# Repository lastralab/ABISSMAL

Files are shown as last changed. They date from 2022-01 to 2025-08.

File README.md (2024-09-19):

<h1>ABISSMAL: Automated Behavioral tracking by Integrating Sensors that Survey Movements Around a target Location
</h1>
<b>Developers:</b><br>
Tania Molina: <span style="pointer-events:none;">tanismo&#64;l<span style="display:none"></span>astralab.com</span><br>
Grace Smith-Vidaurre, PhD: <span style="pointer-events:none">gsvidaurre[at]<span style="display:none"></span>gmail.com</span>
<br>
<br>
<a href="https://lastralab.github.io/ABISSMAL/site/" target="_blank">Documentation</a><br />
<a href="https://github.com/lastralab/ABISSMAL/wiki" target="_blank">Project Wiki</a>
<br />

<h2>Tracking System Overview</h2>
ABISSMAL is a hardware and software platform for automated behavioral tracking with built-in system monitoring and error logging. ABISSMAL also provides the capacity to make behavioral inferences by integrating data across multiple types of movement sensors. We tested the tracking system by tracking parental care behaviors with captive zebra finches that raised young birds over 50 days. See the accompanying methods manuscript for more detailed information about ABISSMAL. Our Wiki page has detailed information about how to set up and build hardware, as well as software installation and troubleshooting.

<h2>Pre-requisites</h2>
Please refer to our Wiki page <a href="https://github.com/lastralab/Abissmal/wiki/2.-Set-up-Raspberry-Pi-and-tracking-system-software">Set up Raspberry Pi and tracking system</a> before proceeding. There are a few pre-requisites to consider before running the installation script.

<h2>Installing ABISSMAL</h2>
<br>

<pre>
           ____ _____  _____ _____ __  __          _      
     /\   |  _ \_   _|/ ____/ ____|  \/  |   /\   | |     
    /  \  | |_) || | | (___| (___ | \  / |  /  \  | |     
   / /\ \ |  _ < | |  \___ \\___ \| |\/| | / /\ \ | |     
  / ____ \| |_) || |_ ____) |___) | |  | |/ ____ \| |____ 
 /_/    \_\____/_____|_____/_____/|_|  |_/_/    \_\______|

</pre>

<ol>
<li>Clone this repository to the Pi by running <pre>git clone https://github.com/lastralab/Abissmal.git</pre></li>
<li>From the root directory `/path/to/Abissmal/` run the following commands to install and run the ABISSMAL tracking system:</li>

   <ol>

   <li>Initiate the installation script, which will prompt you to enter information <pre>sudo bash run_install.sh</pre></li>
   <li>Enter your Pi password (we strongly recommend setting a password for your Raspberry Pi)</li>
   <li>When prompted, insert the additional ABISSMAL setup information accordingly</li>
   <li>The Pi will restart automatically to apply changes</li>
   <li>If you are using an ssh connection to connect to the Pi, then you will need to <a href="https://github.com/lastralab/Abissmal/wiki/5.-Troubleshooting">mount the external hard drive</a></li>
   </ol>
<li>Run command to initiate ABISSMAL and start collecting data (wihout sudo) <pre>bash Main.sh</pre></li>
<ol>
              <li>Follow instructions to setup the system accordingly</li>
   </ol>
</ol>
<br>

<h2>File Structure Overview</h2>
This repository holds the following directories and files. See the README files in each directory below for more detailed information:

<h3>3D</h3> A directory that holds 3D-printing designs for customized hardware in .stl format. Some of these files were used in earlier versions of ABISSMAL (RFID antenna holder) and are not currently used.

<h3>Modules</h3> A directory that holds software modules in Python 3 and the bash shell for automated data collection and system monitoring, as well as software for error logging. 

<h3>R</h3> A directory that contains a series of computational analyses as R functions, as well as code for unit-testing these functions.

<h3>Video Concatenation</h3> A directory that holds scripts for video concatenation with ffmpeg. This code was originally written to merge pre- and post-motion detection videos but is currently not used in ABISSMAL.

<h3>Main.sh</h3> The main script that initiates the ABISSMAL tracking system. See the Wiki page for more information.

<h3>cron.sh</h3> A script for task scheduling through cron jobs. This script is automatically used by ABISSMAL for data collection, system monitoring, and error logging to run continuously over time.

<h3>run_install.sh</h3> A script for automated installation of software dependencies, setting up cron jobs, and setting up automated text alerts through Twilio (optional, and users will need to create their own Twilio account). See the Wiki page for more information. 

<h3>Issue templates and other files</h3> The directory .github/ISSUE_TEMPLATE contains templates for different types of issues. The file .gitignore contains information about which files should be ignored (not tracked) by Git. The LICENSE file holds information about the open-access license for this repository. The README.md file holds this documentation for the main repository.

<br>

<h2>Additional Documentation</h2> The Issues tab holds open issues (bugs, new features, documentation update requests) that are in progress. You can also check out issues that were closed over time. The Projects tab has a Kanban-board style timeline that we are using for project management. The Wiki tab has 5 major sections with detailed documentation: <br />
<ol>
<li>Project Management</li>
<li>Setting up Raspberry Pi computers and ABISSMAL software</li> 
<li>Building a custom nest container</li> 
<li>Setting up sensors and other hardware</li> 
<li>Troubleshooting software and hardware issues</li>
</ol>
<h2>Citing ABISSMAL</h2>
If you are using or modifying one or more components of the ABISSMAL tracking system, then please cite the associated methods paper.

<br>
Paper citation: <br>
   Smith-Vidaurre, G., Molina, T., Jarvis, E.D., and Hobson, E.A. (2023). Automated tracking of avian parental care behavior. Submitted. EcoEvoRxiv preprint: https://doi.org/10.32942/X2Z60C

<h2>Reporting issues while using ABISSMAL</h2>
Anyone using ABISSMAL is welcome to post issues about bugs. We will do our best to respond and help with bugs, but our top priority will be to fix bugs that hinder data collection, system monitoring, error logging, data cleaning, and processing for the current version of ABISSMAL. 

<br>
This tracking system can be modified for different questions that require behavioral tracking, as well as for different species and/or research settings. Those interested in modifying the system for other purposes are welcome to do so independently, as long as you cite both the associated methods paper (currently a preprint), and this GitHub repository. Unless we have come to an agreement with collaborators who are adapting ABISSMAL, we will not have time to help individuals or research teams modify the tracking system. 

<h2>Contributing to ABISSMAL as an open-access tool</h2>
We have laid out collaborative roles for contributing to ABISSMAL code development in our <a href="https://github.com/lastralab/Abissmal/wiki/1.-Project-Management">Wiki Project Management page</a>. Contributing to ABISSMAL code development requires a local version of all components of the tracking system, including sensors and other hardware. As such, we are limiting ABISSMAL code contributions to the current developers (Tania Molina, Grace Smith-Vidaurre) and future members of the Smith-Vidaurre lab who will have access to the full set of hardware needed to test code. The lab may add additional layers of data collection and processing in future releases of ABISSMAL. We recommend that others who interested in modifying ABISSMAL fork this repository as a foundation for independent customization.

<h2>Ethics Statement</h2>
We developed and tested this tracking system with an institutional animal care and use (IACUC) protocol that was approved for captive zebra finches by Rockefeller University. If you plan to use this tracking system for research with live animals (captive or wild), then you must have your own approved institutional protocols and permits for ethical and responsible use of animals in research.

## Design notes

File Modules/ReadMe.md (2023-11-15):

<h1>Software documentation</h1>

<h2>System monitoring, error loggin, helper functions</h2>

**Description**: The files monitor.py and Backups.py are used for system monitoring and transferring data from the Pi to an external hard drive. Data transfers are performed at night for files created the day before. The file log.py is used for error logging, while helper.py contains functions for writing .csv files, setting up directories and logging, and setting up Twilio text alerts.

<h2>Infrared beam breakers (IRBB.py)</h2>

**Description**: IRBB.py contains code to run and collect data from two pairs of infrared beam breakers. Each beam breaker is a receiver - emitter pair. The code contained in IRBB.py was modified from from https://simonprickett.dev/using-a-break-beam-sensor-with-python-and-raspberry-pi/. The outer beam breaker pair is the first that will be broken when a bird enters the nest container (this pair sits in front of the RFID antenna). The inner beam breaker pair should be the first beam that is broken when a bird leaves the nest chamber (this pair sits behind the RFID antenna, looking into the container).

**Data structure**: The function `detect_beam_breaks_callback(BEAM_PIN, sensor_id)` returns the date and timestamp (HH:MM:SS) when an infrared beam is broken. The IRBB.py script returns the nest container identifier, the beam breaker identifier (outer or inner), and the year, month, day, and timestamp (HH:MM:SS) of the movement event. Each of these fields will be written out as a new line of a .csv file generated per day. The beam breakers detect beam breaking events through edge detection. This code sets up a pull up resistor to detect a falling edge that represents a beam break. Edges are detected by adding events rather than constant polling (to avoid missing edges). The bouncetime parameter ensures that only a single edge will be detected even when multiple beam break events occur close together in time.

<h2>Radio frequency identification (RFID.py)</h2>

**Description**: RFID.py contains code to run and collect data from a 125kHz CognIot radio frequency identification (RFID) reader on a Raspberry Pi computer. The original code to control the RFID reader was obtained from https://github.com/CognIot/RFID_125kHz. The RFID reader is connected to an external circular antenna that sits at the entrance of the tunnel of the nest container (before both infrared beam breakers). The reader has been set to read EM4102 passive integrated transponder (PIT) tags held in a plastic leg bands made in sizes appropriate for different songbird species. This RFID system allows for identification of the individuals that enter and leave the nest container. We set up the RFID antenna in the center of the nest container entrance, between the two beam breaker pairs.

**Data structure**: The function in RFID.py `ReadTagPageZero(comms)` returns the nest container identifier, the PIT tag code (a unique 16-bit alphanumeric string), and the year, month, day, and timestamp (HH:MM:SS) of the movement event. Each of these fields will be written out as a new line of a .csv file generated per day.

<h2>Temperature sensor (Temp.py)</h2>

**Description**: Temp.py contains code to run and collect data from a waterproof 1-wire DS18B20 temperature sensor on a Raspberry Pi computer. The original code to control the temperature sensor was obtained from https://learn.adafruit.com/adafruits-raspberry-pi-lesson-11-ds18b20-temperature-sensing/software, a tutorial written by Simon Monk. The sensor will provide temperature data from inside the nest chamber, but will not provide incubation temperature unless strategically placed to do so (which may be complicated by the fact that some birds continue to add nesting material and can bury the sensor, and also by chicks leaning on the probe as they grow larger).

**Notes on usage**: The sensor must be connected to 3.3V for power and GPIO pin 4 for 1-wire data transfer. A single sub-folder per device should appear inside /sys/bus/w1/devices that starts with 28 after initial setup (see link above), ptherwise something is not connected correctly (e.g. when multiple folders appear that start with 00-). The script Temp.py must be executed with python3, otherwise some code will fail (e.g. the file = f statement in the print calls). May need to rerun setup of /w1 folder as in https://pimylifeup.com/raspberry-pi-temperature-sensor/ every time the Raspberry Pi computer restarts.

**Data structure**: The function in `read_temp()` returns the nest container identifier, the temperature value in degrees Celsius and degrees Farenheit, and the year, month, day, and timestamp (HH:MM:SS). Each of these fields will be written out as a new line of a .csv file generated per day.

<h2>Video (Video.py)</h2>

**Description**: Video.py contains code to record videos by motion detection from a Raspberry Pi (H) infrared fisheye lens camera with infrared LEDs. Other cameras compatible with Raspberry Pis may also be used (we initially developed this code with a non-infrared Waveshare (G) camera). The camera is continuously streaming and monitoring the number of pixels that change color in all 3 color channels from one frame to another. Videos will be recorded when the number of pixels that changed color passes beyond a given sensitivity threshold. We use a ring buffer to record a video a few seconds before movement occurred, and another video immediately after movement occurred. The videos are recorded in h264 format and converted to mp4 format.

**Notes on usage**: Since video data is computationally intensive to record, and expensive both to store and score, videos will be recorded using a high sensitivity threshold for motion detection. We ran some tests by placing the camera on a desk and walking and sitting nearby, and later with live birds. The sensitivity vs pixel difference is getting logged every time the pixel difference gets higher than the sensitivity threshold. Our test results provided an ideal sensitivity value of 9000 pixels (about 1% of all total pixels). You can trace pixel values that triggered video recordings in the daily log files and modify the sensitivity parameter according to your needs.

**Data structure**: Video.py returns a spreadsheet of metadata about the videos recorded each day. The metadata includes the nest container identifier, as well as the year, month, day, and timestamp (HH_MM_SS) of the moment that motion was detected, whether the video was recorded pre or post-motion detection, the video file names, the pixel sensitivity threshold, and the number of pixels that changed during motion detection. This script will also return videos in .mp4 format as described above.

<h2>Validation videos (alt_video.py)</h2> 
**Description**: The file alt_video.py was written to provide video recording for validating ABISSMAL. This script provides the capacity to record videos continuously throughout a given time period without motion detection. This code was written for use on a Raspberry Pi computer that is connected to a camera only. Currently alt_video.py cannot be run on a Raspberry Pi computer that is also collecting beam breaker, RFID, and/or motion-detection video recordings. To configure validation videos you can skip steps 1.7 and 1.9 from the Wiki page "Set up Raspberry Pi and tracking system software", since alt_video.py will not use GPIO connections.

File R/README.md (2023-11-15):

# General documentation for data processing and integration functions

`ABISSMAL` includes a set of functions to process raw data and integrate pre-processed data across movement sensors in order to make behavioral inferences about movement events. 

**Hardware requirements**: These functions were written for a specific hardware setup in which 3 types of movement sensors are mounted around the entrance of a nest container in the following order:

- Outer pair of beam breakers (just outside of the nest container entrance and in front of the RFID antenna)
- Radio frequency identification (RFID) antenna (in the middle of the nest container entrance, between the two pairs of beam breakers)
- Inner pair of beam breakers (just inside of the nest container entrance and behind the RFID antenna)
- Infrared camera (mounted on top of the nest container for a bird's-eye view of the nest inside)

**Descriptions of each function**:

See more detailed information about how these functions work in the accompanying methods paper as well as in the `.R` scripts for each function.

1. `combine_raw_data.R`: Combine raw data collected over time into a single spreadsheet per sensor type (RFID, beam breakers, video recording events, as well as temperature) and experimental setup.

2. `detect_perching_events.R`: Detect bouts of perching events in the raw RFID or infrared beam breaker data.

3. `preprocess_detections.R`: Pre-process the raw RFID or beam breaker data using two possible filtering modes based on temporal rules, or pre-process video data by using the magnitude of movement (e.g. the number of pixels that triggered video recording) to filter detections.

4. `find_clusters.R`: Identify clusters of detections across one or more sensors that occurred close together in time.

5. `score_clusters.R`: Generate behavioral inferences about each clusters of detection, and integrate perching events from RFID and/or beam breaker data as needed.

The 5 functions above are numbered by the order in which they should be used for data processing and analysis. All of these functions must be implemented across experimental setups if `ABISSMAL` was used to collect data across serial or parallel experimental replicates. The majority of these functions were written to process data collected across movement sensors. The function `combine_raw_data_per_sensor` concatenates raw temperature data over time, but this temperature data should not be used as input for subsequent functions. Finally, the file `utilities.R` contains utility functions that are used to check formal arguments and data in each of the functions above. 

**Usage** See code provided in the GitHub repository `gsvidaurre/ABISSMAL-methods-paper` (https://github.com/gsvidaurre/ABISSMAL-methods-paper) for examples about how these functions can be used to process and integrate data to make behavioral inferences.

**Automated unit testing**: The directory `~/tests/testthat` holds automated tests of function behavior and error handling for each of the functions above. These automated tests should be run across functions using the script `run_all_testthat_tests.Rmd` whenever one or more functions are updated. This unit testing relies on simulated datasets in order to ensure that the functions are performing as expected.

**Assumptions about sensor triggering events and behavioral inferences**: In the hardware setup above, the outer pair of beam breakers and the camera should be the first and last sensors to trigger when an animal enters the nest container, respectively. When an animal leaves the nest container, this order should be reversed. However, these assumptions are complicated by the fact that individuals can sit inside the circular entrance for longer periods of time (triggering not only the RFID antenna but also the beam breakers and camera with fine-scale movements). In addition, individuals can also enter and exit the nest container with individual variation in the speed and angle at which they enter, which can lead to failure to detect movement by one or more sensors. Finally, since multiple individuals can be inside the container at any point in time, video recording events may be triggered by movements from more than one individual.

**Using sensor triggering events to score direction**: The `score_detectionClusters` function scores the direction of movement by detecting edges or transitions in sequences of sensor labels in each cluster. For the first edge in each detection cluster, the function uses rules about which sensor triggered first in order to label direction. For instance, if a detection cluster contains the sequence of events "RFID", "RFID", "RFID", "Outer Beam Breaker", then the edge "RFID-Outer Beam Breaker" would be scored as an exit, since the RFID antenna triggered first. This directional scoring by edge detection imposes minimal assumptions about how sensor triggering events map onto the direction of movements, but still requires validation with datasets of known movement direction.

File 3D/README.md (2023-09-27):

# 3D Designs

### .stl Models ready for 3D printing

1. Nest entrance model (bobbin)
   * Used to make the antennas for RFID
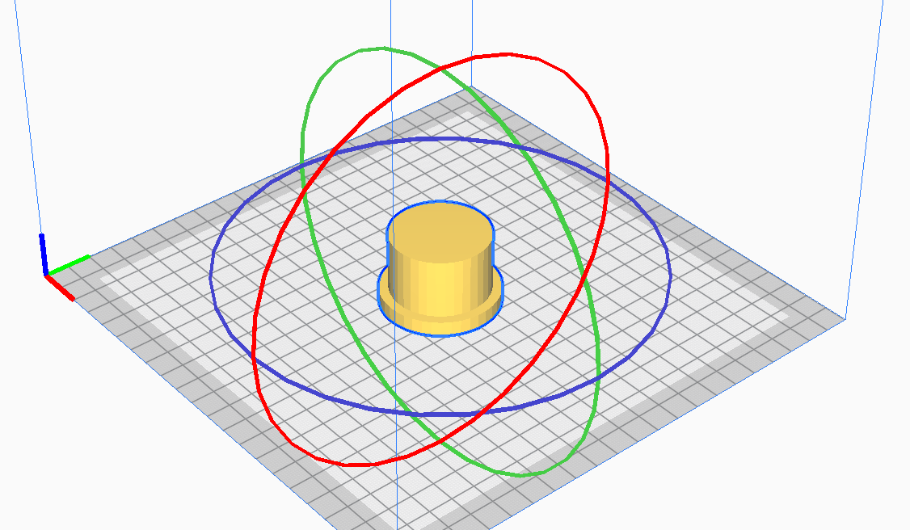
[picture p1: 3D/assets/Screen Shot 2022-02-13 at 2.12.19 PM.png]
   * 
2. Antenna Cover
   * To protect the antenna from dust and other elements
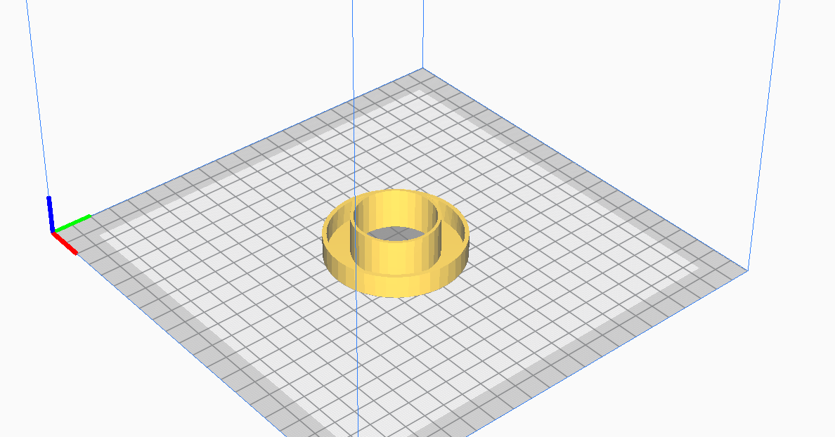
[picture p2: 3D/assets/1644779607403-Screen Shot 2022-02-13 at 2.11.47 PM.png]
   * 
3. Camera Holder
   * Also serves as the nest container cap
   * Holds the camera and provides light and ventilation
   * Compatible with Arducam Lens Board and RPi NoIR Camera V2.
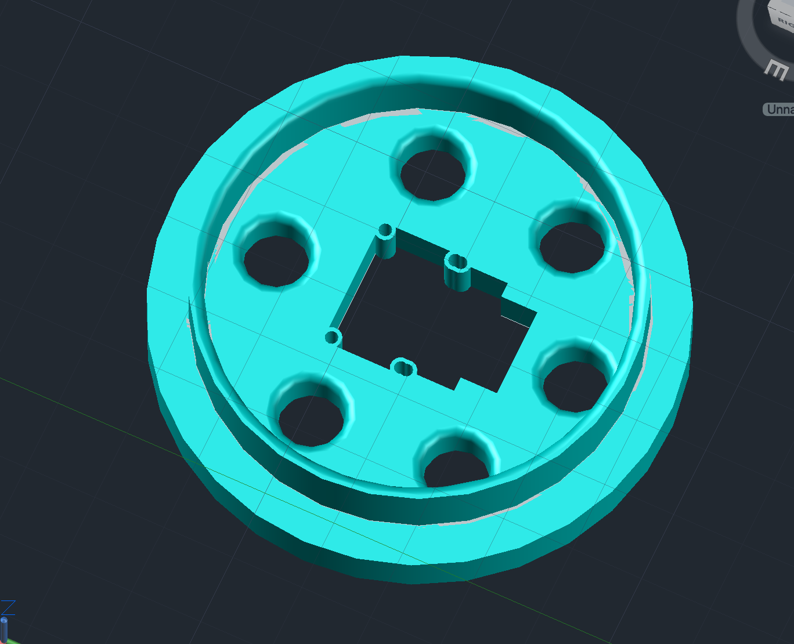
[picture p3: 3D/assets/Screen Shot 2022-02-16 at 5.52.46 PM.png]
   * 

4. IR Camera Holder
   * 
   
5. IR Camera holder for validation videos
   * Camera can be zip-tied to the cage
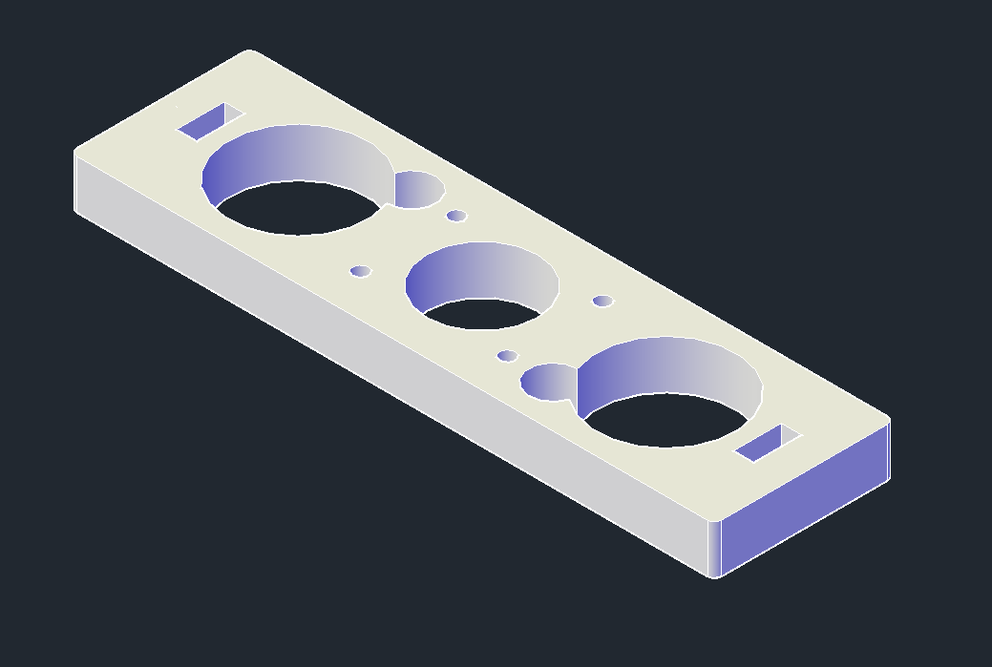
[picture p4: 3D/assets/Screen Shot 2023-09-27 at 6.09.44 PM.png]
Screen Shot 2023-09-27 at 6.09.44 PM.png
   * 
   
6. IR Camera holder template
   * Location: 3D/assets/camera_template.dwg
   * AutoCAD format .dwg ready to be manipulated according to your needs
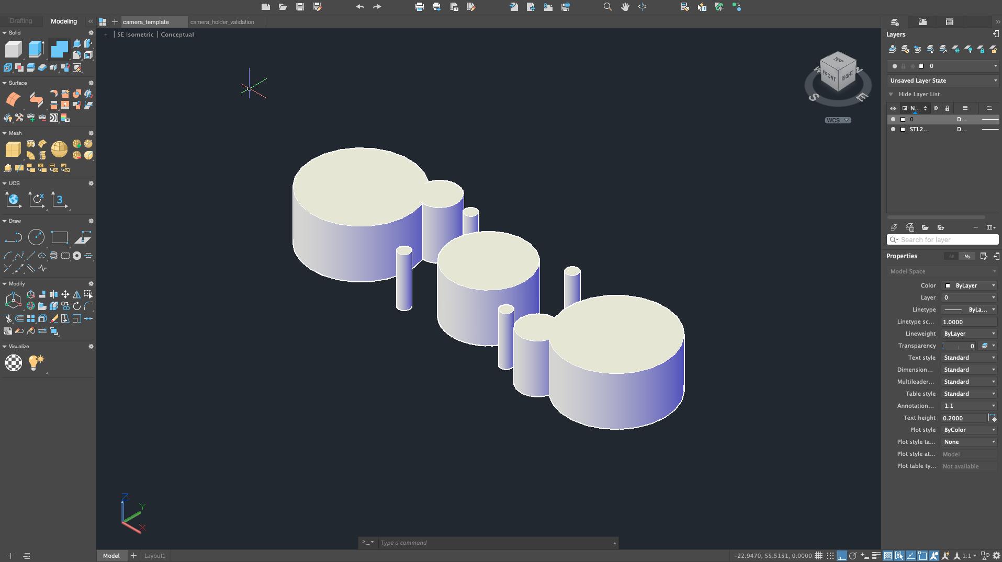
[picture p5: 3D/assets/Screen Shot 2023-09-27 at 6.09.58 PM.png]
Screen Shot 2023-09-27 at 6.09.58 PM.png
   *

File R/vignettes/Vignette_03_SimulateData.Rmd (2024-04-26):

---
title: "Vignette 03: Simulate Data"
author: "Grace Smith-Vidaurre"
date: "2023-12-27"
output: 
  html_document:
    css: "styles.css"
    toc: true
    toc_float: true
    toc_depth: 4
---

```{r setup, include = FALSE}

knitr::opts_chunk$set(echo = TRUE, eval = TRUE)

```

<h2>Vignette overview and learning objectives</h2>

In this third vignette, we will create simulated datasets of animal movements detected by different sensors. Simulating these datasets replaces the data collection process pipeline used by ABISSMAL to collect data from live animals. Generating simulated datasets will provide you more opportunities to practice basic coding skills, and will also allow you to have more control over the process of data collection in order to understand the subsequent data analysis steps. If you want to see movement detection datasets collected from live birds with ABISSMAL, and the code used to analyze those datasets, then check out the [methods manuscript preprint](https://ecoevorxiv.org/repository/view/6268/) that has links to publicly available data and code.

Throughout the process of creating simulated datasets in this vignette, you will continue to use coding skills that you learned in vignette 02, and you will learn additional skills that include:

1. Creating objects like vectors and data frames
2. Data types in R
3. Indexing and manipulating objects
4. Using conditional statements
5. Piping expressions through the tidyverse

<h2>Load packages</h2>

In the previous vignette, you installed a set of data science packages called the `tidyverse`. You also learned about working directories and created a directory on your computer to save the data or image files that you generate across vignettes.

Whenever you start a new RMarkdown file or R script, it's important to set up your virtual workspace before starting data analysis. In the chunk below, you will clean your global environment and load the tidyverse. This is code that you already saw in vignette 02, but now these lines of code are together in one chunk.
```{r message = FALSE, warning = FALSE}

rm(list = ls()) # Clean global environment

library(tidyverse) # Load the set of tidyverse packages

```

<h2>Create a path object</h2>

The next step is to specify your working directory. In vignette 02, you used a string (text contained in double quotes to indicate a character string used inside of R code) to specify your working directory while using different functions. Using the same long character string over and over is a lot of copy-pasting. Instead, you can save the character string for your working directory as a new object in R.

You can create a `path` object by writing out the name of the object on the left (without quotes), then the object creation symbols `<-`, and then the information that you want to store in this object (your working directory as a character string in quotes).
```{r eval = TRUE}

path <- "/home/gsvidaurre/Desktop/ABISSMAL_vignettes"

```

In the code above, you created an object called `path`. You can see contents of the object `path` by writing out the object name and running that code in the console:
```{r eval = TRUE}

path

```

You can also see the contents of `path` by clicking on the "Environment" tab and checking out the column to the right of the object name. `path` is a new object that holds information about your working directory, and it's available in your global environment for future operations.

You can practice removing the `path` object from your global environment by writing and running the code `rm(list = "path")`. After doing this, make sure to recreate `path` using the code above.

<h2>Create timestamps of simulated detections of animal movements</h2>

The primary data collected by the ABISSMAL tracking system are timestamps indicating the moment of time when a sensor activated and recorded movement. Many (but not all) of these detections can be attributed to one or more animals moving near a sensor, such as a bird moving through a radio frequency identification (RFID) antenna mounted in the entrance of a nest container. In the subsequent code chunks, we will generate simulated data that represent RFID and infrared beam breaker detection datasets. 

In this simulated example, let's assume that we're collecting data for 2 adult birds at a nest container. The RFID antenna is mounted in the entrance of nest container. One pair of infrared beam breakers, the "outer" pair, is mounted in front of the RFID antenna to catch movements just outside of the container entrance. A second pair of infrared beam breakers, the "inner" pair, is mounted behind the RFID antenna to catch movements just inside of the container entrance. In this simulated setup, the outer beam breakers will activate when a bird enters the nest container, followed by the RFID antenna and the inner beam breakers. When a bird leaves the nest container, the inner beam breakers should activate first, followed by the RFID antenna and then the outer beam breakers.

We will start by creating an object that holds simulated timestamps for the RFID antenna. This object will be called `rfid_ts`, and it will hold 4 timestamps in hours:minutes:seconds format. Each timestamp will be surrounded by double quotes to denote that we are using text or character string information here. 

These timestamps are combined inside of the same object by using the function `c()`. This function `c()` concatenates values separated by commas into a vector or list object. Above you created an object called `path` without using `c()`, but that object had a single value. Using `c()` allows you to combine multiple values into a vector that will have more than 1 element.
```{r}

# Create a vector of 4 RFID timestamps or 4 elements in HH:MM:SS format
rfid_ts <- c("10:00:00", "10:05:00", "11:00:00", "11:05:00")
  
```

You can check out the different properties of the `rfid_ts` object after it's made:
```{r}

rfid_ts # Run the object name to see its contents

is.vector(rfid_ts) # A binary value indicating that rfid_ts is a vector

class(rfid_ts) # A vector with data of type "character"

length(rfid_ts) # This vector has 4 elements

```

Let's continue by simulating 2 entrance and 2 exit movement events. We can choose timestamps for the outer pair of infrared beam breakers that precede the RFID timestamps and timestamps for the inner beam breaker pai that follow the RFID antenna to simulate an entrance event. We can simulate detections by these sensors in the opposite order (inner beam breakers, then RFID, followed by the outer beam breakers) to simulate an exit event. We will offset detections from each sensor within the entrance and exit movement events by 1 second.
```{r}

# Simulate outer and inner beam breaker timestamps for an entrance, an exit, and then another entrance and exit
o_irbb_ts <- c("09:59:59", "10:05:01", "10:59:59", "11:05:01")
i_irbb_ts <- c("10:00:01", "10:04:59", "11:00:01", "11:04:59")

```

Birds will sometimes perch in the nest container entrance, and the sensors should pick up this behavior. You can add some perching events to the simulated dataset. Here we will simulate perching events for the RFID data only.
```{r}

rfid_ts <- c(rfid_ts, "08:00:00", "08:00:01", "08:00:02", "08:00:03", "11:30:00", "11:30:01", "11:30:02", "11:30:03", "11:30:04", "11:30:05")

```

In the code above, we modified the object `rfid_ts` by using the function `c()` to add 10 more timestamps to this vector, for a total of 14 elements. Check out the structure of the modified `rfid_ts` object using the function `glimpse()`:
```{r}

# See the object structure in a format that includes the data type ("chr"), the number of elements ([1:14]), and a preview of the first few elements
glimpse(rfid_ts)

```

Another important type of information to simulate is noise in the sensor detections. For instance, the RFID antenna can fail to detect an individual's passive integrated transponder (PIT) tag, and the infrared beam breakers can activate when birds leave nesting material hanging in the entrance of the container. In both of these cases, the infrared beam breakers should activate when the RFID antenna does not.
```{r}

# Simulate some RFID detection failures across both beam breaker pairs
# These RFID detection failures occurred over 2 additional simulated entrances and 2 additional simulated exits
o_irbb_ts <- c(o_irbb_ts, "06:05:05", "06:35:08", "07:15:40", "11:10:25")
i_irbb_ts <- c(i_irbb_ts, "06:05:04", "06:35:09", "07:15:41", "11:10:24")

glimpse(o_irbb_ts)
glimpse(i_irbb_ts)

# Simulate some stray detections for the outer beam breaker
o_irbb_ts <- c(o_irbb_ts, "09:45:01", "09:45:02", "09:45:03", "09:45:04", "09:45:05", "09:45:06", "09:45:07", "09:45:08", "09:45:09", "09:45:10", "09:45:11")

glimpse(o_irbb_ts)

```

You've created simulated, noisy datasets of detections of animal movements, but currently, these datasets are encoded across separate vector objects and do not have important metadata. For instance, some useful metadata includes information about the experimental replicate, the date, and for the RFID data, the unique alphanumeric code of each PIT tag detected by the RFID antenna. Some of this metadata is critically important for downstream analyses (e.g. the date and PIT tag codes).

Vectors are useful data structures in R, but one limitation of vectors is that you cannot combine different data types into the same object. You can try this out with the code below:
```{r}

# Create a vector with character, numeric, and binary data types
# Since you're not saving the output into an object, the result will print directly to the console
# You should see that all elements are forced to be character strings in double quotes
c("1", 1, TRUE, FALSE)

# Create a vector with numeric and binary data types
# You should see that all elements have been forced to numeric. The TRUE and FALSE binary values are converted to the underlying numeric values used to store binary information (TRUE is stored as 1, and FALSE is stored as 0)
c(1, 1, TRUE, FALSE)

```

When you try to combine character, numeric, and binary data types in the same vector, all vector elements will be forced to the character data type. A similar thing happens when you try to combine numeric and binary data types, but the vector is forced to numeric. Note that the binary values TRUE and FALSE are equivalent to the numeric values 1 and 0, respectively.

<h2>Create metadata vectors</h2>

For downstream analyses, you need to be able to create metadata of different data types, and then combine the primary data for each sensor (timestamps) with this metadata. Start by creating vectors of metadata for the RFID timestamps, including information about the experimental replicate, the date, and the PIT tag identity for each detection.

Make a vector of metadata about the experimental replicate. Here, instead of writing out the same information many times, you'll use the function `rep()` to repeat the information about the experimental replicate several times. In order to set the number of times that the experimental replicate information is repeated, you'll also use the function `length()` to get the length of the `rfid_ts` vector, and then feed that result to `rep()`. Creating a metadata vector that is the same length as the `rfid_ts` vector will be useful for combining these vectors into a single object later. 
```{r}

# The documentation tells us that rep() expects two arguments, `x` and `times`
?rep

# Create a vector with information about the experimental replicate
# The argument `x` contains the metadata information that will be repeated
# The argument `times` specifies the number of times that the information will be repeated
exp_rep <- rep(x = "Pair_01", times = length(rfid_ts))

glimpse(exp_rep)

# You can also run code without writing out the argument names, as long as the arguments are written in the same order that the function expects:
exp_rep <- rep("Pair_01", length(rfid_ts))

glimpse(exp_rep)

```

Using `times = length(rfid_ts)` is better practice than manually entering the length of `rfid_ts` (e.g. `times = 14`). When you manually enter a value for `times`, you're assuming that the `rfid_ts` has not changed within and between coding sessions, which can be a dangerous assumption. By using `times = length(rfid_ts)`, you are ensuring that the code above will create a vector of metadata the same length as `rfid_ts` regardless of whether you made additional modifications to `rfid_ts` above.

You can use a conditional statement to confirm that the vector of metadata is the same length as the vector of RFID timestamps. Conditional statements can be useful ways to check assumptions in your code, or to efficiently build new datasets and functions.
```{r}

# If this condition is met, then the result in the console should be "[1] TRUE"
length(rfid_ts) == length(exp_rep)

```

In the conditional statement above, you're using the symbols `==` to ask if the two vectors `rfid_ts` and `exp_rep` are the same length.

You can also use the symbols `!=` to ask if the two vectors are *not* the same length:
```{r}

# This statement should yield FALSE, because these vectors are the same length
length(rfid_ts) != length(exp_rep)

```

As an example, you can modify `rfid_ts` so that it is a different length than `exp_rep`. Below you'll see some different ways that you can filter out 4 elements of the vector `rfid_ts` so that this vector is 10 elements long.
```{r}

## Create numeric indices for filtering an object

# You can use : to create a sequence of numbers from indices 5 to the length of rfid_ts
5:length(rfid_ts)

# You can also use the function `seq()` to create the same sequence of numeric indices
seq(from = 5, to = length(rfid_ts), by = 1)

# If you want to filter out non-consecutive elements, you can create a vector of indices with the function `c()`
c(1, 3, 5, 6, 8, 10, 11, 12, 13, 14)

## Filter an object using numeric indices

# When you put any of the expressions above inside of square brackets after the object name you will pull out elements 5 to the length of rfid_ts and drop the first 4 elements
rfid_ts[5:length(rfid_ts)]

rfid_ts[seq(from = 5, to = length(rfid_ts), by = 1)]

rfid_ts[c(1, 3, 5, 6, 8, 10, 11, 12, 13, 14)]

# Finally, you can use any of the methods above to create a sequence of indices that you want to drop, and then use the `-` symbol inside of the square brackets to remove those indices. For instance:
rfid_ts[-c(1:4)] # the numbers must be wrapped in `c()` in order for this inverted filtering to work 

```

Next, you can check whether the modified version of `rfid_ts` is the same length as `exp_rep`:
```{r}

# This statement should yield TRUE, because these vectors are not the same length
length(rfid_ts[-c(1:4)]) != length(exp_rep)

```

<h2>Create data frames with primary data and metadata</h2>

For later analyses, it is really important to have the metadata accompany your primary data in the very same object. To combine the primary data and metadata for these simulated datasets, you can rely on an object called a "data frame". Data frames are similar to spreadsheets. They have 2 dimensions (rows and columns), and you can store multiple different types of data in the same data frame. You can also write out data frames to spreadsheets that exist as physical files on your computer.

When you try making a data frame with vectors of different length, you should get an error message stating that the two arguments provided have different numbers of rows:
```{r eval = FALSE}

sim_dats <- data.frame(exp_rep, rfid_ts[-c(1:4)])

# "Error in data.frame(exp_rep, rfid_ts[-c(1:4)]) : 
  # arguments imply differing number of rows: 14, 10"

```

Now use the full `exp_rep` and `rfid_ts` vectors to create the data frame, in which these vectors become columns of the data frame:
```{r}

sim_dats <- data.frame(exp_rep, rfid_ts)

glimpse(sim_dats)

```

When you check out the structure of the new data frame `sim_dats`, you can see that it has 14 rows and 2 columns. For each column (after the "$" symbol), you can see the column name (here `exp_rep` and `rfid_ts`), the type of data in each column (both columns are type "character"), and then a preview of the first values in each column.

You can change the column names by adding a new name and `=` before each vector. Here the vector `exp_rep` becomes the column `replicate` and the vector `rfid_ts` becomes the column `timestamps``
```{r}

sim_dats <- data.frame(replicate = exp_rep, timestamps = rfid_ts)

glimpse(sim_dats)

```

We can add additional metadata to this data frame now that it's been created. For instance, it would be useful to have information about the date when these timestamps were collected. You can start by adding a column for the year, which will be data type "dbl" (which stands for "double" or "numeric"):
```{r}

sim_dats <- cbind(sim_dats, rep(2023, length(rfid_ts)))

glimpse(sim_dats)  

```

The year column has a strange name when we add the new column using `cbind()`. The column name is the expression that you wrote inside of `cbind()`. You can use the function `names()` and square bracket indexing to change the strange column name to "year":
```{r}

# This function returns a vector of the column names of the data frame 
names(sim_dats)

# Use square bracket indexing and the function `ncol()` to find the last column name
ncol(sim_dats) # There are 3 columns in this data frame

# This expression gets you the name of the last column
names(sim_dats)[ncol(sim_dats)]

# Then you can overwrite the last column name with a new name
names(sim_dats)[ncol(sim_dats)] <- "year"

# Confirm that the name was changed correctly
names(sim_dats)
glimpse(sim_dats)

```

<h2>Create data frames using the tidyverse</h2>

In the chunk above, you used base R code to add a new column and to update the column name. It took more than a few lines of code to carry out these operations. You could reduce the amount of code needed for these steps by removing the lines included to check your work. But another way that you can reduce the amount of code you're writing for these operations is to use tidyverse notation and functions:
```{r}

# Make the data frame again with only 2 columns
sim_dats <- data.frame(replicate = exp_rep, timestamps = rfid_ts)

# Use the tidyverse to add the year as the 3rd column
sim_dats <- sim_dats %>% 
  dplyr::mutate(
    year = rep(2023, length(rfid_ts))
  )

glimpse(sim_dats)

```

You added a column for the year with the correct column name in fewer lines of code. In this tidyverse syntax, the symbol `%>%` represents a piping operation, in which you're using one object as the input for a subsequent operation. Here, you're using the object `sim_dats` at the input for the function `mutate()`, which you used to create the column `year`. 

The notation `dplyr::` before `mutate()` indicates that the function `mutate()` should be sourced from the package called `dplyr`. Including the package name with 2 colons before a function name is important when there are multiple functions loaded in your global environment that have the same name. For instance, if you use other packages that also have functions called `mutate()`, and you don't specify which package you want to use, then you could end up with immediate errors (the code fails to run) or worse, you could run the wrong `mutate()` operation for a given analysis (which can lead to errors down the line that are harder to trace).

Piping operations can simplify the code that you write, so that you don't have to create as many intermediate objects. On the other hand, for the same reason it can take practice to troubleshoot piping operations, especially when they become very long. A useful way to check intermediate results within long piping operations is to include the function `glimpse()` between different piping steps:
```{r}

# Make the data frame again with only 2 columns
sim_dats <- data.frame(replicate = exp_rep, timestamps = rfid_ts)

# Use the tidyverse to add the year as the 3rd column
sim_dats %>%
  glimpse() %>% # See the structure of the first version sim_dats
  dplyr::mutate(
    # The nrow(.) expression means "get the number of rows for the current object", which in this case is sim_dats
    year = rep(2023, nrow(.))
  ) %>%
  glimpse() # See the structure of the latest sim_dats with the new column "year"

```

In the code above, you also learned a new way to repeat a value within a piping operation by using the notation '.' inside of a function, which means that you will perform the given operation (getting the number of rows) on the current object (`sim_dats`) piped into the expression (the `nrow()` function). 

You can use a similar rule of thumb to add two more columns for the month and day to the data frame:
```{r}
 
# Use the tidyverse to add the year as the 3rd column
sim_dats %>%
  glimpse() %>% # See the structure of the original sim_dats
  dplyr::mutate(
    year = 2023
  ) %>%
  glimpse() %>% # See the structure of the intermediate sim_dats with the new column year
  # Also add columns for the month and day
  dplyr::mutate(
    month = 08,
    day = 01
  ) %>% 
  glimpse() # See the structure of the final sim_dats with the additional new columns month and day

```

In the code above, you added 2 more numeric columns to the data frame and you did this without needing to use the `rep()` function. Since you piped an existing data frame into each `dplyr::mutate()` expression, the single value that you specified for each of the year, month, and day columns was automatically repeated to fill the total rows in the data frame. Specifying a single value for a new column can help reduce the amount of code that you write, but only when you truly want the same value repeated across all rows of a data frame.

You did not save these modifications that you made to `sim_dats` in an object, so the output was printed to the console only. In the next vignette, you will write out this data frame of simulated RFID and IRBB data to spreadsheets as physical files on your computer.

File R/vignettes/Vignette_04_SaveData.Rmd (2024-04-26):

---
title: "Vignette 04: Save Data"
author: "Grace Smith-Vidaurre"
date: "2023-12-27"
output: 
  html_document:
    css: "styles.css"
    toc: true
    toc_float: true
    toc_depth: 4
---

```{r setup, include = FALSE}

knitr::opts_chunk$set(echo = TRUE, eval = TRUE)

```

<h2>Vignette overview and learning objectives</h2>

In this fourth vignette, you will write out spreadsheets of simulated detections of animal movements to your computer. You will continue to use coding skills that you learned in the previous vignettes, and you'll learn additional skills that include:

1. Indexing and filtering data frames
2. Checking data frame structure with base R and the tidyverse
3. Saving objects from R as physical files on your computer 
4. Reading files from your computer into R
5. Writing and testing loops

<h2>Load packages and your working directory path</h2>

```{r message = FALSE, warning = FALSE}

rm(list = ls()) # Clean global environment

library(tidyverse) # Load the set of tidyverse packages

path <- "/home/gsvidaurre/Desktop/ABISSMAL_vignettes" # Initialize an object with the path that is your working directory

```

<h3>Create the simulated data</h3>

In the code below, you'll recreate the simulated RFID and beam breaker datasets that you learned to build in the previous vignette. Here, the code from vignette 03 has been condensed into fewer chunks:
```{r}

# Create a vector of 4 RFID timestamps in HH:MM:SS format
rfid_ts <- c("10:00:00", "10:05:00", "11:00:00", "11:05:00")

# Add perching events to the RFID data
rfid_ts <- c(rfid_ts, "08:00:00", "08:00:01", "08:00:02", "08:00:03", "11:30:00", "11:30:01", "11:30:02", "11:30:03", "11:30:04", "11:30:05")

glimpse(rfid_ts)

```

```{r}

# Simulate outer and inner beam breaker timestamps for an entrance, an exit, and then another entrance and exit
o_irbb_ts <- c("09:59:59", "10:05:01", "10:59:59", "11:05:01")
i_irbb_ts <- c("10:00:01", "10:04:59", "11:00:01", "11:04:59")

# Simulate some RFID detection failures across both beam breaker pairs
# These RFID detection failures occurred over 2 additional simulated entrances and 2 additional simulated exits 
o_irbb_ts <- c(o_irbb_ts, "06:05:05", "06:35:08", "07:15:40", "11:10:25")
i_irbb_ts <- c(i_irbb_ts, "06:05:04", "06:35:09", "07:15:41", "11:10:24")

# Simulate some stray detections for the outer beam breaker
o_irbb_ts <- c(o_irbb_ts, "09:45:01", "09:45:02", "09:45:03", "09:45:04", "09:45:05", "09:45:06", "09:45:07", "09:45:08", "09:45:09", "09:45:10", "09:45:11")

glimpse(o_irbb_ts)
glimpse(i_irbb_ts)

```

<h3>Simulate 3 days of RFID data collection</h3>

In the code below, you'll combine the vector of RFID timestamps that you made above with metadata in a data frame. This metadata will include the year, month, and day, as well as a column with 2 unique PIT tag identifiers (1 for each simulated individual), and a column with the sensor type. You should recognize some of this code from the previous vignette:
```{r}

# Make a vector for the experimental replicate
exp_rep <- rep(x = "Nest_01", times = length(rfid_ts))

# Make a vector of the PIT tag codes
# Allocate the first 4 RFID detections to the first individual, the first perching event (4 detections) to the first individual, and the second perching event (6 detections) to the second individual
# The 3 rep() expressions are combined into a single vector using the c() function
PIT_tag <- c(rep("1357aabbcc", 4), rep("1357aabbcc", 4), rep("2468zzyyxx", 6))

# Make the data frame with the experimental replicate metadata and the timestamps
sim_dats_rfid <- data.frame(chamber_id = exp_rep, timestamps = rfid_ts)

# Overwrite the data frame with the modified version that has columns for the year, month, and day
sim_dats_rfid <- sim_dats_rfid %>%
  dplyr::mutate(
    year = 2023
  ) %>%
  dplyr::mutate(
    month = 08,
    day = 01
  ) %>%
  # Add the PIT tag metadata as a new column
  dplyr::mutate(
    PIT_tag = PIT_tag
  ) %>% 
  dplyr::mutate(
    sensor_id = "RFID"
  )

glimpse(sim_dats_rfid)

```

Next, you can use this data frame to simulate data collection over more than one day. To create more observations (rows) for two additional days, you can append rows from a modified copy of `sim_dats_rfid` to itself. 

In the code below, you're piping `sim_dats_rfid` into `bind_rows()`, which indicates that this is the original object to which you want to append or add new rows. Then the code inside of `bind_rows()` indicates the data frame (the new rows) that will be appended to `sim_dats_rfid`. In this case, the code inside of `bind_rows()` pipes `sim_dats_rfid` into `dplyr::mutate()`, which is a function that you're using to modify the `day` column to reflect a subsequent day of data collection. Then you'll repeat this process to simulate a third day of data collection:
```{r}

sim_dats_rfid <- sim_dats_rfid %>% 
  bind_rows(
    sim_dats_rfid %>% 
      dplyr::mutate(
        day = 02
      )
  ) %>% 
  bind_rows(
    sim_dats_rfid %>% 
      dplyr::mutate(
        day = 03
      )
  )

glimpse(sim_dats_rfid) # Triple the number of rows, looks good

```

<h3>Check data frame columns with base R</h3>

You checked that simulated data frame has data collected over three days by looking at the structure of the new object. You can also check the unique values present in the column `day`. Below is a way of checking the unique values contained in a column of a data frame, using two different examples of base R notation for accessing columns:
```{r}

# The name of a data frame object, followed by a $ sign and then the name of a column allows you to pull out one column at a time from a data frame. A data frame column is a vector, so when you run this code you will see a vector of values print to the console
sim_dats_rfid$day

# You can also access a column in a data frame by using double square brackets after the name of the data frame, and placing the column name in quotes inside of the inner brackets
sim_dats_rfid[["day"]]

# You can use the function unique() to see the unique values of any vector, including a column of a data frame
unique(sim_dats_rfid$day) # Three days, looks good

unique(sim_dats_rfid[["day"]]) # Three days, looks good

```

<h3>Check data frame columns with the tidyverse</h3>

You can also check the unique values in a column using functions from the tidyverse. In the expression below, you're piping `sim_dats_rfid` into the function `pull()`, which lets you pull the column `day` out of the data frame as a vector. Then that vector is piped into the function `unique()` to check the unique values contained within it. The function `unique()` does not need an argument inside of the parentheses here because you're already piping the output that it needs directly into the function.
```{r}

# Three days, looks good
sim_dats_rfid %>% 
  pull(day) %>% 
  unique()

```

<h3>Simulate 3 days of beam breaker data collection</h3>

Next, repeat this process of creating a data frame with metadata for the infrared beam breaker datasets. Since the beam breakers do not collect unique individual identity information, you will add columns for the year, month, day, and sensor type. You will also simulate data collection for the beam breakers over the same three days as the RFID system.
```{r}

# Overwrite the vector exp_rep with a new vector the same length as o_irbb_ts and i_irbb_ts together
exp_rep <- rep(x = "Nest_01", times = length(o_irbb_ts) + length(i_irbb_ts))

# Here the timestamps of both beam breaker pairs have been added to the same column using c()
sim_dats_irbb <- data.frame(chamber_id = exp_rep, timestamps = c(o_irbb_ts, i_irbb_ts))

sim_dats_irbb <- sim_dats_irbb %>%
  dplyr::mutate(
    year = 2023,
    month = 08,
    day = 01,
    # Add a unique sensor identifier by beam breaker pair
    # Each unique label is repeated for the length of the vector of timestamps of each beam breaker pair
    sensor_id = c(rep("Outer Beam Breakers", length(o_irbb_ts)), rep("Inner Beam Breakers", length(i_irbb_ts)))
  )

glimpse(sim_dats_irbb)

sim_dats_irbb <- sim_dats_irbb %>% 
  bind_rows(
    sim_dats_irbb %>% 
      dplyr::mutate(
        day = 02
      )
  ) %>% 
  bind_rows(
    sim_dats_irbb %>% 
      dplyr::mutate(
        day = 03
      )
  )

glimpse(sim_dats_irbb) # Triple the number of rows, looks good

# Three days, looks good
sim_dats_irbb %>% 
  pull(day) %>% 
  unique()

```

<h2>Save a data frame as a physical file</h2>

The data frames that you create and manipulate in R can be saved as physical files in your working directory. You have many different file type options for saving data frames, but I recommend using .csv format since this file type is compatible with R, Microsoft Word, and other software. You can use the function `write.csv()` to save data frames to .csv spreadsheets on your computer:
```{r eval = FALSE}

?write.csv

```

In order to write a physical file to your working directory, you need to tell R 1) where to save the file and 2) the name of the file that you want to create. You can pass both of these pieces of information to `write.csv()` by combining your working directory path and the file name through the function `file.path()`. For this example, you'll create a test file as you practice using `write.csv()`:
```{r}

# Create a custom file name by combining the path for your working directory with the file name that you want to write out
# The function file.path() will combine both pieces of information into a single file path
rfid_file <- file.path(path, "test_file.csv")

# This object contains the location where the file will be saved, followed by the file name
rfid_file

```

Next, you can pipe the data frame to `write.csv()` and specify additional information for creating the .csv file, such as whether you want to add a column of numeric row identifiers: 
```{r eval = FALSE}

sim_dats_rfid %>% 
  # Write out the data frame as a .csv spreadsheet. Do not include row names
  #The "." below means that the function write.csv() will operate on the object that is piped in, which here is the data frame sim_dats_rfid
  write.csv(x = ., file = rfid_file, row.names = FALSE)

```

As specified in the function documentation for `write.csv()`, the function will include column names in the resulting spreadsheet by default. The function will also not append new information to the .csv if it already exists, so if you already created this file then it will be overwritten when you run the function again.

Next, you can check that `write.csv()` worked as expected by using `list.files()` to check the files in your working directory.
```{r eval = FALSE}

# List all files in the given path
list.files(path)

```

You can also use `list.files()` to customize a search with the argument called `pattern`. Using the argument `pattern` here is similar to searching for a specific word inside of a text document. The dollar sign placed after ".csv" means that you're telling the function to search specifically for all files that *end* in the pattern ".csv":
```{r eval = FALSE}

# List only files that end in the pattern ".csv" in the given path
list.files(path, pattern = ".csv$")

```

<h3>Read in a spreadsheet</h3>

You can read one these files back into R with the function `read.csv()`. In the code below, you're piping the output of `read.csv()` directly into `glimpse()` to check out the structure of the resulting data frame. The output of the code is printed to the console, but is not saved inside of an object.
```{r eval = FALSE}

read.csv(file.path(path, "test_file.csv")) %>% 
  glimpse()

```

Now that you've practiced using `write.csv()` and `read.csv()`, you can delete the temporary file that you created by feeding the `rfid_file` object to the function `file.remove()`.
```{r eval = FALSE}

rfid_file <- file.path(path, "test_file.csv")
rfid_file

file.remove(rfid_file)

```

<h2>Save simulated data for the ABISSMAL workflow</h2>

In the code below, you'll work through a pipeline to save the simulated data in the format and locations expected by the custom ABISSMAL functions. In order to use the ABISSMAL pipeline, the simulated raw data needs to be saved in a separate spreadsheet per sensor and day of data collection. These spreadsheets need to be saved inside of a folder per sensor as well. ABISSMAL will automatically save data in these ways when the tracking system is used to collect data from live animals.

<h3>Filter a data frame</h3>

In the code below, you'll practice how to use the function `dplyr::filter()` to filter rows of a data frame by day and then save a filtered data frame with `write.csv()`. To filter a data frame, you can use a conditional statement inside of the function `dplyr::filter()`:
```{r}

# Pipe the data frame into the filter() function
sim_dats_rfid %>% 
  # Filter the data frame by pulling out all rows in which the day column was equal to 1
  dplyr::filter(day == 1) %>%
  glimpse()

# Check that the filtering was done correctly by getting the unique values in the day column. Looks good
sim_dats_rfid %>% 
  dplyr::filter(day == 1) %>%
  pull(day) %>% 
  unique()

```

You can obtain similar results by inverting the conditional statement inside of `dplyr::filter()` to remove days that are **not** the second or third days of data collection. Below you added two conditional statements together using the symbol "&".
```{r}

sim_dats_rfid %>% 
  # Filter the data frame by pulling out all rows in which the day column was not equal to 2
  dplyr::filter(day != 2 & day != 3) %>%
  glimpse()

# Check that the filtering was done correctly by getting the unique values in the day column. Looks good
sim_dats_rfid %>% 
  dplyr::filter(day != 2 & day != 3) %>%
  pull(day) %>% 
  unique()

```

Now that you've practiced filtering a data frame, you can combine this filtering step with writing out a .csv file that contains the filtered data frame with data collected on a single day:
```{r eval = FALSE}

# Make a new directory inside of your working directory for saving data
file.path(path, "Data") # Check the new path
dir.create(file.path(path, "Data")) # Create the new path

# Then make a new directory inside of the Data folder for the raw RFID data
file.path(path, "RFID") # Check the new path
dir.create(file.path(path, "Data", "RFID")) # Create the new path

# Make the new file name with your working directory path
# Make sure to specify that the spreadsheet will be saved inside of the new folder "RFID"
rfid_file <- file.path(path, "Data/RFID", "test.csv")
rfid_file

# Filter the simulated RFID data to pull out the first day of data collection
sim_dats_rfid %>% 
  dplyr::filter(day == 1) %>% 
  # Write out the filtered data frame as a .csv spreadsheet. Do not include row names
  # Remember that the "." means the function will use the object that is piped in, which here is the data frame filtered to retain day 1 of data collection only
  write.csv(x = ., file = rfid_file, row.names = FALSE)

```

Check that the test file was created inside of the new RFID folder, and then delete it.
```{r eval = FALSE}

list.files(file.path(path, "Data/RFID"), pattern = ".csv$")

rfid_file <- file.path(path, "Data/RFID", "test.csv")
rfid_file

file.remove(rfid_file)

```

<h3>Practicing writing a loop</h3>

In order to write out a data frame for each day of data collection per sensor, you could repeat the code above 6 times (three times per sensor). But it's good to avoid repeating the same code over and over, since this can lead to messy scripts as well as a greater risk for errors in data processing and analysis. Whenever you need to run the same code many times, you can write a loop. Loops are an important coding skill and we'll work through building a loop step by step.

To start, you can practice building a loop with the function `lapply()`.
```{r}

?lapply

# Make a vector of the files to write out
files <- c(file.path(path, "Data/RFID", "test1.csv"), file.path(path, "Data/RFID", "test2.csv"))

files
length(files)

```

Next, you can start writing out a looping structure. In the code below, the argument `X` specifies the number of times that the loop will run. In this case, `X` is a numeric vector from 1 to the length of the `files` vector and contains the numbers 1 and 2. Therefore the loop will run twice, and each value in `X` will be used in each loop iteration to write out one file at a time

The argument `FUN` is a custom function, written using the `function(x){}` notation. All of the code inside of the curly brackets `{}` will be run for each iteration of the loop. The argument `x` inside `function()` is the iterating variable, or the variable that will take on a different value of the vector supplied to `X` in each iteration of the loop.
```{r}

# In this loop, the iterating variable x will take on each value in the vector supplied to the X argument. This means that in the first loop iteration, x will take on the numeric value of 1. In the second loop iteration, x will hold the numeric value 2. To test that this is true, you can run the loop below, which will print the value of x per iteration to the console
lapply(X = 1:length(files), FUN = function(x){
  
  x
  
})

```

As you can see, the output of this loop is a list with 2 elements. Each list element is shown in double square brackets ([[1]] and [[2]]), and each list element contains a vector of length 1 that holds the value of the iterating variable in each iteration (1 and 2, respectively). 

The iterating variable of the loop, or `x`, does not exist as an object outside of the function. So if you print `x` outside of the loop, no object will be found. If you created a object called `x` outside of the loop above, then you will see the contents of that object instead. This means that writing a loop that uses `x` as an iterating variable will not affect other lines of code that use an object called `x` outside of the loop, and vice versa.

The iterating variable of a function does not always need to be `x`, but can be another letter (`i`, `j`, `y`, `z`) or any combination of multiple letters and numbers, underscores, and periods (as long as the variable name starts with a letter).

A useful property of the iterating variable is that you can use it to index vectors, data frames, or other objects that you created outside of the loop. For instance, you can use `x` and square bracket indexing to print the name of each file that you want to save:
```{r}

lapply(X = 1:length(files), FUN = function(x){
  
  files[x]
  
})

```

You can also modify the code inside of the custom function to save each of these files, by placing the expression `files[x]` inside of the `write.csv()` function and piping a data frame to `write.csv()`.
```{r eval = FALSE}

lapply(X = 1:length(files), FUN = function(x){
  
  # In each iteration of the loop, you will save the data frame `sim_dats_rfid` as a separate spreadsheet with the file name specified in the given iteration
  sim_dats_rfid %>%
    write.csv(file = files[x], row.names = FALSE)
  
})

```

You should see 2 "NULL" outputs printed to the console if the loop runs correctly. When you check the contents of the nested RFID folder, you should see that both of the testing .csv files were written out:
```{r}

list.files(file.path(path, "Data/RFID"))

```

You just wrote out 2 spreadsheets using 1 loop, but you wrote out the same data frame to each spreadsheet. In order to write out a different data frame to each spreadsheet, you can add the data frame filtering that you learned above to the loop. In the code below, you'll also create another vector object called `days`, and then use the iterating variable to filter `sim_dats_rfid` and write out a spreadsheet by each day in `days`.
```{r eval = FALSE}

days <- c(1, 2, 3)

lapply(X = 1:length(files), FUN = function(x){
  
  sim_dats_rfid %>%
    # Filter the data frame by one day at a time
    dplyr::filter(day == days[x]) %>%
    # Write out data frame filtered by the given day to a separate spreadsheet 
    write.csv(file = files[x], row.names = FALSE)
  
})

```

You can delete these files that you created for testing. In the code below, you're seeing another pattern searching example while checking whether the function ran correctly. The string that you pass to the argument `pattern` starts with the symbol `^`, which is a symbol that indicates you're searching for all files that *start* with the pattern "test". You're also telling the function to return the full location of each file along with the file name, so that `file.remove()` knows exactly where to look for each file.
```{r eval = FALSE}

rem_files <- list.files(file.path(path, "Data/RFID"), pattern = "^test", full.names = TRUE)
rem_files

file.remove(rem_files)

```

<h3>Use a loop to save RFID spreadsheets</h3>

Now you can put all of these pieces together and use the loop to write out a spreadsheet per day for the RFID sensor.
```{r eval = FALSE}

# Make a vector of the custom file names to write out
files <- c(
  "RFID_simulated_Pair-01_2023_08_01.csv", 
  "RFID_simulated_Pair-01_2023_08_02.csv", 
  "RFID_simulated_Pair-01_2023_08_03.csv"
)

# Add the file path for the correct directory
files <- file.path(path, "Data/RFID", files) 
files

# Make a vector of the days to write out (1 day per iteration of the loop)
days <- c(1, 2, 3)
days

# You can drop the lapply() argument names, since you're supplying the arguments in the order that the function expects
invisible(lapply(1:length(files), function(x){
  
  sim_dats_rfid %>%
    # Filter the data frame by one day at a time
    dplyr::filter(day == days[x]) %>%
    # Write out the filtered data frame to the correct spreadsheet for the given day
    write.csv(file = files[x], row.names = FALSE)
  
}))

```

In the code above, you'll see one additional change that we made to the loop by wrapping it in the function `invisible()`. This function silences the output printed to the console that you saw several times above, in which the output of each `lapply()` iteration is enclosed in double square brackets, and then a single pair of square brackets. `lapply()` is a function that returns a list, and when the function is carried out correctly but there is not output to print, the function will return `NULL` values (indicating empty output). This is the expected behavior of `lapply()` for our purposes, because we used `lapply()` to write out physical files rather than to return output to the R console. Since you can check that the function worked by running `list.files()`, using `invisible()` helps clean up the amount of text that you need to check in your console.

```{r eval = FALSE}

# The new .csv files for each day of RFID data are present, looks good
list.files(file.path(path, "Data/RFID"))

```

You can remove these files for now, since you will work on writing a nested loop structure that automatically writes out the data for each sensor type per day.
```{r eval = FALSE}

files <- c("RFID_simulated_Pair-01_2023_08_01.csv", "RFID_simulated_Pair-01_2023_08_02.csv", "RFID_simulated_Pair-01_2023_08_03.csv")

# Add the file path for the correct directory
files <- file.path(path, "Data/RFID", files) 
files

file.remove(files)

```

If you want more practice writing loops, you can write out a loop structure to save a spreadsheet for each day of data collection for the infrared beam breaker dataset.

<h3>Write a nested loop to save spreadsheets</h3>

If you want to cut down on the amount of code that you're writing to save the raw data per sensor and day of data collection, you could write out both the RFID and beam breaker data in the same looping structure. To continue, you'll need to create another directory for the beam breaker data:
```{r eval = FALSE}

dir.create(file.path(path, "Data", "IRBB"))

```

To carry out the file filtering and writing for both sensor types across days, you'll use a type of object called a `list`. You will then use these lists inside of a nested loop structure:
```{r}

# Make a list of the custom file names to write out for each sensor type and day
files <- list(
  c("RFID_simulated_Pair-01_2023_08_01.csv", "RFID_simulated_Pair-01_2023_08_02.csv", "RFID_simulated_Pair-01_2023_08_03.csv"),
  c("IRBB_simulated_Pair-01_2023_08_01.csv", "IRBB_simulated_Pair-01_2023_08_02.csv", "IRBB_simulated_Pair-01_2023_08_03.csv")
)

glimpse(files)

```

Lists are useful objects because they're very flexible. Unlike vectors, a single list can hold many different types of data. And then unlike a data frame, the elements of a list do not need to have the same dimensions. The elements of a list can also be different data structures or object types themselves. For instance, lists can contain vectors, data frames, and other lists all inside of the same larger list object. The list that you created above has 2 elements, and each element is a vector of 3 character strings containing the file names that you supplied using the function `c()`.

You can index lists in a manner that is similar to indexing vectors and data frames, but indexing lists can be done with single or double square brackets for different outcomes:
```{r}

# Using a single square bracket to filter a list returns the first list element in list format
files[1]
glimpse(files[1])

# Using double square brackets returns the first list element only, so it removes the list structure and shows the original data structure of that element (here a vector)
files[[1]]
glimpse(files[[1]])

```

Lists can also have named elements, which makes it possible to access elements by name.
```{r}

# Make a named list of the custom file names to write out
files <- list(
  `RFID` = c("RFID_simulated_Pair-01_2023_08_01.csv", "RFID_simulated_Pair-01_2023_08_02.csv", "RFID_simulated_Pair-01_2023_08_03.csv"),
  `IRBB` = c("IRBB_simulated_Pair-01_2023_08_01.csv", "IRBB_simulated_Pair-01_2023_08_02.csv", "IRBB_simulated_Pair-01_2023_08_03.csv")
)

glimpse(files)

```

Access the list elements by name:
```{r}

# Using a single bracket returns the first element as a list, called "RFID"
files["RFID"]

# Using the dollar sign or double square brackets returns the first list element in its original format
files$RFID

files[["RFID"]]

```

Lists are very useful data structures for setting up nested loop operations. For instance, if you want to write out a spreadsheet per day per sensor type, you need 1) a loop to iterate over sensor types, and then 2) a loop to iterate over days per sensor. You can use lists to create nested data structures to supply to a nested loop, which will help you make sure that each layer of the loop runs in the way that you expect. For instance, the list called `files` reflects the nested loop that you need because files are listed first by sensor type (each element of the list) and then by date (each element of the vector inside of each list element):
```{r}

# Make a vector of sensor labels
sensors <- c("RFID", "IRBB")

sensors

# Make a named list of the custom file names to write out
files <- list(
  `RFID` = c("RFID_simulated_Pair-01_2023_08_01.csv", "RFID_simulated_Pair-01_2023_08_02.csv", "RFID_simulated_Pair-01_2023_08_03.csv"),
  `IRBB` = c("IRBB_simulated_Pair-01_2023_08_01.csv", "IRBB_simulated_Pair-01_2023_08_02.csv", "IRBB_simulated_Pair-01_2023_08_03.csv")
)

files

# Make a list of file paths per sensor that will be used inside of the loop
file_dirs <- list(
  `RFID` = file.path(path, "Data/RFID"),
  `IRBB` = file.path(path, "Data/IRBB") 
)

file_dirs

# Make a list of the days to write out for each sensor
# This could be a single vector rather than a list since you want to write out the same days per sensor, but a list is useful in case you wanted to change the days (and number of days) to write out per sensor
days <- list(
  `RFID` = c(1, 2, 3),
  `IRBB` = c(1, 2, 3)
)

days

# Finally, you need to make a list of the data frames that you want to write out. Since you already know how to filter data frames by day, that code can go inside of the loop. Here you can specify the data frame to use in the filtering operation per sensor type
dats <- list(
  `RFID` = sim_dats_rfid,
  `IRBB` = sim_dats_irbb
)

glimpse(dats)

```

Once you've set up the data structures that you want to loop over, you can write out the nested loop itself. Since this is a complex loop structure, it can be helpful to test the loop with set values of each iterating variable (below these will be `x` and `y`). 

After writing out this loop but before running the full loop structure, you should test the code inside of each loop layer. To do this, you can set the values of each iterating variable outside of the loop and then run the code inside of each loop. This form of testing is equivalent to freezing the loop in time, so that you're seeing the output of the code for a single loop iteration (below, the first iteration for each loop layer when `x` and `y` are both set to 1).

To carry out this type of testing, you should run the code to freeze the iterating variables on the first iteration of each loop. Then, you should run the code inside of each loop, starting with the creation of `days_tmp`, then the indexing and filtering the data frame, and then the filtering of the file names. You should not run either of the lines with `lapply()` in them, since you don't want either loop to fully execute before you're sure that the inner code is working as expected.

*Important note*: Above you learned that the iterating variables in a loop do not exist outside of the loop. In this testing that you will cary out, you're not fully running either loop, and so the code that you're testing inside of each loop will "see" the values of iterating variables that you initialized outside of the loops.

As you test the code inside of each loop, you should see that between the outer and inner loops, you're using the name of the sensor for the given outer loop iteration ("RFID" for the first iteration) to set up the days over which the inner loop will iterate (in `days_tmp`). Inside of the inner loop, you're filtering the list of data frames by sensor, and then by the days that you want per sensor. Finally, you're indexing the file name for the right sensor type and day with a combination of double and single bracket filtering on the list of file names. Below, the lines of code that open and close each loop are commented out in order to guide you through which lines of code you should run in this testing step:
```{r eval = FALSE}

# Freezer the iterating variables for testing
x <- 1
y <- 1

# The outer loop: start by iterating over sensors
# invisible(lapply(1:length(sensors), function(x){
  
  # Index the named list of days to get the right days per sensor
  # This indexing is important to set up the next loop correctly
  sensors[x] # This is a string with the sensor name
  
  # Place the string with the sensor name inside of double square brackets to extract the vector of days for that sensor 
  days_tmp <- days[[sensors[x]]]
  
  days_tmp
  
  # The inner loop: for each sensor, iterate over days
  # lapply(1:length(days_tmp), function(y){
    
    # Get the data frame per sensor type using x inside of double square brackets to extract the given data frame from the list
    dats[[x]] %>%
      # Filter the data frame by one day at a time by using y to index the temporary vector of days (e.g. to extract a single element from that vector)
      dplyr::filter(day == days_tmp[y]) %>% 
      glimpse()
    
    # Use double bracket filtering to pull out the vector of file names for the given sensor from the overall list, then use y with single bracket filtering to pull a single file name from the resulting vector of names
    files[[x]]
    
    files[[x]][y]
    
    # You'll also combine the file name with the right path:
    file.path(file_dirs[[x]], files[[x]][y])
    
  # })
  
# }))

```

You should have a better sense now of how each loop operates over different data structures to carry out the operation that you want (writing out a single spreadsheet per sensor type and day). Next, you can modify the full loop to replace the lines written for testing with the final operations that you want to carry out: 
```{r eval = FALSE}

# Start by iterating over sensors
invisible(lapply(1:length(sensors), function(x){
  
  # Index the list of days to get the right days per sensor
  # This indexing is important to set up the next loop correctly
  days_tmp <- days[[sensors[x]]]
  
  # For the given sensor, iterate over days of data collection to write out a spreadsheet per sensor and day
  lapply(1:length(days_tmp), function(y){
    
    # Get the data frame per sensor type using x and then filter by day using y
    dats[[x]] %>%
      # Filter the data frame by one day at a time
      dplyr::filter(day == days_tmp[y]) %>%
      # Use double-bracket filtering to pull out the right file path per sensor
      # Then use double and single bracket filtering to pull out the right file name per sensor and day
      write.csv(file = file.path(file_dirs[[x]], files[[x]][y]), row.names = FALSE)
    
  })
  
}))

```

This loop should have created 1 file per sensor and day in the correct directory per sensor. Check that these 6 files now exist inside each directory per sensor within your working directory.
```{r eval = FALSE}

list.files(file.path(path, "Data/RFID"))

list.files(file.path(path, "Data/IRBB"))

```

You learned more about filtering data frames, writing them out to spreadsheets, and writing single-layer and nested loops in this vignette. In the next vignette, you'll use the spreadsheets of simulated RFID and IRBB data to start the ABISSMAL data processing and analysis workflow.

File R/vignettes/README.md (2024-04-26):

<h1>ABISSMAL R vignettes</h1>
<b>Developer:</b><br>
Grace Smith-Vidaurre, PhD: <span style="pointer-events:none">gsvidaurre[at]<span style="display:none"></span>gmail.com</span>
<br>

<h2>Overview</h2>

The goal of these vignettes is to disseminate R coding skills in a biological context through the ABISSMAL behavioral tracking system. There are six vignettes that cover the following topics:

1. An introduction to RStudio that includes downloading the ABISSMAL GitHub repository, an introduction to the ABISSMAL data processing and analysis pipeline, and information about troubleshooting errors and reporting bugs

2. Learn how to set up a virtual workspace, including cleaning your global environment, running code inside RMarkdown files, package installation, keyboard shortcuts, creating and specifying a working directory

3. Create simulated datasets of animal movements while learning how to create objects in R, different data types in R, and how to manipulate objects with conditional statements and piping expressions

4. Save the simulated datasets and learn how to write data as files on your computer, how to manipulate data frames with base R and the tidyverse, and how to write simple and complex loops

5. Work through the ABISSMAL data processing pipeline while learning how to access and use custom functions, as well as how to plot timestamps in a barcode figure

6. Finish the ABISSMAL data analysis pipeline while using the R coding skills that you practiced in the earlier vignettes, and end by making a more complex and refined barcode figure

Each vignette is available as a RMarkdown (extension `.Rmd`) file that can be opened in RStudio. The knitted output per vignette is available in HTML format, and you can open these files in your default Internet browser. The HTML files contain text, code, and the output of code chunks.

After completing the vignettes, it would be very helpful if you could complete the brief [Google form](https://forms.gle/98G8aQV8dDMcZz3T7) for a post-vignette evaluation that will help us continue to improve these vignettes over time.

<h2>Resumen</h2>

Nuestro objetivo es diseminar habilidades de programación en R en un contexto biológico a través del sistema de ABISSMAL. Tenemos seis tutoriales que cubren los siguientes puntos:

1. Una introducción a RStudio que incluye cómo descargar el repositorio de GitHub de ABISSMAL, una introducción al `pipeline` para procesar y analizar datos de ABISSMAL, e información sobre cómo manejar y reportar errores 

2. Aprender cómo configurar un espacio virtual, incluyendo limpiar tu ambiente global, ejecutar código dentro de piezas de código de archivos de RMarkdown, instalar paquetes, atajos para escribir código, y crear y especificar un directorio de trabajo

3. Crear datos simulados de movimientos de animales mientras se aprende cómo crear objetos en R, qué son los diferentes tipos de datos en R, y cómo manipular objetos con frases condicionales y expresiones de `piping`

4. Guardar los datos simulados y aprender cómo escribir datos a archivos físicos en tu computadora, manipular `dataframes` con R base y el `tidyverse`, y escribir bucles (`loops`) sencillos y complejos

5. Trabajar en el `pipeline` de procesar datos con ABISSMAL mientras aprendes cómo acceder y usar funciones customizadas, y también cómo visualizar marcas de tiempo en una gráfica de barras

6. Terminar el `pipeline` de análisis de datos de ABISSMAL mientras se emplean las habilidades de programación que practicaste en los tutoriales anteriores, y al final vas a crear una figura de código de barras más compleja y refinada

Cada tutorial está disponible como un archivo de RMarkdown (extension `.Rmd`) que puedes abrir en RStudio. El reporte de cada tutorial está disponible como un archivo en formato HTML, estos archivos se pueden abrir en cualquier navegador de internet (Google Chrome, Firefox, Safari, etc). Los archivos de HTML contienen texto, código, y los resultados de las piezas de código.

Sería una gran ayuda si después de completar los tutoriales pudieras completar una encuesta a través de [Google Forms](https://forms.gle/CaQXVWDrY5oHg8mCA). La información que compartas nos ayudará mejorar los tutoriales en el futuro.

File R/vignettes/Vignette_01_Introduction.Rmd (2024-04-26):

---
title: "Vignette 01: Introduction"
author: "Grace Smith-Vidaurre"
date: "2023-12-27"
output: 
  html_document:
    css: "styles.css"
    toc: true
    toc_float: true
    toc_depth: 4
---

<h2>Vignette overview and learning objectives</h2>

This first vignette will take you through a brief introduction to RStudio, downloading a local version of the ABISSMAL GitHub repository, and an introduction to the data analysis workflow provided by ABISSMAL. Through this tutorial, you will learn:

1. How to configure your RStudio session
2. How to create a local version of a GitHub repository
3. The data processing and analysis steps provided by the ABISSMAL R functions
4. How to troubleshoot errors online
5. How to report bugs as GitHub issues

There are many different ways to carry out a single task or to solve a single problem in R. Keep this in mind throughout all of these tutorials. In each tutorial, you will learn examples of how to carry out specific tasks or solve specific problems with code, but these examples are not an exhaustive overview of how to address any one task or solve any one problem. Instead, use these tutorials as an opportunity to practice using your coding skills in a biological context.  

<h2>Configure your RStudio session</h2>

If you are new to using R (a programming language for statistical analysis) and RStudio (a graphical user interface for R), then I recommend checking out the introductory lesson [R for Reproducible Scientific Analysis](https://swcarpentry.github.io/r-novice-gapminder/) provided by the [Software Carpentry](https://software-carpentry.org/).

Once you have R and RStudio installed on your computer, you can open RStudio by clicking on the software icon. The default pane configuration for RStudio should look like this (the background color will probably be different):

<br>
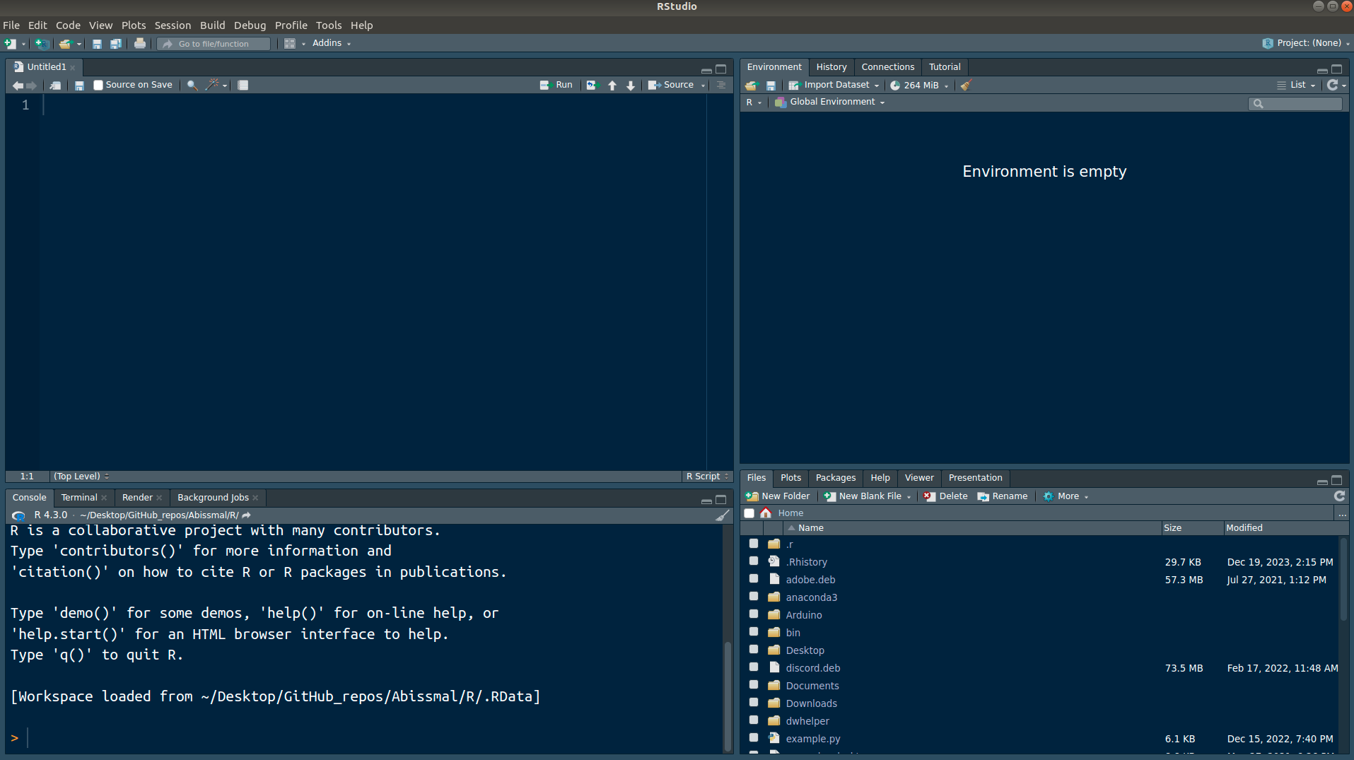
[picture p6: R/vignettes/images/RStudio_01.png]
A screenshot of the default RStudio pane configuration, with the console pane below the source pane


This pane layout makes it difficult to see the code that you're writing and saving in a physical file in the source pane, and the output of that code in the console pane. You can reconfigure the panes so that the source and console panes are horizontally adjacent to one another, which makes it easier to immediately check the output of any code that you run. To reconfigure the pane layout:

* Go to the menu along the top bar of the RStudio window and select the option "Tools"

* Select "Global Options" in the pop-up menu

* In the next pop-up menu, select the option "Pane Layout" along the lefthand side

* Use the dropdown menus to select "Source" as the top right pane and "Console" as the top left pane

* You can select "Apply" to apply those changes, then "Ok" to exit this window 

The RStudio pane layout should now look like this:

<br>
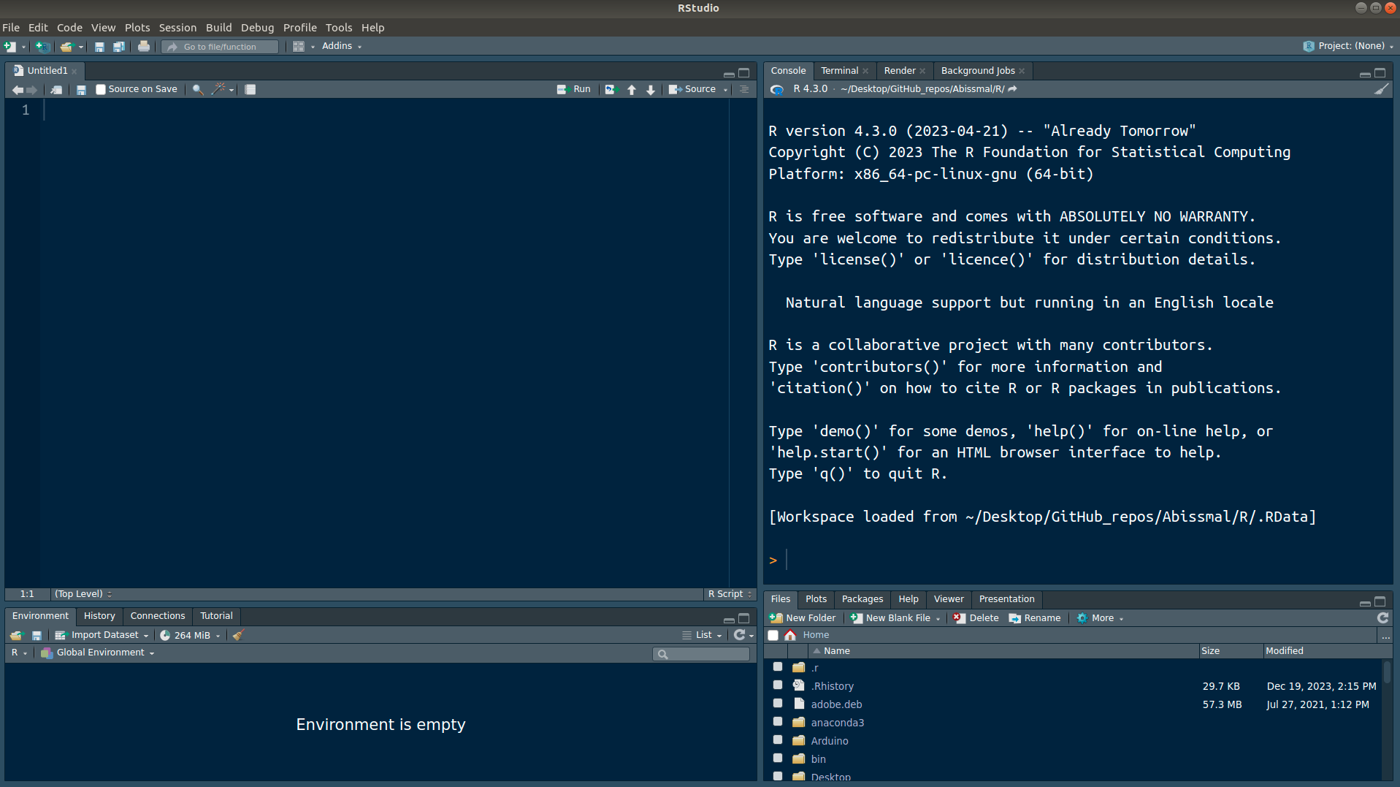
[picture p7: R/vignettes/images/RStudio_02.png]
A screenshot of the updated RStudio pane configuration, with the console pane to the right of the source pane


Another useful change to the RStudio configuration is soft-wrapping lines of text and code so that you don't have to scroll horizontally to see long lines of text in your Source pane. To do this, go to "Tools", then "Global Options", then "Code", and check the box next to the option "Soft-wrap R source files", then select "Apply" and "Ok".

You can also change the font size, font color, and background color of your RStudio workspace. After selecting "Tools" and "Global Options", go to "Appearance" to see some different options.

<h2>Create a local version of an existing GitHub repository</h2>

If you are new to using GitHub, then I recommend downloading [GitHub Desktop](https://desktop.github.com/). This software is a graphical user interface for the GitHub version control platform. We will work through how to download the GitHub repository for ABISSMAL so that you can access the ABISSMAL R functions on your local computer. If you are already familiar with GitHub and using Git through the command line, then check out the installation instructions on the [ABISSMAL README](https://github.com/lastralab/ABISSMAL).

Once you have installed GitHub Desktop:

* Open GitHub Desktop by clicking on the icon

* Open your default Internet browser and navigate to the ABISSMAL GitHub repository: https://github.com/lastralab/ABISSMAL

* Click on the green "Code" button and copy the web URL under the HTTPS option in the dropdown menu

* In the GitHub Desktop window, go to the top menu and select "File"

* Select "Clone repository", 

* Select the tab "URL"

* Paste the web URL for ABISSMAL into the text box under "Repository URL or GitHub username and repository"

* Check that the directory in the text box under "Local path" is the correct place to install the ABISSMAL GitHub repository on your computer. For instance, if "Local path" is "/home/User/Desktop/ABISSMAL", then the ABISSMAL repository will be installed directly to your Desktop

* Select "Clone" once you're ready to create a local version of the remote ABISSMAL repository on your computer

Once the repository has been installed on your computer, you should see the following directory and file structure inside the folder labeled "ABISSMAL" that looks similar to this:

<br>
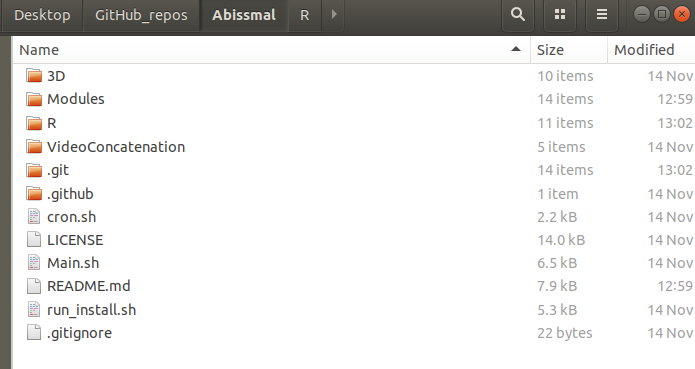
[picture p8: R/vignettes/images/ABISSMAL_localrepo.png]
A screenshot of the directory that is the local ABISSMAL repository


The files that we'll be working with throughout the following vignettes are inside of the "R" folder. This folder contains 6 R files (extension ".R"), a README file that contains more information about each R file, and folders with the vignettes in RMarkdown format (extension ".Rmd") as well as automated unit testing scripts.

<h2>ABISSMAL data processing and analysis</h2>

ABISSMAL provides 5 different R functions for data processing and analysis. These functions are briefly described below in the order in which they should generally be used. The functions are also described in more detail in the R folder README as well as the accompanying methods manuscript:

1. `combine_raw_data` will automatically concatenate spreadsheets of raw data collected each day into a single spreadsheet across days. This data concatenation is performed for a given sensor type (e.g. infrared beam breakers or an infrared video camera) and does not change or overwrite the original raw data. This function can use data from any sensor type (RFID, infrared beam breakers, video camera, or temperature probe) as input, but the following functions do not accept data from the temperature probe

2. `detect_perching_events` uses the output of `combine_raw_data` as input, and will detect stretches of detections that occurred close together in time as perching events. These events represent periods of time when an individual was perched in the RFID antenna in the nest container entrance. This function returns a spreadsheet of the timing of inferred perching events detected using data from sensors placed around the nest container entrance (RFID or infrared beam breakers)

3. `preprocess_detections` uses the output of `combine_raw_data` as input, and removes detections that occurred very close together in time. This function returns a spreadsheet of pre-processed data per sensor type, in which consecutive detections are all separated by no less than a given temporal threshold (e.g. when using a threshold of 1 second, only a single detection can occur per second)

4. `detect_clusters` uses the output of `preprocess_detections` from any 2 or more movement sensor types as input. This function identifies detections across 2+ sensor types that occurred close together in time, and returns temporal information and metadata about each detection cluster. Detection clusters represent discrete movement events by one or more individuals

5. `score_clusters` uses the output of `detect_clusters` as the main input. This function can also use the output of `detect_perching_events` to integrate perching events detected in the raw RFID or infrared beam breaker datasets. It can also use the output of `preprocess_detections` to integrate video recording events that were not detected by `detect_clusters`. This function serves to make behavioral inferences about each movement event, including the direction of movement, the magnitude of movement, individual identity when RFID data was present in a cluster, and where the beginning of the movement event likely occurred (at the container entrance or inside of the container). This function returns a spreadsheet of behavioral inferences and other metadata about each movement event that can be used for subsequent analyses and visualization

<br>
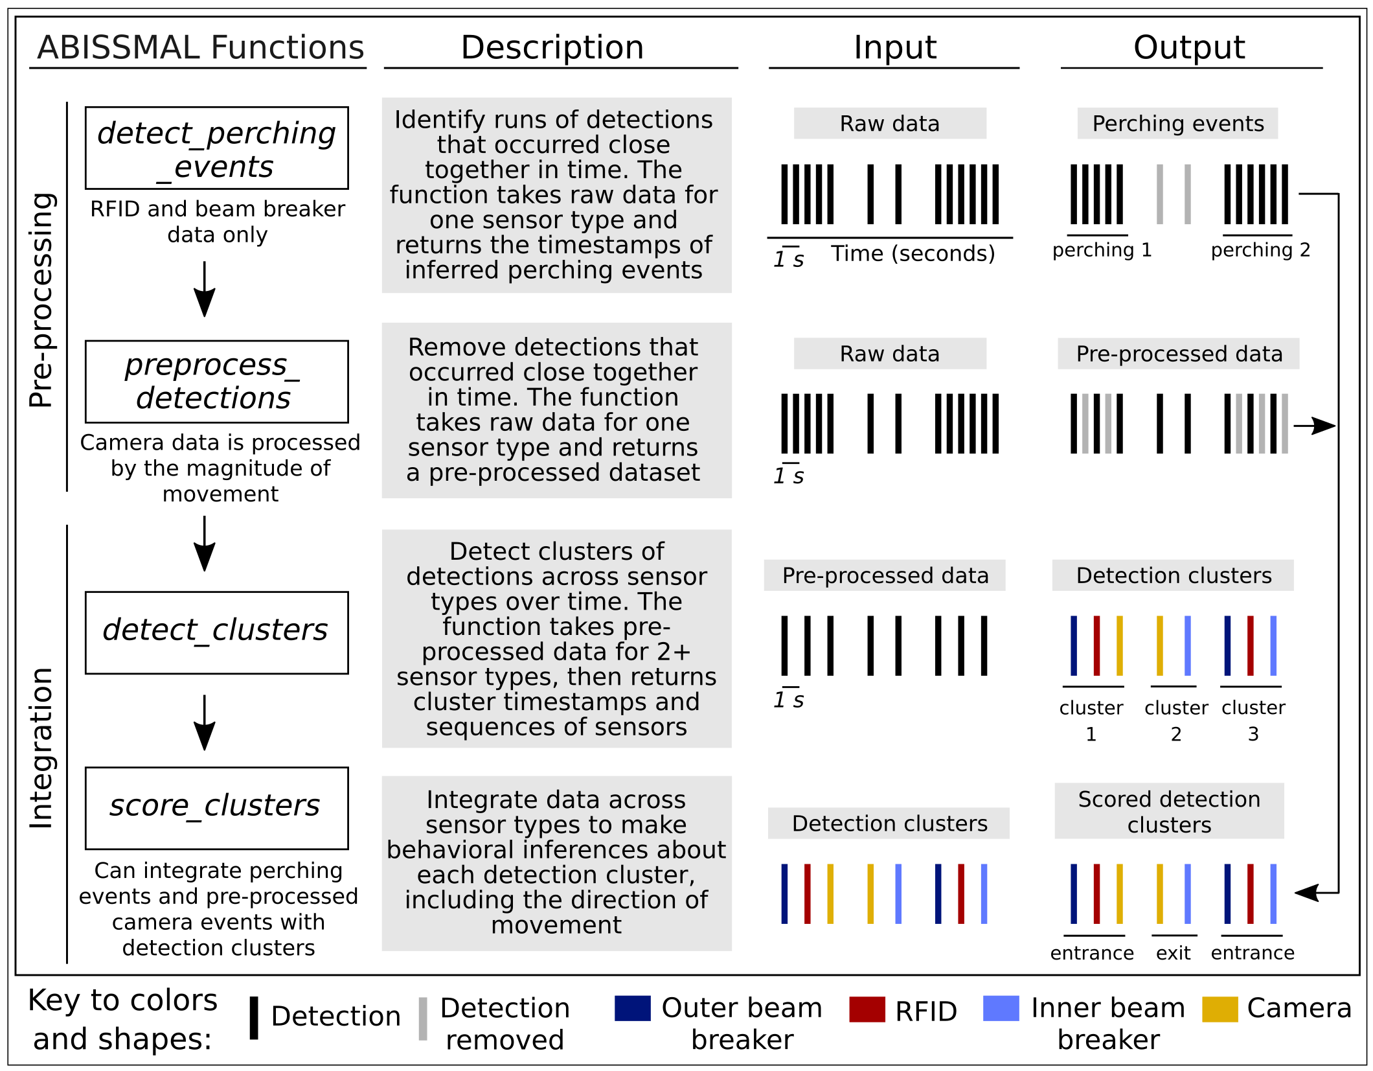
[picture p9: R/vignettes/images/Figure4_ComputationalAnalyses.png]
Figure 4 from the ABISSMAL methods manuscript under review, that shows a general workflow across these 5 functions

* Figure from Smith-Vidaurre, G., Molina, T., Jarvis, E.D., and E.A. Hobson. 2023. Automated tracking of avian parental care. [EcoEvoRxiv preprint]((https://ecoevorxiv.org/repository/view/6268/)).

<h2>Troubleshoot errors online</h2>

You will run into errors while writing and running code, and while this can be frustrating, errors are an important part of the overall learning experience. Errors can arise for many different reasons, including typos that you introduced while writing code, issues with package versions that you installed, or perhaps missing packages. Sometimes, errors may be due to issues with the custom ABISSMAL functions that you will use in the subsequent vignettes, or issues with the code in the vignettes themselves. 

Whenever you run into an error with your code, it's important to troubleshoot the error and figure out out how to solve it before assuming that the error is due to the custom ABISSMAL functions or issues with the ABISSMAL vignettes. There are many different resources online that you can use to troubleshoot common errors in R. One way to start troubleshooting errors online is to copy and paste the error message printed to your console into a search engine, which should point you to public forums online in which people have asked about and solved similar errors. You may also be able to use generative AI tools like ChatGPT to search for potential typos or issues with your code. You can also read R documentation to figure out if the error is associated with a specific package or function upon which ABISSMAL depends.

Once you have thoroughly researched a given error, and you're sure that the error you're getting isn't due to a typo or issues with data structure on your end, then it's time to consider whether the error is due to a bug in a custom ABISSMAL function or the code provided in a vignette. These are bugs that you can report to the ABISSMAL developers on GitHub (see below).

<h2>Report bugs on GitHub</h2>

As you work through each vignette, you may encounter "bugs" or errors with the code, including code that does not work or that yields incorrect outcomes. These bugs can occur with the ABISSMAL functions themselves, or with the code in a given vignette. When you encounter a bug with an ABISSMAL function, you can create an Issue through the GitHub repository. To create a new Issue, you can select "New Issue" on the [Issues page](https://github.com/lastralab/ABISSMAL/issues) of the main ABISSMAL repository, then follow the instructions in the Issue template to add the information needed for the code developers to address the bug effectively. You can also add the tag "bug" to your issue. If you encounter an issue with the ABISSMAL vignettes, then you can submit an issue through the main ABISSMAL GitHub repository as well, as long as you clarify that the bug is related to code in a given vignette.

In the next vignette, we will create simulated datasets of raw movement data to learn how to use the different ABISSMAL functions described above.

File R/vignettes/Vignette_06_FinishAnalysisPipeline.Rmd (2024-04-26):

---
title: "Vignette 06: Finish Analysis Pipeline"
author: "Grace Smith-Vidaurre"
date: "2023-12-27"
output: 
  html_document:
    css: "styles.css"
    toc: true
    toc_float: true
    toc_depth: 4
---

```{r setup, include = FALSE}

knitr::opts_chunk$set(echo = TRUE, eval = TRUE)

```

<h2>Vignette overview and learning objectives</h2>

In this sixth and last vignette, you will finish using the simulated detections of animal movements in the ABISSMAL data processing and analysis workflow. You will detect clusters of detections that represent distinct movement events, and then score behavioral inferences about the movement events. You will also make plots to visualize these behavioral inferences. You will continue to use coding skills that you learned in the previous vignettes, and you will additionally learn how to build more complex visualizations with ggplot.

<h2>Load packages and your working directory path</h2>

```{r message = FALSE, warning = FALSE}

rm(list = ls()) # Clean global environment

library(tidyverse) # Load the set of tidyverse packages
library(data.table) # Load other packages that the ABISSMAL functions require

# Initialize an object with the path that is your working directory
path <- "/home/gsvidaurre/Desktop/ABISSMAL_vignettes"

```

<h2>Load ABISSMAL functions</h2>

```{r}

# Load the function that detects clusters in the pre-processed data
source("/home/gsvidaurre/Desktop/GitHub_repos/ABISSMAL/R/detect_clusters.R")

# Load the function that scores behavioral inferences about clusters
source("/home/gsvidaurre/Desktop/GitHub_repos/ABISSMAL/R/score_clusters.R")

# Load a script with utility functions that each function above requires
source("/home/gsvidaurre/Desktop/GitHub_repos/ABISSMAL/R/utilities.R")

```

<h2>Finish the ABISSMAL pipeline</h2>

Here you'll use the ABISSMAL function `detect_clusters()` to identify clusters of detections across sensor types (e.g. detections from different sensors that were recorded close together in time). 
```{r}

# The run length needs to be set to 1 in order to correctly detect detection clusters of length 2
detect_clusters(file_nms = c("pre_processed_data_RFID.csv", "pre_processed_data_IRBB.csv"), threshold = 2, run_length = 1, sensor_id_col_nm = "sensor_id", timestamps_col_nm = "timestamp_ms", PIT_tag_col_nm = "PIT_tag", rfid_label = "RFID", preproc_metadata_col_nms = c("thin_threshold_s", "data_stage", "date_pre_processed"), general_metadata_col_nms = c("chamber_id", "year", "month", "day"), path = path, data_dir = "Data/processed", out_dir = "Data/processed", out_file_nm = "detection_clusters.csv", tz = "America/New York", POSIXct_format = "%Y-%m-%d %H:%M:%OS")

```

Next, you'll score behavioral inferences about these detection clusters with the function `score_clusters()`. 
```{r}

score_clusters(file_nm = "detection_clusters.csv", rfid_label = "RFID", camera_label = NULL, outer_irbb_label = "Outer Beam Breakers", inner_irbb_label = "Inner Beam Breakers", video_metadata_col_nms = NULL, integrate_perching = TRUE, perching_dataset = "RFID", perching_prefix = "perching_events_", sensor_id_col_nm = "sensor_id", PIT_tag_col_nm = "PIT_tag", pixel_col_nm = NULL, video_width = NULL, video_height = NULL, integrate_preproc_video = FALSE, video_file_nm = NULL, timestamps_col_nm = NULL, path = path, data_dir = "Data/processed", out_dir = "Data/processed", out_file_nm = "scored_detectionClusters.csv", tz = "America/New York", POSIXct_format = "%Y-%m-%d %H:%M:%OS")

```

<h2>Check final results</h2>

Now that you finished running the ABISSMAL pipeline to detect and make inferences about movement events, you can check the final results.
```{r}

scored_clusters <- read.csv(file.path(path, "Data/processed", "scored_detectionClusters.csv")) %>% 
  # The timestamps must be converted to POSIX format every time that the data is read back into R for plotting
  dplyr::mutate(
    start = as.POSIXct(format(as.POSIXct(start, tz = "America/New York"), "%Y-%m-%d %H:%M:%OS6")),
    end = as.POSIXct(format(as.POSIXct(end, tz = "America/New York"), "%Y-%m-%d %H:%M:%OS6"))
  ) %>%
  # Arrange the rows by increasing timestamps
  dplyr::arrange(-desc(start))

glimpse(scored_clusters)

```

How many entrances and exits were scored per day? 

<h2>Missing data in R</h2>

In order to count the number of each of these events scored per day, you need to know how to account for missing data in R. Missing data is often indicated using the value `NA` or "not available", which is a specific type of logical value in R. You can figure out whether a vector (or a column in a data frame) contains missing values by using the function `is.na()`, which will return TRUE when it finds an NA (missing) value in the given vector.
```{r}

?is.na()

x <- c(1, NA, 2, 3, NA)

is.na(x)

```

In the code above, you created a vector called `x` that has 2 NA values. The function `is.na()` checks whether each element of `x` is equivalent to `NA`, and returns `TRUE` when that condition is met (when it finds missing data).

Because `is.na()` is a conditional statement, you can also use other special symbols relevant to conditional statements, such as the `!` symbol, which will invert a conditional statement. For instance, in the code below, by adding `!` before `is.na()`, you're now asking whether each element of `x` is *not* equivalent to NA:
```{r}

!is.na(x)

```

As you can see, adding the `!` in front of `is.na()` results in an inverted output compared to `is.na()` alone, such that each value that was previously `TRUE` is now `FALSE`. Together, the ability to invert the `is.na()` conditional statement, plus the binary output that `is.na()` returns, is really useful for finding and filtering rows of a data frame. 

For instance, the function `dplyr::filter()` will drop a row whenever it encounters a value of `FALSE` in a given column, and will retain a row whenever it encounters a value of `TRUE`. If you want to drop rows that contain `NA` values for a given column, you would add `!is.na(name_of_column)` inside of `dplyr::filter()`, which should return `FALSE` every time it encounters a row with `NA`, and will remove that row during filtering. 

<h2>Count events per day</h2>

Now you can write code to count the number of entrance and exit events scored per day. You will need to 1) make a new column with information about the day per timestamp, 2) drop rows with missing data for the direction scored (because this information cannot be scored for some movements), 3) group the data frame by day and direction scored, and then 4) count the number of rows per group.
```{r}

scored_clusters %>%
  # Extract the day from each timestamp and make a new column with this information
  dplyr::mutate(
    day = lubridate::day(start)
  ) %>% 
  # Here you're using the function is.na(), which will return TRUE when it finds an NA (missing) value in the given column. By placing the ! before is.na(), you're inverting the output, so that all TRUE values are converted to FALSE. As a result, dplyr::filter will drop all rows that return the value FALSE (e.g. all rows with missing values in the column direction_scored)
  dplyr::filter(!is.na(direction_scored)) %>%
  # Group the data frame by both columns for which you want to count rows (events). Here you want to count the number of entrances and exits (categories in the column direction_scored) per day (categories in the column day)
  group_by(day, direction_scored) %>% 
  # Then summarize the data: the number of rows here is the number of exits or entrances scored per day
  dplyr::summarise(
    n = n()
  )

```

Four entrance and exit events were scored per day. Does this line up with the anticipated number of exits and entrances per day? If you go back to the code where you created the simulated raw datasets in vignettes 03 and 04, you should see that you started by simulating 2 entrances and exits per day across the RFID and beam breaker datasets. Then, you added 2 more entrance and 2 more exit events per day when you simulated RFID detection failures (e.g. movements captured by the beam breakers only). `score_clusters()` detected the correct number of entrances and exits per day.

Next, check out the perching events. Start by filtering out all rows that were not scored as perching events (rows that have NA values in the column "perching_PIT_tag"). Then, select only the columns that have information that is useful to check: the PIT tag codes, as well as the start and end of each perching event.
```{r}

scored_clusters %>% 
  # Use a conditional statement with is.na() to retain only rows that have PIT tag codes associated with perching events
  dplyr::filter(!is.na(perching_PIT_tag)) %>%
  # Then select only the columns that you want to check visually
  dplyr::select(start, end, perching_PIT_tag)

```

As specified in vignettes 03 and 04, the first perching event each day was performed by the first individual (PIT tag "1357aabbcc"), and the second was attributed to the second individual (PIT tag "2468zzyyxx").

How many movement events that were not perching events were attributed to each individual?
```{r}

scored_clusters %>%
  # Extract the day from each timestamp and make a new column with this information
  dplyr::mutate(
    day = lubridate::day(start)
  ) %>%
  # Use a conditional statement with is.na() to retain only rows that have PIT tag codes not associated with perching events
  # Here you're combining two conditional statements, which allows you to search for rows in the column individual_initiated that have PIT tag codes, but that also do not have a sensor label in the column perching_sensor (e.g. movement events that were not perching events)
  dplyr::filter(!is.na(individual_initiated) & is.na(perching_sensor)) %>%
  group_by(day, individual_initiated) %>% 
  dplyr::summarise(
    n = n()
  )

```

As you can see, 4 movement events that were not perching events were attributed to the first individual (PIT tag code 1357aabbcc) on each day. This is exactly what we expected when creating the simulated dataset (see vignettes 03 and 04). More non-perching movement events were detected across these days, but those events were not always captured by the RFID antenna (e.g. the simulated RFID detection failures that were captured by the beam breakers only). The beam breakers captured those movement events but cannot record individual identity.

<h2>Build complex barcode plot</h2>

Now that you checked out the final results, you can visualize them. In the code below, you'll learn how to build a barcode plot that is more complex but also easier to interpret than the plot that you made in vignette 05. For this plot, it would be helpful to visualize 3 types of behavioral inferences or types of information over time: the direction of movement (when available), the identity of the individual (when available), and perching events.

You can start building the plot by adding vertical line segments for non-perching movement events. The color of each line will indicate the individual identity, or whether individual identity could not be assigned. The line type of each line will indicate the direction of movement, or if direction could not be scored.

In order to encode colors and line types correctly in the plot, you need to modify the data frame of final results to convert NAs in the two associated columns to more meaningful information. For instance, when individual identity is missing, it would be useful to convert the associated NA value to "unassigned". In the code below, you will use the function `is.na()` inside of `ifelse()` conditional statements to change the NA values inside the columns "individual_initiated" and "direction_scored" to more useful information for plotting purposes.

First you can practice using `is.na()` inside of `ifelse()` to create a new vector. In the code below, you're providing the conditional statement that you want to test (here you're testing whether the column holding the PIT tag code of the individual that initiated a movement has NAs), the value you want to add to the vector if the condition is true ("unassigned" when no PIT tag code is present), and then the value that you want to add if the condition is false (return the PIT tag code in the individual_initiated column if the given value is not NA). 
```{r}

# is.na() returns TRUE when it encounters NAs inside of a vector (or column), and FALSE when a value inside of the vector is not NA
is.na(scored_clusters$individual_initiated)

# All NAs in this column are converted to "unassigned", but all other values were not changed
ifelse(test = is.na(scored_clusters$individual_initiated), yes = "unassigned", no = scored_clusters$individual_initiated)

```

Now you can use `is.na()` inside of `ifelse` statements to modify columns in the data frame.
```{r}

scored_clusters_gg <- scored_clusters %>% 
  dplyr::mutate(
    # If this column has an NA value, then convert it to "unassigned"
    # Else, do not change the given value
    individual_initiated = ifelse(is.na(individual_initiated), "unassigned", individual_initiated),
    # Repeat this process for the direction_scored column but with a different value
    # Also, in the conditional statement below, you added is.na(perching_sensor) (after the & symbol) to only convert NA values in direction_scored when they were also not labeled as perching events in the column perching_sensor
    direction_scored = ifelse(is.na(direction_scored) & is.na(perching_sensor), "not scored", direction_scored)
  ) %>% 
  # Next, you'll convert each of these columns to type factor and arrange the levels in order for plotting (for example, the valures "unassigned" and "not scored" should come last in the legend)
  dplyr::mutate(
    individual_initiated = factor(individual_initiated, levels = c("1357aabbcc", "2468zzyyxx", "unassigned")),
    direction_scored = factor(direction_scored, levels = c("entrance", "exit", "not scored"))
  )

# Check the resulting changes using the function distinct() to see all of the unique values for both columns that were modified
# The NA values in the direction_scored column are expected since these refer to perching events
scored_clusters_gg %>% 
  distinct(individual_initiated, direction_scored)

```

This output looks good. You should see `NA` values in this data frame, but they're in the column "direction_scored" and associated with the eprching events, which you'll be adding to the plot in a separate layer of code later on.

You can use this modified data frame to build the plot. In the code below, you'll add lines colored by individual identity and with line types encoding the direction of movement. First you'll specify the plot aesthetics:
```{r}

# Colors will be encoded in the same order as the levels of the column individual_initiated, so orange will encode "1357aabbcc"
levels(scored_clusters_gg$individual_initiated)
cols <- c("orange", "darkgreen", "black")
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

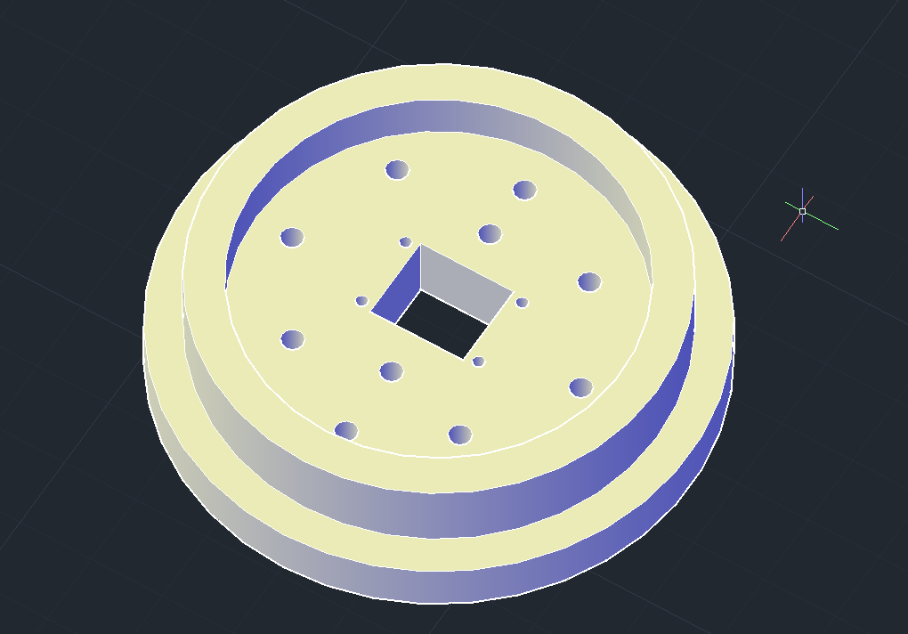
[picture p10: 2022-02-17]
3D/assets/Screen Shot 2022-02-13 at 1.46.09 PM.png

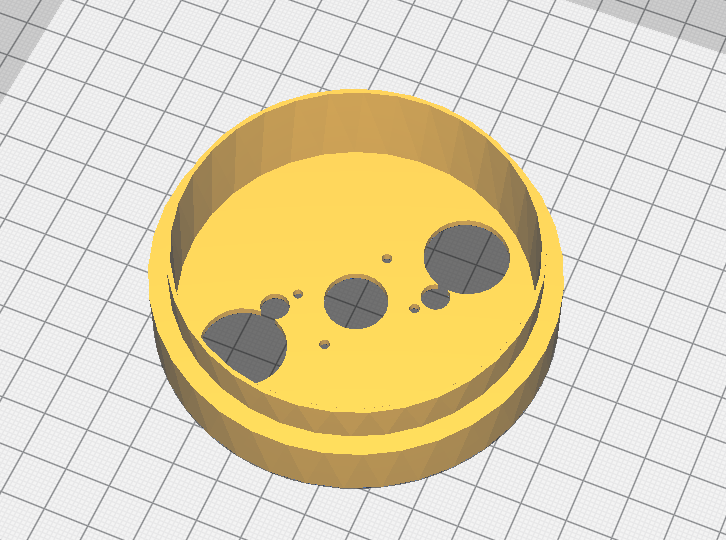
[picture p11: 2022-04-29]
3D/assets/Screen Shot 2022-04-29 at 3.28.15 PM.png

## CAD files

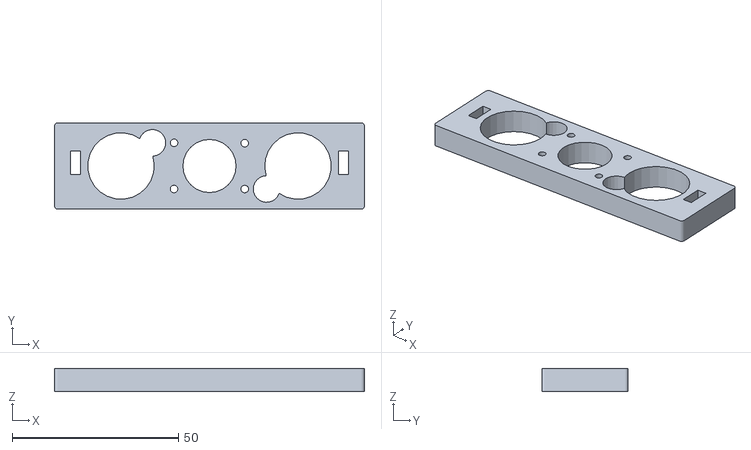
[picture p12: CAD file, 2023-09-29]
3D/camera_holder_validation.stl
93.2 x 26.0 x 7.00

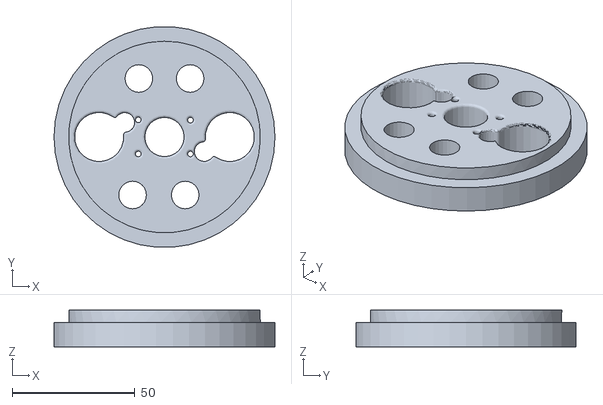
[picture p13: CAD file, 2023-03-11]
3D/ir_camera_holder_with_holes.stl
90.0 x 89.7 x 15.0

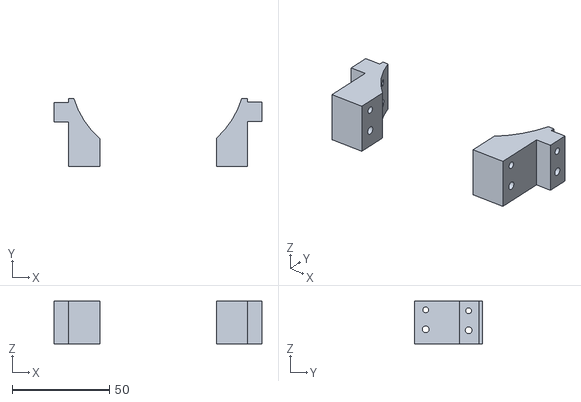
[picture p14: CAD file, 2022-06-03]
3D/IRBB.stl
106.7 x 35.0 x 22.0

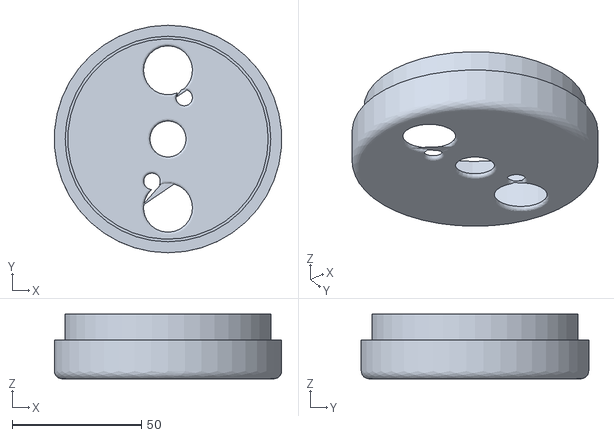
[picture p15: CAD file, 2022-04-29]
3D/ir_cam_holder.stl
87.8 x 88.0 x 25.0

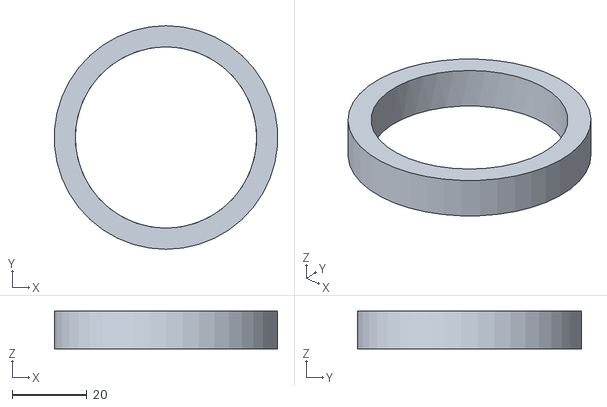
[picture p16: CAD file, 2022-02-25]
3D/antenna_cover_cap.stl
59.8 x 59.9 x 10.1

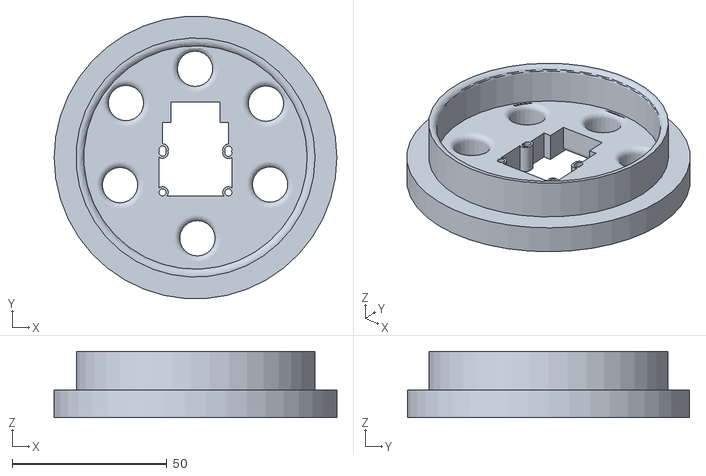
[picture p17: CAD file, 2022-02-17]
3D/cam_holder.stl
91.4 x 91.2 x 21.5

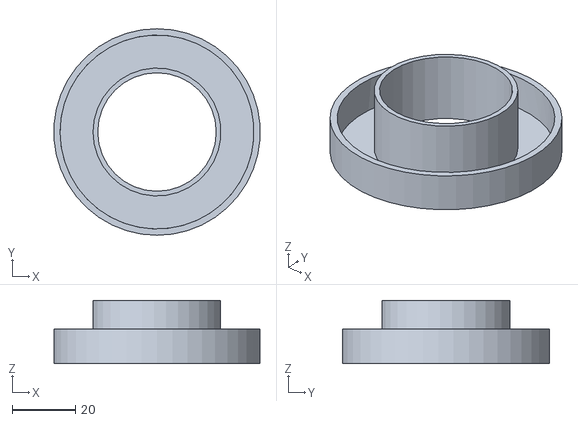
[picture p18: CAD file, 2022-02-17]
3D/antenna_cover.stl
65.2 x 65.3 x 20.0

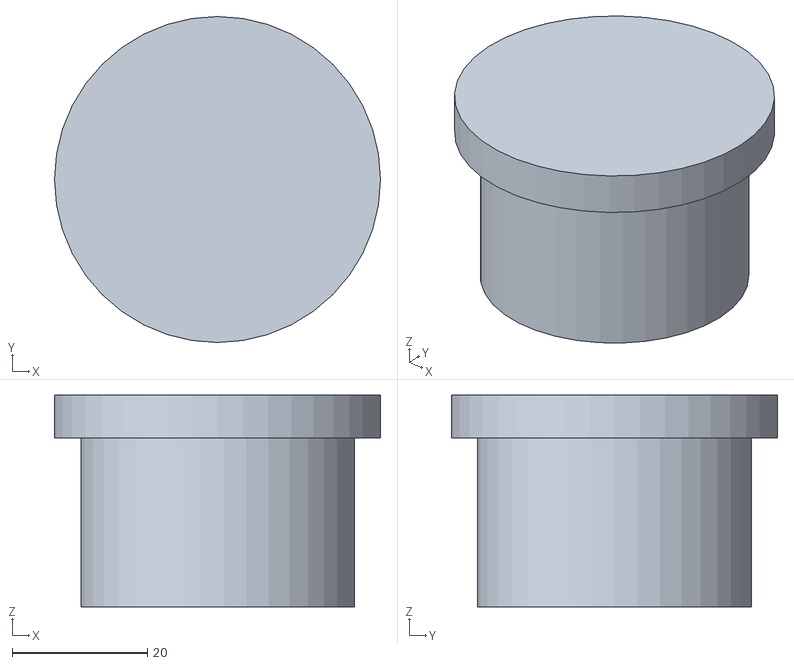
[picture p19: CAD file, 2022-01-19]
3D/nest_entrance_inverted.stl
48.2 x 48.2 x 31.3

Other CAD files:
3D/assets/camera_template.dwg

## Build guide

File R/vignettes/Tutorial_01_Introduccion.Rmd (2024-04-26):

---
title: "Tutorial 01: Introducción"
author: "Grace Smith-Vidaurre"
date: "2023-12-27"
output: 
  html_document:
    css: "styles.css"
    toc: true
    toc_float: true
    toc_depth: 4
---

<h2>Información sobre esta traducción</h2>

Este tutorial fue traducido al español por Grace Smith-Vidaurre y editado por Tania Molina, siguiendo las [convenciones de traducción de los Carpentries](https://github.com/Carpentries-ES/board/blob/master/Convenciones_Traduccion.md), incluyendo usar el género femenino por defecto. Si encuentras errores de ortografía que impiden tu habilidad de completar los tutoriales, por favor reporta los errores de ortografía a GitHub usando los pasos en este primer tutorial para reportar un "Issue".

<h2>Resumen del tutorial y objetivos de aprendizaje</h2>

En este primer tutorial aprenderás acerca del programa RStudio, cómo crear una versión local del repositorio de ABISSMAL en GitHub, y en qué consiste el `pipeline` de análisis de datos en ABISSMAL. En resumen:

1. Configurar tu sesión de RStudio
2. Crear una versión local de un repositorio de GitHub
3. Usar ABISSMAL para procesar y analizar datos
4. Solucionar problemas con tu código usando recursos en línea
5. Reportar problemas de código a GitHub

Hay muchas formas de completar una tarea o solucionar un problema en R, mantén esto en mente mientras completas estos tutoriales. En cada tutorial, vas a aprender diferentes ejemplos sobre cómo manejar ciertas asignaciones o solucionar problemas específicas con código, pero estos ejemplos no son un resumen exhaustivo de cómo manejar cada tarea ni cómo solucionar cada problema individualmente. La recomendación es que uses estos tutoriales como una oportunidad para practicar tus habilidades de escribir código en un contexto biológico.

<h2>Configurar tu sesión de RStudio</h2>

Si nunca has usado R, un lenguaje de programación para análisis estadísticos, ni RStudio, una interfaz gráfica de usuario, recomiendo revisar el tutorial [R for Reproducible Scientific Analysis](https://swcarpentry.github.io/r-novice-gapminder-es/) de [Software Carpentry](https://software-carpentry.org/).

Cuando hayas instalado R y RStudio en tu computadora, puedes hacer clic en el ícono de RStudio para abrir el programa. La configuración predeterminada de los paneles de RStudio se debería de ver algo así, aunque el color de fondo puede ser diferente:

<br>
Una imagen de la configuración predeterminada de los paneles de RStudio, con el panel de la consola debajo del panel de la fuente
Con esta configuración de paneles puede ser difícil ver el código escrito y guardado en archivos en el panel de la fuente, así como el resultado de ese código en el panel de la consola. Puedes reconfigurar los paneles para que el panel de la fuente esté al lado izquierdo del panel de la consola, y así facilitará ver los resultados de tu código inmediatamente. Puedes seguir los siguientes pasos para reconfigurar los paneles en RStudio:

* Selecciona la opción "Tools" en el menú 

* Selecciona la opción "Global Options" en el menú desplegable que sale en "Tools"

* Se va a abrir otra ventana con opciones. Selecciona la opción "Pane Layout" a la izquierda 

* Usa el menú desplegable para seleccionar "Source" como el panel en la primera fila y al lado izquierdo, y selecciona "Console" como el panel que ocupará la siguiente parte de la primera fila de paneles a tu mano derecha

* Puedes seleccionar "Apply" para aplicar estos cambios y luego "Ok" para salir de esta ventana

Tu configuración de paneles en RStudio ahora se debería de ver así:

<br>
Una imagen de la configuración modificada de los paneles de RStudio, con el panel de la consola al lado derecho y el panel de la fuente al lado izquierdo

Otro cambio que puedes implementar en tu configuración de RStudio es el retorno automático, para no tener que hacer scroll a tu derecha cada vez que quieres leer una línea completa de texto o código. Para implementar este cambio, puedes ir a "Tools", luego "Global Options", seleccionar "Code", y seleccionar la caja para la opción "Soft-wrap R source files", luego hacer clic en "Apply" y "Ok".

También puedes cambiar el tamaño de la fuente del texto y código que escribes, tanto como el color de texto y código, y el color de fondo de tu ventana de RStudio. Después de seleccionar "Tools" y "Global Options", puedes seleccionar "Appearance" para ver diferentes opciones.

<h2>Crear una versión local de un repositorio de GitHub</h2>

Si nunca has usado GitHub, recomiendo bajar el programa [GitHub Desktop](https://docs.github.com/es/desktop). Este programa es una interfaz gráfica de usuario para la plataforma de GitHub, que provee un sistema de control de versiones. Vamos a seguir los siguientes pasos para crear una versión local del repositorio de ABISSMAL que está en GitHub para que puedas acceder las funciones de R de ABISSMAL en tu propia computadora. Si ya sabes cómo usar GitHub y cómo usar Git en el terminal, puedes seguir las instrucciones que tenemos en el [README de ABISSMAL](https://github.com/lastralab/ABISSMAL).

Después de instalar GitHub Desktop:

* Haz clic en el ícono de GitHub Desktop para abrir el programa

* Abre tu navegador web y ve al repositorio de ABISSMAL en GitHub: https://github.com/lastralab/ABISSMAL

* Haz clic en el botón verde de "Code" y copia la URL debajo de la opción "HTTPS" en el menú desplegable

* Ve al menú de GitHub Desktop y selecciona "File"

* Selecciona "Clone repository"

* Selecciona la pestaña "URL"

* Pega la URL de ABISSMAL que copiaste de GitHub en la caja que pide un "Repository URL or GitHub username and repository"

* Revisa que el directorio en la caja "Local path" es la ubicación en tu computadora donde quieres instalar el repositorio de ABISSMAL. Por ejemplo, si "Local path" es "/home/YourUserName/Desktop/ABISSMAL", el repositorio de ABISSMAL se instalará directamente en tu Desktop

* Selecciona "Clone" cuando estés lista para crear una versión local del repositorio de ABISSMAL en tu computadora

Cuando el repositorio se haya instalado en tu computadora, deberías de poder ver el siguiente directorio y una lista de archivos dentro de una carpeta llamada "ABISSMAL":

<br>
Una imagen del directorio de la versión local del repositorio de ABISSMAL

Los archivos que vamos a usar en los siguientes tutoriales están adentro de la carpeta "R". Esta carpeta contiene 6 archivos de R (extensión ".R"), un archivo README que contiene más información sobre cada archivo de R, y carpetas con los tutoriales en formato RMarkdown (extensión ".Rmd"), y también código para pruebas unitarias automatizadas.

<h2>Procesar y analizar datos con ABISSMAL</h2>

ABISSMAL provee 5 funciones diferentes de R para procesar y analizar datos, y describimos estas funciones en más detalle abajo, en el orden general en que se deberían de usar. Puedes encontrar más información detallada sobre estas funciones en el archivo README de la carpeta "R", y también en el manuscrito asociado con ABISSMAL:

1. `combine_raw_data` automáticamente combina hojas de cálculo de los datos originales que fueron colectados por día y los guarda en una sola hoja de cálculo a través de todos los días de colección de datos. Esta concatenación de datos se realiza por cada tipo de sensor, por ejemplo, los sensores de rayos infrarrojo o una cámara de infrarrojo, y no cambia ni reemplaza los datos originales. Esta función puede usar datos de los sensores de RFID ("radio frequency identification"), los sensores infrarrojo, la cámara, o el sensor de temperatura de ABISSMAL. Las siguientes funciones no aceptan datos de temperatura

2. `detect_perching_events` toma como entrada los resultados de `combine_raw_data` y detecta grupos de detecciones que ocurrieron cerca en el tiempo como eventos de posar. Estos eventos de pose representan periodos de tiempo cuando un individuo estuvo postrado en la antena de RFID (como percha) situado en la entrada del contenedor de nido. La función usa datos de los sensores ubicados en la entrada del contenedor (RFID o los sensores de infrarrojo) y devuelve una hoja de cálculo de las coordenadas temporales de los eventos de posar inferidos

3. `preprocess_detections` usa como entrada los resultados de `combine_raw_data` y remueve detecciones que ocurrieron muy cerca en el tiempo. Esta función devuelve una hoja de cálculo de datos pre-procesados por tipo de sensor, y en cada hoja de cálculo, las detecciones consecutivas deberían de estar separadas por uno o más umbrales temporales predeterminados. Por ejemplo, cuando usas un umbral temporal de 1 segundo para filtrar las detecciones originales, solo una detección puede ocurrir por segundo en los datos procesados

4. `detect_clusters` usa como entrada los resultados de `preprocess_detections` obtenidos con dos o más tipos de sensores. La función identifica detecciones a través de dos o más tipos de sensores que ocurrieron cerca en el tiempo, y devuelve información temporal y metadatos sobre cada grupo o `cluster` (cúmulo). Cada `cluster` de detecciones representa un evento discreto de movimiento de uno o más individuos

5. `score_clusters` usa como entrada los resultados de `detect_clusters`. Esta función también puede usar los resultados de `detect_perching_events` para integrar los eventos de posar que fueron identificados en los datos originales de RFID o los sensores de infrarrojo, y puede usar los resultados de `preprocess_detections` para integrar los eventos de grabación de vídeos que no fueron incluidos en los `clusters` detectados por `detect_clusters`. Esta función hace inferencias de comportamiento de los eventos de movimiento, incluyendo la dirección de movimiento, la magnitud de movimiento, la identidad del individuo (cuando datos de RFID se encontraron en un `cluster`), y en dónde ocurrió el inicio de la secuencia de movimiento (en la entrada o adentro del contenedor de nido). La función devuelve una hoja de cálculo de inferencias de comportamiento y otros metadatos sobre cada evento de movimiento, y estos resultados se pueden usar para visualizaciones y análisis estadísticos.

<br>
La figura 4 del manuscrito de ABISSMAL con un con las 5 funciones primarias
* Esta figura es de Smith-Vidaurre, G., Molina, T., Jarvis, E.D., and E.A. Hobson. 2023. Automated tracking of avian parental care. [EcoEvoRxiv preprint]((https://ecoevorxiv.org/repository/view/6268/)).

<h2>Solucionar errores en línea</h2>

Mientras escribes y ejecutas código encontrarás errores que a veces pueden ser frustrantes. Experimentar y solucionar los errores que te salen es una parte muy importante de tu proceso de aprendizaje en R (u otros lenguajes de programación). Los errores surgen por diferentes razones, incluyendo errores de mecanografía mientras escribes código, problemas con las versiones de paquetes externos de R que instalaste, o posiblemente por necesitar funciones de paquetes que no has instalado en tu computadora. Los errores a veces pueden surgir por problemas con las funciones de ABISSMAL que usarás en los siguientes tutoriales, o por errores con el código en los tutoriales mismos.

Cuando experimentas un error con tu código, es importante intentar solucionar el error independientemente antes de suponer que el error nació de errores de las funciones de ABISSMAL o los tutoriales. Hay muchos recursos en línea que puedes usar para solucionar errores comunes o inusuales en R. Puedes empezar con copiar y pegar el mensaje de error que ves en tu consola en un buscador, y así deberías de ver varias opciones de foros públicos dónde otras personas han consultado y solucionado errores similares. También deberías de poder de usar herramientas de IA generativo como ChatGPT para buscar errores de mecanografía u otros problemas con tu código. Otra opción útil es leer la documentación de R para investigar si el error que ves esta relacionado con un paquete o una función que puede ser una dependencia de ABISSMAL.

Ya cuando hayas investigado cuidadosamente un error, y estas segura de que el error no se debe a un error de mecanografía o problemas con la estructura de tus datos, luego puedes considerar si el error se debe a un problema con las funciones de ABISSMAL o los tutoriales mismos, y puedes reportar el error a las desarolladoras de ABISSMAL en GitHub (ver la siguiente sección).

<h2>Reportar errores en GitHub</h2>

Es posible que encuentres errores mientras trabajas en cada tutorial, incluyendo errores con código que no ejecuta, o código que devuelve resultados incorrectos. Estos errores se pueden manifestar desde las funciones de ABISSMAL o con el código de algún tutorial. Si encuentras un error en una función de ABISSMAL, puedes crear un "Issue" (una tarea o problema) en el repositorio de GitHub. Para crear un "Issue" nuevo, puedes seleccionar "New Issue" en la página de [Issues](https://github.com/lastralab/ABISSMAL/issues) en el repositorio de ABISSMAL, y seguir las instrucciones en el esquema del "Issue" nuevo para añadir la información que las desarrolladoras necesitan para trabajar efectivamente en el error. También puedes añadir la etiqueta de "bug" (o error) a tu "Issue". Si encuentras un error con los tutoriales puedes crear un "Issue" usando los mismos pasos, y deberías de clarificar que el error está relacionado al código de algún tutorial en particular.

En el siguiente tutorial, vamos a crear datos simulados de movimiento de animales para aprender cómo usar las cinco funciones primarias de ABISSMAL.

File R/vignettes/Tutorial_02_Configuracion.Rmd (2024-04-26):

---
title: "Tutorial 02: Configuración"
author: "Grace Smith-Vidaurre"
date: "2023-12-27"
output: 
  html_document:
    css: "styles.css"
    toc: true
    toc_float: true
    toc_depth: 4
---

```{r setup, include = FALSE}

knitr::opts_chunk$set(echo = TRUE, eval = FALSE)

```

<h2>Información sobre esta traducción</h2>

Este tutorial fue traducido al español por Grace Smith-Vidaurre y editado por Tania Molina, siguiendo las [convenciones de traducción de los Carpentries](https://github.com/Carpentries-ES/board/blob/master/Convenciones_Traduccion.md), incluyendo usar el género femenino por defecto. Si encuentras errores de ortografía que impiden tu habilidad de completar los tutoriales, por favor reporta los errores de ortografía a GitHub usando los pasos en el primer tutorial para reportar un "Issue".

<h2>Resumen del tutorial y objetivos de aprendizaje</h2>

En este segundo tutorial, vamos a configurar tu espacio de trabajo virtual para sesiones de código en R y para usar las funciones de ABISSMAL. Vas a aprender habilidades básicas de programación en R y mejores prácticas de la ciencia abierta para escribir código, incluyendo cómo:

1. Usar archivos de RMarkdown
2. Limpiar tu ambiente global
3. Ejecutar código adentro de un "chunk" (trozo, pedazo) de RMarkdown
4. Aprender sobre funciones en R y su documentación
5. Instalar y acceder paquetes
6. Comentar tu código
7. Atajos de RStudio para escribir código
8. Crear y usar una carpeta o un directorio de trabajo

<h2>Uso de archivos de RMarkdown</h2>

Cada tutorial en esta serie de tutoriales está disponible como un archivo de RMarkdown (extensión .Rmd) y también como un archivo de HTML que puedes abrir y ver en tu navegador favorito. Cada archivo de HTML fue generado para entrelazar el archivo de RMarkdown, o convertir el texto y el código junto con los resultados del código en un reporte en formato HTML. Puedes leer [la documentación de RMarkdown](https://rmarkdown.rstudio.com/lesson-1.html) o este tutorial por [Teresa Boca en RPubs](https://rpubs.com/tereboca/informe_rmakrdown) para aprender más sobre cómo usar RMarkdown para escribo código y generar reportes.

Los archivos de RMarkdown facilitan el proceso de compartir tu código y tus resultados. Si nunca has usado RMarkdown, la mejor forma de completar los tutoriales será crear un archivo de RMarkdown nuevo para cada tutorial y escribir el código por ti misma. Aprenderás más si escribes el código y los comentarios (adentro y afuera de cada trozo de código) en tus propias palabras. También puedes abrir el reporte HTML de cada tutorial en tu navegador para tener una guía mientras escribes el código de cada tutorial en tu propio archivo de RMarkdown. Como otra alternativa, puedes abrir el archivo de RMarkdown del tutorial al lado de tu propio archivo de RMarkdown si añades una tercera columna a la configuración de tus paneles de RStudio. Para ello debes seleccionar lo siguiente:

* "Tools"
* "Global Options"
* "Pane Layout"
* "Add Column" para añadir otro panel de fuente en una tercera columna
* Luego puedes abrir el tutorial original en un panel de fuente, y tu propio archivo de RMarkdown en el otro panel de fuente

Si ya tienes experiencia con escribir código en R y usar archivos de RMarkdown, puedes abrir el archivo original de RMarkdown de un tutorial y ejecutar el código adentro de cada trozo (chunk) para completar cada tutorial (con algunas modificaciones de los directorios para usar los directorios y archivos de tu computadora). Si quieres preservar el código original en cada archivo de RMarkdown, puedes crear una copia de cada tutorial y modificar las copias mientras completas cada tutorial.

<h2>Limpiar tu ambiente global</h2>

Tu ambiente global es tu espacio virtual en R, y puede contener paquetes y objectos diferentes que facilitarán tus objetivos de programación y/o analizar datos. Puedes ver los paquetes y objetos que existen en tu ambiente con hacer clic en la pestaña de ambiente o "Environment" en el mismo panel que incluye las pestañas de "History" y "Connections".

Si iniciaste una sesión nueva de RStudio puede que tu ambiente global esté vacío. Pero si estás trabajando en una sesión vieja, o en un ambiente de un proyecto de R (RProject), tu ambiente global ya puede contener paquetes y objetos. Limpiar tu ambiente global es una buena práctica a seguir cada vez que empieces una sesión de código. Si no limpias tu ambiente global, incluso cuando uses el mismo código entre sesiones, corres el riesgo de usar versiones viejas de objetos que no reflejan los cambios más recientes en tu código.

Puedes limpiar tu ambiente global directamente de la interfaz de RStudio con hacer clic en el ícono de la escoba debajo de la pestaña de "Environment" (haz clic en "Yes" con "hidden objects" para limpiar objetos escondidos también).

También puedes limpiar tu ambiente global ejecutando el código que se detalla abajo. Puedes ejecutarlo dentro del siguiente trozo de formas diferentes:

* Haz clic en el ícono de la flecha verde en la parte superior derecha del trozo de código para ejecutar solamente el código en este trozo

* Puedes ubicar tu cursor (y hacer clic) en cualquiera posición adentro de la línea de código, y luego navegar al ícono de "Run" en la parte superior derecha del panel de fuente que tiene un cuadro blanco y una flecha verde. En el menú desplegable, selecciona "Run Selected Lines" o "Run Current Chunk" (para usar los atajos de cada comando, ve los siguientes dos puntos). "Run Selected Lines" ejecutará la línea de código en donde esté tu cursor, y "Run Current Chunk" ejecutará todo el código adentro del trozo (independientemente de la posición de tu cursor)

* Puedes ubicar tu cursor (y hacer clic) en cualquiera posición adentro de la línea de código, y usar el atajo de "Ctrl" + "Enter" para ejecutar la línea de código donde esté tu cursor

* Para ejecutar todo el código en el trozo (chunk), puedes usar el atajo "Ctrl" + "Shift" + "Enter"

El primer atajo arriba (para ejecutar una línea de código a la vez), es muy útil para poder ver los resultados de cada línea de código y buscar errores.
```{r}

rm(list = ls())

```

El código arriba para limpiar tu ambiente global es una expresión anidada con dos funciones: `rm()` y `ls()`. La notación de `()` se usa para funciones en R. Las funciones son operaciones que puedes aplicar en tu propio código usando el nombre de una función específica. R tiene una colección de funciones básicas que puedes acceder sin necesitar un paquete específico, incluyendo las dos funciones arriba (`rm()` y `ls()`).

<h2>Acceder documentación de funciones de R</h2>

Puedes acceder la documentación para las funciones que usaste arriba con hacer clic en la pestaña de "Help" en el panel que incluye "Files" y "Plots", o puedes escribir el nombre de la función en la barra de búsqueda en el panel de "Help". También puedes acceder la documentación de funciones ejecutando el siguiente código:
```{r}

?rm

```

```{r}

?ls

```

La documentación de cada función contiene secciones específicas que pueden ser útiles para entender el uso y el propósito de la función, sobre todo los argumentos de la función. Estos argumentos son los valores que la función requiere de la usuaria para poder guiar o modificar la operación. Muchas funciones tienen valores por defecto para algunos de sus argumentos que se usarán cuando no asignas valores específicos.

Por ejemplo, la función `rm()` tiene un argumento `list()` (seguido por un `=` o signo de igual, que se usa para asignar un valor específico a un argumento). Necesitas proveer información después del argumento `list()` para que `rm()` limpie tu ambiente global de la forma que quieres. Para eliminar todo en tu ambiente global, estamos usando los resultados de la función `ls()`, que imprime los nombres de todos los objetos en tu ambiente global.

<h2>Instalar y cargar paquetes</h2>

Después de limpiar tu ambiente global, necesitas configurar tu espacio virtual de trabajo para preparar tu sesión de código y empezar a analizar datos. Un paso importante es asegurarte de que puedes acceder funciones que necesitas pero que no están disponibles a través de la colección de funciones básicas de R. Por ejemplo, [el `tidyverse`](https://www.tidyverse.org/) es una colección de paquetes de R que provee funciones y expresiones básicas útiles para analizar datos.

Si no has instalado el `tidyverse` en tu computadora local, necesitas instalar esta colección de paquetes para acceder estas funciones de análisis de datos. El código siguiente instala el `tidyverse` de [CRAN](https://cran.r-project.org/), el "Comprehensive R Archive Network" en línea que contiene miles de paquetes de R.
```{r}

# Instala el tidyverse de CRAN
install.packages("tidyverse")

```

En el trozo de arriba, añadí un comentario antes del código usando el símbolo de `#`, un signo numeral o `hashtag`. Cualquier texto que escribes después de un `hashtag` será ignorado cuando ejecutas tu código. Es buena práctica comentar tu código, sobre todo cuando estés aprendiendo cómo escribir código en R. Para biólogas, comentar tu código incluso cuando eres experta también es una muy buena práctica. Comentar tu código es una forma de documentar tu trabajo y sirve para hacer el código que publicas con manuscritos o herramientas más accesible y entendible para otros en la comunidad.

Cuando hayas instalado el `tidyverse` en tu computadora no necesitas instalarlo otra vez (por ejemplo, la siguiente vez que abres RStudio ya estará disponible). Lo único que necesitas hacer cada vez que abres otra sesión de RStudio es cargar el paquete en tu ambiente global para poder acceder las funciones contenidas adentro de la colección de paquetes del `tidyverse`.
```{r}

library(tidyverse)

```

<h2>Atajos para escribir código</h2>

RStudio tiene varios atajos útiles para escribir código. Puedes encontrar estos atajos yendo a "Tools" en el menú de RStudio, y luego seleccionando "Keyboard Shortcuts Help", que debería de abrir una ventana nueva con todos los atajos por defecto en RStudio. Arriba aprendiste sobre unos atajos para ejecutar código dentro de un trozo (chunk) de RStudio. Otros atajos útiles son "Shift + Ctrl + C", que puedes usar para comentar o silenciar de una a múltiples líneas de código a la vez (es decir, convertir líneas de código en comentarios), y "Ctrl + Alt + I", que automáticamente crea un trozo nuevo de RMarkdown.

RStudio también contiene un atajo de autocompletar usando el tabulador (la tecla que dice "tab"). Por ejemplo, en el trozo de abajo, después de escribir `libr` y hacer clic en el tabulador, deberías de poder ver una ventana pequeña que demuestra todas las funciones, paquetes u objetos disponibles que empiezan en el patrón "libr". Puedes usar las teclas con flechas (arriba, abajo, etc) para seleccionar la opción que quieres, y "Enter" para completar la línea (por ejemplo, para escribir `library()` para cargar un paquete).
```{r eval = FALSE}

libr

```

<h2>Resolver frases incompletas en la consola</h2>

Es importante vigilar el panel de la consola mientras escribes y ejecutas código en RStudio. El símbolo de `>` (o "mayor que") en la consola significa que la consola terminó de ejecutar código y está lista para otra operación. Cuando ves el símbolo de `+` (o "más") en la consola, este símbolo indica que la frase de código que acabas de ejecutar no está completa. Las frases incompletas de código surgen de errores de mecanografía, como cuando te faltó abrir o cerrar los paréntesis en una función. Abajo hay un ejemplo de una frase incompleta de código:
```{r eval = FALSE}

library(tidyverse

```

Deberías de ver que el símbolo de `+` aparece en la consola cuando ejecutas el código arriba, porque te faltó un paréntesis para cerrar la función `library()`. Tienes dos opciones para resolver este problema. Primero, si sabes que símbolo te falta para completar la frase, puedes escribir este símbolo directamente en la consola y terminar de ejecutar el código con seleccionar "Enter". La segunda opción que tienes es hacer clic en la consola y luego seleccionar "Esc", que va a borrar la frase incompleta de la consola y reiniciar la consola para que puedas ejecutar más código (después de corregir tu error en el código en el panel de la fuente). Es buena práctica vigilar la consola para revisar que el código que ejecutas produce resultados o errores. Si ejecutas muchas frases de código a la vez y no observas los resultados que esperas en la consola, puede que tengas una frase incompleta por allí, y sería mejor limpiar la consola y revisar bien tu código antes de ejecutarlo otra vez.

<h2>Crear tu directorio de trabajo</h2>

El siguiente paso en el proceso de configurar tu espacio virtual de trabajo, es decidir donde estará tu directorio de trabajo para tu sesión de código. Un directorio es una ubicación física en tu computadora (o una carpeta) donde R va a buscar archivos para leer o cargar datos. Cuando escribes datos de R como archivos físicos, estos archivos físicos se crearán en tu directorio de trabajo.

Puedes usar la función `getwd()` para revisar tu directorio actual de trabajo.
```{r eval = TRUE}

getwd()

```

Mi directorio de trabajo por defecto es la carpeta en mi computadora donde guardé este archivo de RMarkdown. Para trabajar en un directorio aparte que contiene solo los datos generados en estos tutoriales, puedes crear un directorio nuevo o carpeta nueva en tu computadora:
```{r}

?dir.create

dir.create("/home/gsvidaurre/Desktop/ABISSMAL_tutoriales")

```

En el código arriba, deberías de reemplazar el `path`, o la combinación de directorios (en este ejemplo, el `path` es "/home/gsvidaurre/Desktop/ABISSMAL_tutoriales") para que represente la ubicación en tu computadora donde quieres guardar la carpeta nueva que se llamará `ABISSMAL_tutoriales` (u otro nombre que prefieras). Si usas el sistema operativo de Windows, tienes que cambiar la dirección de los símbolos de barra porque el `path` que aparece en Windows para una carpeta va a tener barras invertidas (`\`) y R acepta solo barras inclinadas (`/`) en un `path`.

Es común configurar tu directorio de trabajo con la función `setwd()` según cursos preliminares de programación en R. Sin embargo, es buena práctica evitar usar `setwd()` en código que quieres compartir con colaboradores o código que quieres compartir con la comunidad en general siguiendo la filosofía de ciencia abierta, por ejemplo cuando publicas un articulo o compartes una nueva herramienta. Usar `setwd()` cuando compartes tu código es suponer que todos los que van a usar tu código tienen el mismo directorio de trabajo en su computadora y esto es muy poco probable. Hay otras formas en que puedes especificar tu directorio de trabajo a través de tu código sin depender de `setwd()`.

Por ejemplo, digamos que quieres crear una copia del primer tutorial y luego guardar esa copia adentro del directorio que creamos arriba. Podemos usar funciones de la colección base de R para copiar y guardar este archivo al directorio correcto de trabajo. Para evitar errores, vas a necesitar actualizar los `paths` abajo para que representen la carpeta en tu computadora con los tutoriales, y también tu directorio de trabajo:
```{r}

file.copy(
  from = "/home/gsvidaurre/Desktop/GitHub_repos/ABISSMAL/R/vignettes/Tutorial_01_Introduccion.Rmd",
  to = "/home/gsvidaurre/Desktop/ABISSMAL_tutoriales/Tutorial_01_Introduccion_copy.Rmd"
    )

```

En el código arriba especificamos dos argumentos a la función `file.copy()`. El primer argumento especifica la ubicación del archivo que queremos copiar ("/home/gsvidaurre/Desktop/GitHub_repos/ABISSMAL/R/vignettes/") y el nombre del archivo mismo ("Tutorial_01_Introduccion.Rmd"). El segundo argumento especifica la ubicación donde queremos guardar la copia que vamos a crear de este archivo ("/home/gsvidaurre/Desktop/ABISSMAL_tutoriales/") y un nombre nuevo para la copia que vamos a crear ("Tutorial_01_Introduccion_copy.Rmd"). Los `paths` en cada argumento están entrecomillas en cada argumento, para indicar que la información entrecomillas se debería de tratar como el tipo de datos `character` en R, que es un término formal para la información en formato de texto.

El resultado en la consola debería de ser "[1] TRUE" si el archivo se copió y se guardó correctamente después de que ejecutaste el código. Puedes revisar que la función ejecutó bien navegando a la carpeta donde se debió de haber guardado el archivo copiado, y ver que la copia existe. También puedes usar la función base de R `list.files()` desde RStudio para revisar si el archivo que copiaste existe en tu directorio de trabajo. El resultado de `list.files()` es una lista de todos los archivos adentro de tu directorio de trabajo y esta lista debería de contener un solo archivo: "Tutorial_01_Introduccion_copy.Rmd".
```{r}

list.files(path = "/home/gsvidaurre/Desktop/ABISSMAL_tutoriales")

```

El código arriba es un ejemplo sobre cómo puedes especificar tu directorio de trabajo en el código que escribes sin tener que depender de `setwd()`. En los siguientes tutoriales vas a ver otros ejemplos sobre cómo puedes leer archivos o crear archivos en tu directorio de trabajo sin la función `setwd()`. Antes de empezar el siguiente tutorial, puedes borrar el archivo que copiaste a tu directorio de trabajo:
```{r}

file.remove("/home/gsvidaurre/Desktop/ABISSMAL_tutoriales/Tutorial_01_Introduction_copy.Rmd")

```

En el siguiente tutorial vas a crear y manipular objetos en R que puedes usar para procesar y analizar datos con ABISSMAL.

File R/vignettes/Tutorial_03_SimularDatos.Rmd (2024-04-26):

---
title: "Tutorial 03: Simular Datos"
author: "Grace Smith-Vidaurre"
date: "2023-12-27"
output: 
  html_document:
    css: "styles.css"
    toc: true
    toc_float: true
    toc_depth: 4
---

```{r setup, include = FALSE}

knitr::opts_chunk$set(echo = TRUE, eval = TRUE)

```

<h2>Información sobre esta traducción</h2>

Este tutorial fue traducido al español por Grace Smith-Vidaurre y editado por Tania Molina, siguiendo las [convenciones de traducción de los Carpentries](https://github.com/Carpentries-ES/board/blob/master/Convenciones_Traduccion.md), incluyendo usar el género femenino por defecto. Si encuentras errores de ortografía que impiden tu habilidad de completar los tutoriales, por favor reporta los errores de ortografía a GitHub usando los pasos en el primer tutorial para reportar un "Issue".

<h2>Resumen del tutorial y objetivos de aprendizaje</h2>

En este tercer tutorial, vamos a crear datos simulados de movimientos de animales que fueron detectados por diferentes sensores. El proceso de simular estos datos sustituye el proceso de colección de datos que proporciona ABISSMAL para grabar datos de animales en vivo. Estos datos simulados te van a generar más oportunidades para practicar habilidades básicas de escribir código y tener control sobre la creación de estos datos te ayudará a entender los diferentes pasos del análisis de datos que se mencionan a continuación. Si quieres ver datos recolectados de pájaros con el `software` de ABISSMAL, y el código que usamos para analizar esos datos, puedes revisar el preprint del [manuscrito de metodos](https://ecoevorxiv.org/repository/view/6268/) que tiene enlaces a los datos mismos y al código que son públicamente accesibles.

A través del proceso de simulción de datos en este tutorial, vas a continuar usando tus habilidades de programación que aprendiste en el segundo tutorial, y vas a aprender más sobre:

1. Cómo crear objetos como vectores y `dataframes`
2. Tipos de datos en R
3. Cómo indexar y manipular objetos
4. Cómo usar frases condicionales
5. Expresiones de `pipe` en el `tidyverse`

<h2>Cargar paquetes</h2>

En el tutorial anterior aprendiste cómo instalar el `tidyverse`, una colección de paquetes para la ciencia de datos. También aprendiste sobre directorios de trabajo y creaste un directorio nuevo en tu computadora para guardar archivos de datos o imágenes que vas a generar en los siguientes tutoriales.

Cada vez que inicias un archivo nuevo de RMarkdown o R, es importante configurar tu espacio virtual antes de empezar a analizar datos. Con el trozo de abajo, vas a limpiar tu ambiente global y cargar el `tidyverse` usando código que viste en el segundo tutorial, pero ahora todo el código está combinado en un solo chunk (trozo).
```{r message = FALSE, warning = FALSE}

rm(list = ls()) # Limpia tu ambiente global

library(tidyverse) # Carga la colección de paquetes en el tidyverse

```

<h2>Crear un objeto de `path` (ubicación)</h2>

El siguiente paso será especificar la ubicación de tu directorio de trabajo. En el segundo tutorial, usaste un `string`, o una secuencia de caracteres entrecomillas para especificar el `path` de tu directorio de trabajo mientras usabas funciones diferentes. En vez de copiar y pegar la misma secuencia de caracteres o "string" cada vez que quieres usar este `path`, es más eficiente almacenar esta secuencia de caracteres (que especifica el `path` de tu directorio de trabajo) adentro de un objeto nuevo, y luego usar el nombre del objeto cuando necesitas especificar el `path`.

Para crear un objeto de tu propio `path`, puedes escribir el nombre del objeto que quieres crear al lado izquierdo del trozo (sin comillas), luego los símbolos para crear un objeto en R (`<-`), y finalmente la información que quieres asignar a este objeto. En este caso, la información que quieres guardar adentro de este objeto es tu directorio de trabajo en el formato de un `string`, y esta información necesita estar entrecomillas.
```{r eval = TRUE}

path <- "/home/gsvidaurre/Desktop/ABISSMAL_tutoriales"

```

En el código arriba, creaste un objeto que se llama `path`. Puedes ver la información que contiene este objeto con escribir el nombre del objeto y ejecutar ese código en la consola:
```{r eval = TRUE}

path

```

También puedes ver el contenido de `path` con hacer clic en la pestaña de "Environment" y revisar la columna al lado derecho del nombre del objeto. Ahora puedes confirmar que `path` es un objeto nuevo que contiene información sobre tu directorio de trabajo y está disponible en tu ambiente global para más operaciones.

Puedes practicar eliminar solamente el objeto `path` de tu ambiente global con escribir y ejecutar el código `rm(list = "path")`. Después de ejecutar este código, deberás de inicializar `path` otra vez usando el código de arriba.

<h2>Crear marcas de tiempo para detecciones simuladas de movimientos</h2>

Los datos primarios que colecta ABISSMAL son marcas de tiempo que indican el momento en el tiempo cuando un sensor se activó y grabó movimiento. Muchas (pero no todas) de estas detecciones se pueden asignar a uno o más animales que se movieron cerca de un sensor, por ejemplo, cuando un pájaro entra a un contenedor de nido a través de una antena circular de RFID ("radio frequency identification") instalado en la entrada del contenedor. En los siguientes trozos de código, vamos a generar datos simulados que representan datos de detecciones grabados por el sensor de RFID y también sensores de infrarrojo.

Digamos que estamos recolectando datos para dos pájaros adultos a través de sensores de ABISSMAL montados en un contenedor de nido. La antena de RFID está montada en la entrada del contenedor, y un par de sensores de infrarrojo, el par "externo", está montado enfrente de la antena de RFID para capturar movimientos afuera de la entrada del contenedor. Un segundo par de sensores de infrarrojo, el par "interno", está montado detrás de la antena de RFID para capturar movimientos adentro de la entrada del contenedor. En este ejemplo simulado, el par externo de sensores infrarrojo se va a activar cuando un pájaro entra al contenedor de nido, luego se activará la antena de RFID, y por último el par interno de sensores infrarrojo. Cuando un pájaro sale del contenedor, el par interno de sensores infrarrojo debería de activarse primero, luego la antena de RFID, y finalmente el par externo de sensores infrarrojo. Esto indicará la dirección del pájaro: entrando o saliendo.

Empezaremos con crear un objeto que contiene las marcas de tiempo simuladas para la antena de RFID. Este objecto se llamara `rfid_ts` y va a contener cuatro marcas de tiempo en formato de horas:minutos:segundos. Cada marca de tiempo estará entrecomillas para indicar que estamos usando información de texto o secuencia de caracteres en el formato `string` de R.

Vas a combinar estas marcas de tiempo adentro de un solo objeto usando la función `c()`. Esta función concatena valores separados por comas en un objecto de tipo vector o lista. Arriba creaste un objeto que se llama `path` sin usar `c()`, pero este objeto tenía un solo valor o elemento. Usar `c()` facilita combinar múltiples valores en un objeto como un vector que puede tener múltiples elementos.
```{r}

# Crea un vector de cuatro marcas de tiempo de RFID o cuatro elementos en formato HH:MM:SS
rfid_ts <- c("10:00:00", "10:05:00", "11:00:00", "11:05:00")
  
```

Puedes ver las propiedades diferentes del objeto `rfid_ts`:
```{r}

rfid_ts # Ejecuta el nombre del objeto para ver su contenido

is.vector(rfid_ts) # Un valor binario indica si rfid_ts es un vector (TRUE) o no (FALSE)

class(rfid_ts) # Un vector de tipo de dato `character` en R, o tipo `string`

length(rfid_ts) # Este vector tiene cuatro elementos

```

Continuemos simulando dos movimientos de entrada y dos movimientos de salida del contenedor. Podemos escoger marcas de tiempo para el par externo de sensores de infrarrojo que preceden las marcas de tiempo de RFID y marcas de tiempo del par interno de sensores infrarrojo que siguen las marcas de tiempo de RFID para simular un evento de entrada. Podemos simular eventos de salida con las marcas de tiempo en el orden opuesto (el par interno de sensores se activa primero, luego RFID, luego el par externo de sensores de infrarrojo). Vamos a separar las detecciones de cada sensor adentro de cada movimiento de entrada y salida por un segundo. Aquí "IRBB" significa "infrared beam breakers" o sensores de infrarrojo.
```{r}

# Simula marcas de tiempo para el par externo ("o_") e interno ("i_") de sensores infrarrojo para una entrada, una salida, y luego otra entrada y salida
o_irbb_ts <- c("09:59:59", "10:05:01", "10:59:59", "11:05:01") # externo
i_irbb_ts <- c("10:00:01", "10:04:59", "11:00:01", "11:04:59") # interno

```

Los pájaros a veces posan en la entrada del contenedor usando la antena de RFID como percha, y los sensores deberían de colectar datos sobre este comportamiento. Puedes añadir eventos de posar a los datos simulados, y aquí vas a simular eventos de posar solamente con los datos de RFID.
```{r}

rfid_ts <- c(rfid_ts, "08:00:00", "08:00:01", "08:00:02", "08:00:03", "11:30:00", "11:30:01", "11:30:02", "11:30:03", "11:30:04", "11:30:05")

```

En el código arriba, modificaste el objeto `rfid_ts` con la función `c()` para añadir diez más marcas de tiempo a este vector para tener un total de 14 elementos. Revisa la estructura del objeto modificado de `rfid_ts` usando la función `glimpse()`:
```{r}

# Aquí puedes ver la estructura del objeto en un formato que incluye el tipo de dato en R ("chr", que es tipo `character` o `string`), el número de elementos ([1:14]), y los valores de los primeros elementos del vector
glimpse(rfid_ts)

```

Otro tipo de información importante es simular ruido en las detecciones de los sensores. Por ejemplo, la antena de RFID puede fallar en detectar la etiqueta PIT ("passive integrated transponder") de un individuo, y los sensores de infrarrojo pueden activarse cuando los pájaros dejan material de nido colgando en la entrada del contenedor. En ambos casos, los sensores infrarrojo deberían de activar pero no la antena de RFID.
```{r}

# Simula fallas de detección de la antena de RFID a través de ambos pares de sensores infrarrojo
# Estas fallas de detección del sensor de RFID surgieron en cuatro eventos simulados adicionales (dos entradas y dos salidas)
o_irbb_ts <- c(o_irbb_ts, "06:05:05", "06:35:08", "07:15:40", "11:10:25")
i_irbb_ts <- c(i_irbb_ts, "06:05:04", "06:35:09", "07:15:41", "11:10:24")

glimpse(o_irbb_ts)
glimpse(i_irbb_ts)

# Luego simula detecciones de ruido para el par externo de sensores infrarrojo
o_irbb_ts <- c(o_irbb_ts, "09:45:01", "09:45:02", "09:45:03", "09:45:04", "09:45:05", "09:45:06", "09:45:07", "09:45:08", "09:45:09", "09:45:10", "09:45:11")

glimpse(o_irbb_ts)

```

Acabas de crear datos simulados de movimientos de animales con datos que representan errores de detección, pero por el momento estos datos se encuentran en diferentes vectores separados y les faltan metadatos muy importantes. Por ejemplo, metadatos útiles incluyen información sobre la réplica experimental, la fecha, y para los datos de RFID, el código alfanumérico único de cada etiqueta PIT que fue detectada por la antena de RFID. Algunos de estos metadatos son críticos para los análisis más adelante, como la fecha y los códigos de las etiquetas PIT.

Los vectores son estructuras útiles en R, pero una limitación de los vectores es que no puedes combinar diferentes tipos de datos en un solo objeto. Puedes intentar combinar diferentes tipos de datos en un vector:
```{r}

# Crea un vector con los tipos `character`, `numeric`, y `binary` (o sea, datos de texto, valores numéricos, y valores binarios)
# El resultado se debería de imprimir directamente a la consola porque no estas guardando el resultado en un objeto
# Deberías de ver que todos los elementos se forzarán al tipo `character` o `string` entrecomillas
c("1", 1, TRUE, FALSE)

# Ahora crea un vector con datos `numeric` y `binary`
# Deberías de poder ver que todos los elementos se forzarán al tipo `numeric`. Los valores de TRUE y FALSE se convirtieron a los valores numéricos que R usa por defecto para guardar información binaria (TRUE se convierte a 1, y FALSE se convierte a 0)
c(1, 1, TRUE, FALSE)

```

Cuando intentas combinar los tipos de dato `character`, `numeric`, y `binary` en el mismo vector, todos los elementos del vector se convierten al tipo de dato `character`. Algo parecido resulta cuando intentas combinar datos de tipo `numeric` y `binary` en el mismo vector, pero en este caso, los valores se convierten a numérico. En este ejemplo, también aprendiste que los valores binarios TRUE y FALSE en R son equivalentes a los valores numéricos 1 y 0, respectivamente.

<h2>Crear vectores de metadatos</h2>

Para los análisis que siguen, necesitas poder crear metadatos con diferentes tipos de datos, y luego combinar los datos primarios para cada sensor (las marcas de tiempo por sensor) con los metadatos importantes. Puedes empezar con crear vectores de metadatos para las marcas de tiempo de RFID, incluyendo información sobre la réplica experimental, la fecha, y la identidad de la etiqueta PIT para cada detección.

Para crear un vector de metadatos sobre la réplica experimental, vas a usar la función `rep()` para repetir la información sobre la réplica experimental automáticamente, en vez de copiar y pegar la misma información varias veces. Para configurar el número de veces que la información sobre la réplica experimental se va a repetir, también vas a usar la función `length()` que calcula el tamaño del vector `rfid_ts` automáticamente, y comunicarle este resultado a `rep()`. Crear un vector de metadatos que tiene el mismo tamaño (largo) que el vector de `rfid_ts` será útil para combinar estos vectores en un solo objeto más adelante.
```{r}

# La documentación nos dice que rep() espera dos argumentos, `x` y `time`
?rep

# Crea un vector con información sobre la réplica experimental
# El argumento `x` contiene la información de metadatos que se va a repetir
# El argumento `times` especifica la cantidad de veces que esta información se va a repetir
exp_rep <- rep(x = "Pair_01", times = length(rfid_ts))

glimpse(exp_rep)

# También puedes ejecutar código sin escribir los nombres de los argumentos, siempre y cuando los argumentos se escriben en el mismo orden que la función espera:
exp_rep <- rep("Pair_01", length(rfid_ts))

glimpse(exp_rep)

```

Usar `times = length(rfid_ts)` es mejor práctica que configurar el tamaño de `rfid_ts` manualmente (por ejemplo, `times = 14`). Configurar el valor de `times` manualmente es suponer que el objeto `rfid_ts` no ha cambiado adentro de una sesión de escribir código, o entre sesiones diferentes, y esto puede ser una suposición peligrosa. Cuando usas `times = length(rfid_ts)` te aseguras que el código arriba va a crear un vector de metadatos del mismo largo o tamaño que `rfid_ts` sin importar qué tantas modificaciones le hayas hecho a `rfid_ts`.

Puedes también usar una frase condicional (condición) para confirmar que el vector de metadatos es del mismo tamaño que el vector de marcas de tiempo de RFID. Las frases condicionales puede ser útiles para revisar suposiciones en tu código, o para construir nuevos datos y funciones.
```{r}

# Si esta condición se cumple, el resultado en la consola debería de ser "[1] TRUE"
length(rfid_ts) == length(exp_rep)

```

En la frase condicional de arriba, estas usando los símbolos `==` para cuestionar si los dos vectores `rfid_ts` y `exp_rep` tienen la misma cantidad de elementos (si tienen el mismo largo o tamaño).

También puedes usar los símbolos `!=` para preguntar si los dos vectores `rfid_ts` y `exp_rep` *no* tienen la misma cantidad de elementos (o sea, si *no* tienen el mismo largo):
```{r}

# El resultado de esta frase debería de ser FALSE, porque estos vectores tienen el mismo largo
length(rfid_ts) != length(exp_rep)

```

Como un ejemplo, puedes modificar `rfid_ts` para que tenga un número de elementos diferente a `exp_rep`. Abajo puedes ver algunas formas diferentes de filtrar o eliminar cuatro elementos del vector `rfid_ts` para que tenga diez elementos en total.
```{r}

## Crea índices numéricos para filtrar un objeto

# Puedes usar el símbolo `:` para crear una secuencia de números de los índices 5 a lo largo de rfid_ts 
5:length(rfid_ts)

# También puedes usar la función `seq()` para crear la misma secuencia de índices numéricos que ves arriba
seq(from = 5, to = length(rfid_ts), by = 1)

# Si quieres filtrar elementos no consecutivos, puedes crear un vector de índices con la función `c()`
c(1, 3, 5, 6, 8, 10, 11, 12, 13, 14)

## Filtra un vector con índices numéricos

# Cuando insertas cualquiera de las expresiones arriba dentro de los corchetes que vienen después del nombre del vector, puedes seleccionar los elementos del índice 5 a lo largo de rfid_ts, y así eliminar los primeros cuatro elementos
rfid_ts[5:length(rfid_ts)]

rfid_ts[seq(from = 5, to = length(rfid_ts), by = 1)]

rfid_ts[c(1, 3, 5, 6, 8, 10, 11, 12, 13, 14)]

# Puedes usar cualquiera de los métodos arriba para crear una secuencia de índices que quieras eliminar, y luego usar el símbolo `-` dentro de los corchetes para eliminar los elementos en esos índices particulares. Por ejemplo:
rfid_ts[-c(1:4)] # los números deberían de estar adentro de la función `c()` para que funcione el filtro de forma invertida

```

Luego puedes revisar si esta versión modificada de `rfid_ts` es el mismo largo que `exp_rep`:
```{r}

# Esta frase debería de resultar en TRUE, porque es verdad que estos vectores ya no tienen el mismo largo
length(rfid_ts[-c(1:4)]) != length(exp_rep)

```

<h2>Crear `dataframes` con datos primarios y metadatos</h2>

Es importante combinar los metadatos con los datos primarios para análisis futuros, y puedes combinarlos usando un tipo de objeto que se llama un `dataframe` o cuadro de datos. Los `dataframes` son parecidos a las hojas de cálculo porque tienen dos dimensiones (filas y columnas), y puedes guardar múltiples tipos de datos diferentes en el mismo `dataframe`. También puedes guardar `dataframes` en hojas de cálculo o archivos físicos en tu computadora.

Para combinar dos vectores en un solo `dataframe`, los vectores tienen que tener el mismo largo. Cuando intentas combinar dos vectores de largo diferentes, deberías de recibir un mensaje de error en la consola especificando que los dos argumentos no tienen el mismo número de filas:
```{r eval = FALSE}

sim_dats <- data.frame(exp_rep, rfid_ts[-c(1:4)])

# "Error in data.frame(exp_rep, rfid_ts[-c(1:4)]) : 
  # arguments imply differing number of rows: 14, 10"

```

Ahora puedes usar los vectores enteros de `exp_rep` y `rfid_ts` para crear el `dataframe`, y los vectores se van a convertir en las columnas del `dataframe`:
```{r}

sim_dats <- data.frame(exp_rep, rfid_ts)

glimpse(sim_dats)

```

Cuando revisas la estructura del objeto `sim_dats`, el `dataframe` nuevo, puedes ver que tiene 14 filas y dos columnas. Para cada columna (después del símbolo de "$"), puedes ver que el nombre de la columna (`exp_rep` y `rfid_ts`), el tipo de dato en cada columna (en este momento cada columna es del tipo `character`), y luego los valores de cada columna en las primeras filas del `dataframe`.

Puedes cambiar los nombres de cada columna con añadir un nombre nuevo y el símbolo `=` antes de cada vector. Abajo, el vector `exp_rep` se convierte en la columna `replicate` con la réplica experimental y el vector `rfid_ts` se convierte en la columna `timestamps` con las marcas de tiempo.
```{r}

sim_dats <- data.frame(replicate = exp_rep, timestamps = rfid_ts)

glimpse(sim_dats)

```

Podemos añadir metadatos adicionales a este `dataframe`, como información sobre la fecha de colección de datos. Puedes primero añadir una columna para el año usando el tipo de datos `double` en R que es un tipo de dato `numeric`.
```{r}

sim_dats <- cbind(sim_dats, rep(2023, length(rfid_ts)))

glimpse(sim_dats)  

```

La columna del año tiene un nombre extraño cuando añadimos una nueva columna usando `cbind()`, y si revisas el código de arriba, puedes ver que el nombre de esta columna se parece mucho al código que escribiste adentro de `cbind()`. Puedes usar la función `names()` e indexar con corchetes para cambiar el nombre extraño a un nombre mejor, como "year":
```{r}

# Esta función devuelve un vector de los nombres de las columnas del dataframe
names(sim_dats)

# Usa indexar con corchetes y la función ncol() para encontrar el último nombre entre los nombres de todas las columnas, porque esta última columna contiene la información sobre el año
ncol(sim_dats) # Hay 3 columnas en este dataframe

# Esta expresión devuelve el nombre de la última columna
names(sim_dats)[ncol(sim_dats)]

# Puedes sobrescribir el nombre de la última columna con un nombre nuevo
names(sim_dats)[ncol(sim_dats)] <- "year"

# Confirma que el nombre de la columna de año se actualizó de la forma que esperas
names(sim_dats)
glimpse(sim_dats)

```

<h2>Crear `dataframes` usando el `tidyverse`</h2>

En el código anterior, usaste código de R básico para añadir una columna nueva y actualizar el nombre de esa columna. Te tomó varias líneas de código para completar estas operaciones. Puedes reducir la cantidad de código que necesitas para estos pasos si eliminas las líneas de código que usaste para revisar las operaciones. Pero otra forma para reducir la cantidad de código que escribes para esta serie de operaciones es usar la notación y colección de funciones del `tidyverse`:
```{r}

# Crear el dataframe de nuevo con dos columnas
sim_dats <- data.frame(replicate = exp_rep, timestamps = rfid_ts)

# Usa el tidyverse para añadir el año como la tercera columna
sim_dats <- sim_dats %>% 
  dplyr::mutate(
    year = rep(2023, length(rfid_ts))
  )

glimpse(sim_dats)

```

Acabas de añadir una columna para el año con el nombre correcto en menos líneas de código. En la notación del `tidyverse`, el símbolo de `%>%` significa una operación de `pipe`, en que usas el objeto antes del símbolo de `%>%` como entrada para la función que sigue el símbolo de `%>%`. Arriba usaste el objeto de `sim_dats` como entrada para la función `mutate()`, que usaste para crear la columna `year`.

La notación `dplyr::` antes de `mutate()` indica que la función `mutate()` se debería de acceder desde el paquete que se llama `dplyr`. Incluir el nombre del paquete con dos puntos repetidos dos veces es una notación importante que se debe usar cuando hay múltiples funciones accesibles en tu ambiente global con el mismo nombre. Por ejemplo, si usas otros paquetes aparte de `dplyr` que también tienen funciones que se llaman `mutate()`, y no especificas cual paquete quieres usar, puedes terminar con errores inmediatos (como cuando el código no se puede ejecutar). Incluso si el código ejecuta, usar la operación equivocada de otra función de `mutate()` puede introducir errores a tus análisis más adelante que son difíciles de identificar.

Las operaciones de `piping` con el símbolo `%>%` (o un `pipe`) pueden simplificar el código que escribes porque no creas tantos objetos intermedios como cuando usas R base. Por esta misma razón, puede tomar mucha práctica solucionar errores con operaciones de `piping` cuando estas operaciones son largas y anidadas. Una forma útil para revisar resultados intermedios dentro de operaciones largas de `piping` es incluir la función `glimpse()` entre diferentes pasos de la operación:
```{r}

# Crear el data frame otra vez con solo dos columnas
sim_dats <- data.frame(replicate = exp_rep, timestamps = rfid_ts)

# Usa el tidyverse para añadir el año como la tercera columna
sim_dats %>%
  glimpse() %>% # Ver la estructura de la primera versión de sim_dats
  dplyr::mutate(
    # La expresión nrow(.) significa "obtener el número de filas para el objeto actual". El objeto en este caso es sim_dats
    year = rep(2023, nrow(.))
  ) %>%
  glimpse() # Ver la estructura de la versión más reciente de sim_dats con la columna nueva de "year"

```

En el código anterior, también aprendiste una forma nueva para repetir un valor adentro de una operación de `piping` con la notación `.` adentro de una función, que significa que la operación ejecutará con el objeto actual. En el ejemplo arriba, `.` se refiere al objeto `sim_dats` que se usó como entrada para la operación entera de `piping`. Como el símbolo `.` está adentro de la función `nrow()`, la función debería de devolver el número de filas de `sim_dat`.

Puedes usar una operación parecida para añadir dos columnas al `dataframe` que contienen información del mes y día:
```{r}

# Usar el tidyverse para añadir el año como la tercera columna
sim_dats %>%
  glimpse() %>% # Ver la estructura de la versión original de sim_dats
  dplyr::mutate(
    year = 2023
  ) %>%
  glimpse() %>% # Ver la estructura de la versión intermedia de sim_dats con la nueva columna del año
  # También puedes añadir columnas para el mes ("month") y día ("day")
  dplyr::mutate(
    month = 08,
    day = 01
  ) %>% 
  glimpse() # Ver la estructura de la versión final de sim_dats con las columnas adicionales con el mes y el día

```

En el código anterior, añadiste dos columnas numéricas más al `dataframe` y lo hiciste sin necesitar usar la función `rep()` para repetir valores. Esto fue posible porque usaste un `dataframe` que ya existía como la entrada a las operaciones de `dplyr::mutate()`, y el único valor que especificaste para cada columna nueva del año, mes, y día se repitió automáticamente para llenar todas las filas en el `dataframe` para cada columna. Especificar un solo valor para una nueva columna puede ayudar a reducir la cantidad de código que escribes, pero sólo cuando de verdad quieres que el mismo valor se repita por todas las filas del `dataframe`.

Como no guardaste estas modificaciones a `sim_dats` en un objeto, el resultado del código arriba se va a imprimir en la consola. En el siguiente tutorial, vas a guardar este `dataframe` de datos simulados de RFID y sensores infrarrojo en hojas de cálculo como archivos físicos en tu computadora.

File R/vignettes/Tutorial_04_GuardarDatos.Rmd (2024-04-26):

---
title: "Tutorial 04: Guardar Datos"
author: "Grace Smith-Vidaurre"
date: "2023-12-27"
output: 
  html_document:
    css: "styles.css"
    toc: true
    toc_float: true
    toc_depth: 4
---

```{r setup, include = FALSE}

knitr::opts_chunk$set(echo = TRUE, eval = TRUE)

```

<h2>Información sobre esta traducción</h2>

Este tutorial fue traducido al español por Grace Smith-Vidaurre y editado por Tania Molina, siguiendo las [convenciones de traducción de los Carpentries](https://github.com/Carpentries-ES/board/blob/master/Convenciones_Traduccion.md), incluyendo usar el género femenino por defecto. Si encuentras errores de ortografía que impiden tu habilidad de completar los tutoriales, por favor reporta los errores de ortografía a GitHub usando los pasos en el primer tutorial para reportar un "Issue".

<h2>Resumen del tutorial y objetivos de aprendizaje</h2>

En este cuarto tutorial, vas a guardar hojas de cálculo de las detecciones simuladas de movimientos de animales en tu computadora. Vas a continuar usando habilidades que aprendiste en los tutoriales anteriores, y vas a aprender nuevas habilidades que incluyen:

1. Indexar y filtrar `dataframes`
2. Revisar la estructura de `dataframes` con R base y el `tidyverse`
3. Guardar objetos de R como archivos físicos en tu computadora
4. Leer archivos de tu computadora a R
5. Escribir y probar bucles

<h2>Cargar paquetes e inicializar el `path` de tu directorio de trabajo</h2>

```{r message = FALSE, warning = FALSE}

rm(list = ls()) # Limpia tu ambiente global

library(tidyverse) # Carga la colección de paquetes del tidyverse

path <- "/home/gsvidaurre/Desktop/ABISSMAL_vignettes" # Inicializa un objeto con el path de tu directorio de trabajo

```

<h3>Crear los datos simulados</h3>

En el código abajo, vas a recrear los datos simulados de RFID y sensores infrarrojo del tutorial anterior. Aquí estamos combinando el código en menos trozos comparado con el tercer tutorial:
```{r}

# Crea un vector de cuatro marcas de tiempo de RFID en formato HH:MM:SS
rfid_ts <- c("10:00:00", "10:05:00", "11:00:00", "11:05:00")

# Añade eventos de posar a los datos de RFID
rfid_ts <- c(rfid_ts, "08:00:00", "08:00:01", "08:00:02", "08:00:03", "11:30:00", "11:30:01", "11:30:02", "11:30:03", "11:30:04", "11:30:05")

glimpse(rfid_ts)

```

Aquí "IRBB" significa "infrared beam breakers" o sensores de infrarrojo.
```{r}

# Simula marcas de tiempo para los pares externos ("o_") e internos ("i_") de sensores infrarrojo para una entrada y una salida, y luego otra entrada y salida
o_irbb_ts <- c("09:59:59", "10:05:01", "10:59:59", "11:05:01")
i_irbb_ts <- c("10:00:01", "10:04:59", "11:00:01", "11:04:59")

# Simula unos errores de detección por la antena de RFID en las marcas de tiempo de cada par de sensores infrarrojo
# Estos errores de detección surgieron en cuatro movimientos adicionales: dos entradas y dos salidas
o_irbb_ts <- c(o_irbb_ts, "06:05:05", "06:35:08", "07:15:40", "11:10:25")
i_irbb_ts <- c(i_irbb_ts, "06:05:04", "06:35:09", "07:15:41", "11:10:24")

# Simula unas detecciones de ruido en las marcas de tiempo del par externo de sensores infrarrojo
o_irbb_ts <- c(o_irbb_ts, "09:45:01", "09:45:02", "09:45:03", "09:45:04", "09:45:05", "09:45:06", "09:45:07", "09:45:08", "09:45:09", "09:45:10", "09:45:11")

glimpse(o_irbb_ts)
glimpse(i_irbb_ts)

```

<h3>Simula tres días de colección de datos de RFID</h3>

En el código siguiente, vas a combinar el vector de marcas de tiempo de RFID que inicializaste arriba con metadatos en un `dataframe`. Estos metadatos van a incluir el año, el mes, y el día, y también una columna con los valores de dos etiquetas PIT (una etiqueta por individuo simulado), y una columna con información sobre el tipo de sensor. Deberías de reconocer partes de este código del tutorial anterior:
```{r}

# Crea un vector para la réplica experimental
exp_rep <- rep(x = "Nest_01", times = length(rfid_ts))

# Crea un vector de las identidades de las etiquetas PIT
# Asigna las primeras cuatro detecciones de RFID al primer individuo, el primer evento de posar (cuatro detecciones) al primer individuo, y el segundo evento de posar (seis detecciones) al segundo individuo
# Estas tres expresiones de rep() están combinadas en un solo vector usando la función c()
PIT_tag <- c(rep("1357aabbcc", 4), rep("1357aabbcc", 4), rep("2468zzyyxx", 6))

# Crea el dataframe con los metadatos de réplica experimental y las marcas de tiempo
sim_dats_rfid <- data.frame(chamber_id = exp_rep, timestamps = rfid_ts)

# Sobrescribe el dataframe con la versión modificada que tiene columnas para el año, el mes, y el día
sim_dats_rfid <- sim_dats_rfid %>%
  dplyr::mutate(
    year = 2023
  ) %>%
  dplyr::mutate(
    month = 08,
    day = 01
  ) %>%
  # Añade los metadatos de las etiquetas PIT en una columna nueva
  dplyr::mutate(
    PIT_tag = PIT_tag
  ) %>% 
  dplyr::mutate(
    sensor_id = "RFID"
  )

glimpse(sim_dats_rfid)

```

Ahora puedes usar este `dataframe` para simular el proceso de colección de datos a través de dos días más. Para crear observaciones (filas) de dos días adicionales, puedes adjuntar las filas de una copia modificada de `sim_dats_rfid` al objeto original de `sim_dats_rfid`.

En el código siguiente, estás usando una operación `pipe` para usar `sim_dats_rfid` como entrada en `bind_rows()`, y con esta notación estás especificando que `sim_dats_rfid` es el objeto original al cual quieres adjuntar más filas. Luego el código dentro de `bind_rows()` especifica el `dataframe`, o las filas nuevas que quieres adjuntar a `sim_dats_rfid`. En este caso, el código adentro de `bind_rows()` asigna `sim_dats_rfid` a `dplyr::mutate()` para modificar la columna de `day` y representar un día adicional de colección de datos. Luego repites este proceso para añadir un tercer día de recolectar datos simulados:
```{r}

sim_dats_rfid <- sim_dats_rfid %>% 
  bind_rows(
    sim_dats_rfid %>% 
      dplyr::mutate(
        day = 02
      )
  ) %>% 
  bind_rows(
    sim_dats_rfid %>% 
      dplyr::mutate(
        day = 03
      )
  )

glimpse(sim_dats_rfid) # Tres veces el número original de filas

```

<h3>Revisar columnas de `dataframe` con R base</h3>

Acabas de revisar la estructura del `dataframe` para confirmar que los datos simulados tienen datos recolectados a través de tres días. También puedes revisar los valores únicos que están presentes en la columna de `day`. Abajo puedes ver una forma de revisar los valores únicos adentro de una columna de un `dataframe`, usando dos ejemplos diferentes de notación de R base para acceder columnas adentro de un `dataframe`:
```{r}

# Escribir una expresión con el nombre de un objeto dataframe, un símbolo $, y el nombre de una columna te ayuda a acceder una columna a la vez en un dataframe. Una columna en un dataframe es un vector, por ende cuando ejecutas este código deberías de ver un vector de valores impreso en la consola
sim_dats_rfid$day

# Puedes también acceder una columna en un dataframe indexando, si escribes dos pares de corchetes (ambos pares de abrir y cerrar) después del nombre del dataframe, y colocas el nombre de la columna entrecomillas adentro del par interno de corchetes
sim_dats_rfid[["day"]]

# Puedes usar la función unique() para ver los valores únicos dentro de un vector, incluyendo una columna en un dataframe
unique(sim_dats_rfid$day) # Tres días, se ve bien

unique(sim_dats_rfid[["day"]]) # Tres días, se ve bien

```

<h3>Revisar columnas en un `dataframe` con el `tidyverse`</h3>

También puedes revisar valores únicos en una columna usando funciones del `tidyverse`. En la expresión de abajo, vas a usar una expresión de `pipe` para facilitar el `dataframe` `sim_dats_rfid` a la función `pull()`, que va a acceder la columna `day` del `dataframe` como un vector. Luego este vector de la columna `day` se va a usar como entrada a la función `unique()` para revisar los valores únicos del vector mismo. La función `unique()` no requiere un argumento adentro de los paréntesis porque ya recibió el valor de entrada que necesita a través de la operación de `piping`.
```{r}

# Tres días, se ve bien
sim_dats_rfid %>% 
  pull(day) %>% 
  unique()

```

<h3>Simula tres días de recolectar datos de los sensores infrarrojo</h3>

Ahora puedes repetir este proceso de crear un `dataframe` con metadatos para los datos de los sensores de infrarrojo. Dado que los sensores de infrarrojo no colectan información sobre la identidad única de individuos, vas a añadir columnas para el año, el mes, el día, y el tipo de sensor. También vas a simular la colección de datos para estos sensores a través de los mismos tres días que los datos simulados de RFID.
```{r}

# Sobrescribe el vector exp_rep con un vector nuevo que tenga el mismo largo que los vectores o_irbb_ts y i_irbb_ts juntos
exp_rep <- rep(x = "Nest_01", times = length(o_irbb_ts) + length(i_irbb_ts))

# Añade las marcas de tiempo de ambos pares de sensores infrarrojo a la misma columna usando c()
sim_dats_irbb <- data.frame(chamber_id = exp_rep, timestamps = c(o_irbb_ts, i_irbb_ts))

sim_dats_irbb <- sim_dats_irbb %>%
  dplyr::mutate(
    year = 2023,
    month = 08,
    day = 01,
    # Añade un identificador único para cada par de sensores
    # Cada etiqueta única se repetirá por el tamaño del vector de marcas de tiempo de cada par de sensores infrarrojo
    sensor_id = c(rep("Outer Beam Breakers", length(o_irbb_ts)), rep("Inner Beam Breakers", length(i_irbb_ts)))
  )

glimpse(sim_dats_irbb)

sim_dats_irbb <- sim_dats_irbb %>% 
  bind_rows(
    sim_dats_irbb %>% 
      dplyr::mutate(
        day = 02
      )
  ) %>% 
  bind_rows(
    sim_dats_irbb %>% 
      dplyr::mutate(
        day = 03
      )
  )

glimpse(sim_dats_irbb) # Tres veces el número de filas

# Tres días, se ve bien
sim_dats_irbb %>% 
  pull(day) %>% 
  unique()

```

<h2>Guarda un `dataframe` como un archivo físico</h2>

Los `dataframes` que creas y manipulas en R se pueden guardar como archivos físicos en tu directorio de trabajo. Tienes muchas opciones diferentes para guardar `dataframes`, pero recomiendo que uses formato `.csv` porque este formato es compatible con R, Microsoft Word, y otros programas. Puedes usar la función `write.csv()` para guardar `dataframes` a hojas de cálculo `.csv` en tu computadora:
```{r eval = FALSE}

?write.csv

```

Para escribir un archivo físico en tu directorio de trabajo, necesitas comunicarle a R 1) donde guardar el archivo y 2) el nombre del archivo que quieres crear. Puedes pasarle ambas piezas de información a `write.csv()` con combinar tu directorio de trabajo y el nombre del archivo usando la función `file.path()`. Para este ejemplo, vas a crear un archivo de prueba mientras practicas cómo usar `write.csv()`:
```{r}

# Combina el path (camino o ubicación) a tu directorio de trabajo con el nombre del archivo que quieres escribir
# La función file.path() combinará ambas piezas de información en un solo path para este archivo
rfid_file <- file.path(path, "test_file.csv")

# Este objeto contiene la ubicación dónde vas a guardar el archivo, y luego el nombre del archivo
rfid_file

```

Luego puedes proveer el `dataframe` a `write.csv()` usando un `pipe` y puedes especificar información adicional para crear el archivo `.csv`, como si quisieras añadir una columna adicional de identidades numéricas de las filas:
```{r eval = FALSE}

sim_dats_rfid %>%
  # Escribe el dataframe como una hoja de cálculo en formato .csv. No incluyes los nombres de las filas (row.names = FALSE)
  # El símbolo "." abajo significa que la función write.csv() va a operar sobre el objeto que proporcionó el pipe, que en este caso es el objeto sim_dats_rfid
  write.csv(x = ., file = rfid_file, row.names = FALSE)

```

Como se especifica en la documentación para la función `write.csv()`, esta función va a incluir las nombres de las columnas en la hoja de cálculo por defecto. La función no va a adjuntar esta información del `dataframe` en el archivo de `.csv` si esta hoja de cálculo ya existe, o sea, si ya creaste el archivo de `.csv` y vuelves a correr el código arriba, el archivo se va a sobrescribir por defecto.

Puedes revisar que `write.csv()` funcionó como esperabas con usar `list.files()` para ver los archivos en tu directorio de trabajo.
```{r eval = FALSE}

# Ve una lista de todos los archivos en este path
list.files(path)

```

También puedes usar `list.files()` para customizar una búsqueda con el argumento `pattern` (patrón). Usar el argumento `pattern` es parecido a buscar una palabra específica adentro de un documento de texto. El símbolo de "$" después de ".csv" significa que la función debería de buscar todos los archivos que *terminan* en el patrón ".csv".
```{r eval = FALSE}

# Devuelve sólo archivos que terminan en el patrón ".csv" en este path particular
list.files(path, pattern = ".csv$")

```

<h3>Leer una hoja de cálculo</h3>

Ahora puedes leer uno de estos archivos con R usando la función `read.csv()`. En el código abajo, vas a proveer el resultado de `read.csv()` a la función `glimpse()` para revisar la estructura del `dataframe` cuando leíste el archivo. El resultado de este código se imprime a la consola porque no está guardado adentro de un objeto.
```{r eval = FALSE}

read.csv(file.path(path, "test_file.csv")) %>% 
  glimpse()

```

Ahora que practicaste usar `write.csv()` y `read.csv()`, puedes eliminar el archivo temporal que creaste proveyendo el objeto `rfid_file` a la función `file.remove()`.
```{r eval = FALSE}

rfid_file <- file.path(path, "test_file.csv")
rfid_file

file.remove(rfid_file)

```

<h2>Guardar datos simulados para análisis con ABISSMAL</h2>

En el código de abajo, vas a trabajar con una serie de pasos para guardar los datos simulados en el formato y en las ubicaciones esperadas por las funciones de ABISSMAL. Para poder usar estas funciones de ABISSMAL, los datos simulados originales se tienen que guardar en una hoja de cálculo diferente por el tipo de sensor y el día de colección de datos. Estas hojas de cálculo se tienen que guardar adentro de una carpeta por tipo de sensor. ABISSMAL guarda los datos originales de esta misma forma cuando el sistema se usa para colectar datos empíricos de animales.

<h3>Filtrar un `dataframe`</h3>

Vas a practicar cómo usar la función `dplyr::filter()` para filtrar filas de un `dataframe` por día y luego guardar un `dataframe` filtrado con `write.csv()`. Para filtrar un `dataframe`, puedes usar una frase condicional adentro de la función `dplyr::filter()`:
```{r}

# Provee el dataframe a la función filter() con un "pipe"
sim_dats_rfid %>% 
  # Filtra el dataframe con seleccionar todas las filas en que la columna de día era igual a uno (el primer día de colección de datos)
  dplyr::filter(day == 1) %>%
  glimpse()

# Revisa que este paso de filtrar se hizo correctamente. El único valor dentro de la columna del día debería de ser 1
sim_dats_rfid %>% 
  dplyr::filter(day == 1) %>%
  pull(day) %>% 
  unique()

```

Puedes obtener resultados similares cuando inviertes la frase condicional dentro de `dplyr::filter()` para eliminar los días que **no** fueron ni el segundo día ni el tercer día de colección de datos. Abajo combinaste dos frases condicionales usando el símbolo de "&".
```{r}

sim_dats_rfid %>%
  # Filtra el dataframe seleccionando todas las filas en que los valores en la columna de día no son iguales a 2 o 3
  dplyr::filter(day != 2 & day != 3) %>%
  glimpse()

# Usa la función par ver los valores únicos en una columna para verificar que el proceso de filtrar se completo bien
sim_dats_rfid %>% 
  dplyr::filter(day != 2 & day != 3) %>%
  pull(day) %>% 
  unique()

```

Ahora que practicaste filtrar un `dataframe`, puedes combinar este paso de filtrar con escribir un archivo `.csv` que contiene el `dataframe` filtrado por los datos colectados en un solo día:
```{r eval = FALSE}

# Crea un directorio nuevo adentro de tu directorio de trabajo para guardar datos
file.path(path, "Data") # Revisa el path nuevo
dir.create(file.path(path, "Data")) # Crea el path nuevo

# Crea un directorio nuevo adentro del directorio de Data para los datos originales de RFID
file.path(path, "RFID") # Revisa el path nuevo
dir.create(file.path(path, "Data", "RFID")) # Crea el path nuevo

# Inicializa el nombre del archivo nuevo con el path de tu directorio de trabajo 
# Asegúrate de especificar que el archivo se va a guardar adentro de la carpeta nueva "RFID"
rfid_file <- file.path(path, "Data/RFID", "test.csv")
rfid_file

# Filtra los datos simulados de RFID para sacar el primer día de colección de datos
sim_dats_rfid %>% 
  dplyr::filter(day == 1) %>% 
  # Escribe el dataframe filtrado como una hoja de cálculo en formato .csv. No incluyas los nombres para las filas
  # Recuerda que el símbolo "." significa que la función va a usar el objeto que proveyó la operación de "pipe", que aquí es el dataframe filtrado para seleccionar solo el primer día de colección de datos
  write.csv(x = ., file = rfid_file, row.names = FALSE)

```

Revisa que el archivo de prueba se creó correctamente dentro de la carpeta nueva de RFID, y luego puedes eliminar este archivo.
```{r eval = FALSE}

list.files(file.path(path, "Data/RFID"), pattern = ".csv$")

rfid_file <- file.path(path, "Data/RFID", "test.csv")
rfid_file

file.remove(rfid_file)

```

<h3>Practicar escribir un bucle (loop)</h3>

Puedes repetir el código de arriba seis veces (tres veces por sensor) para escribir un `dataframe` por cada día de colección de datos por sensor. Pero es mejor evitar repetir el mismo código varias veces, porque cuando escribes código de esta forma es más difícil mantener archivos organizados de código y también es más fácil introducir errores mientras procesas y analizas datos. Cuando necesitas ejecutar el mismo código varias veces, es mejor escribir un bucle o `loop`. Escribir bucles es una habilidad muy importante y vamos a construir un bucle paso por paso.

Vas a practicar cómo escribir un bucle con la función `lapply()`.
```{r}

?lapply

# Crea un vector de los archivos que quieres guardar
files <- c(file.path(path, "Data/RFID", "test1.csv"), file.path(path, "Data/RFID", "test2.csv"))

files
length(files)

```

Ahora puedes empezar a escribir la estructura de un bucle. En el código siguiente, el argumento `X` es el número de veces que se va a ejecutar el bucle. En este caso, `X` es un vector numérico de 1 por el largo del vector `files` y contiene los números uno y dos. Por ende, el bucle va a ejecutar dos veces, y cada valor consecutivo en `X` se va a usar en cada iteración correspondiente del bucle para escribir un archivo a la vez.

El argumento `FUN` es una función customizada que fue escrita usando la notación `function(x){}`. Todo el código adentro de las llaves curvas (abre y cierre) se ejecutará en cada iteración del bucle. El argumento `x` adentro de `funcion()` es la variable de iteración, o la variable que va a tomar un valor diferente del vector `X` en cada iteración.
```{r}

# En este bucle la variable de iteración x va a tomar cada valor del vector en el argumento X. Por ejemplo, en la primera iteración del bucle, x va a tomar el valor numérico de 1. En la segunda iteración del bucle, x va a tomar el valor numérico de 2. Para probar esta lógica puedes ejecutar el bucle siguiente, y ver el valor de x que se va a imprimir en cada iteración en la consola
lapply(X = 1:length(files), FUN = function(x){
  
  x
  
})

```

Como puedes ver, el resultado de este bucle es un `list` con dos elementos. Cada elemento del `list` está rodeado de dos pares de corchetes ([[1]] y [[2]]) y contiene un vector con un tamaño de 1 que contiene el valor de la variable de iteración (1 y 2, respectivamente).

La variable de iteración, o `x`, no existe como un objeto afuera de la función del bucle. Si imprimes `x` afuera del bucle, no se va a encontrar ese objeto. Si creaste un objeto `x` afuera del bucle, verás los contenidos de este objeto cuando imprimes `x`. O sea, escribir un bucle que usa `x` como la variable de iteración no afectará otras líneas de código que usan un objeto que se llama `x` afuera de la función, y viceversa.

La variable de iteración de una función puede ser otras letras del alfabeto como `i`, `j`, `y`, `z`, o una combinación de múltiples letras, números, guiones bajos, o puntos, siempre y cuando el nombre de la variable empiece con una letra.

Una propiedad útil de la variable de iteración es que puedes usarlo para indexar vectores, `dataframes`, u otros objetos que creaste afuera del bucle. Por ejemplo, puedes usar `x` e indexar con corchetes para imprimir el nombre de cada archivo que quieras crear:
```{r}

lapply(X = 1:length(files), FUN = function(x){
  
  files[x]
  
})

```

También puedes modificar el código adentro de la función customizada para guardar cada archivo si metes la expresión `files[x]` dentro de la función `write.csv()` y usas una operación de `piping` para usar un `dataframe` como entrada para `write.csv()`.
```{r eval = FALSE}

lapply(X = 1:length(files), FUN = function(x){
  
  # En cada iteración del bucle, vas a guardar el dataframe `files[x]` en una hoja de cálculo con el nombre de archivo de la iteración actual
  sim_dats_rfid %>%
    write.csv(file = files[x], row.names = FALSE)
  
})

```

Deberías de ver dos resultados `NULL` en la consola si el bucle se ejecuta correctamente. Cuando revises los contenidos de la carpeta anidada de RFID, vas a poder ver que ambos archivos de `.csv` de prueba se escribieron en esta ubicación:
```{r}

list.files(file.path(path, "Data/RFID"))

```

Acabas de escribir dos hojas de cálculo usando un bucle, pero escribiste el mismo `dataframe` a cada hoja de cálculo. Para poder escribir un `dataframe` diferente a cada hoja de cálculo, puedes añadir el paso de filtrar el `dataframe` que aprendiste arriba. En el código siguiente, también vas a crear otro objecto de vector que se llama `days` (días) y luego usarás la variable de iteración para filtrar `sim_dats_rfid` y escribir una hoja de cálculo por cada día en `days`.
```{r eval = FALSE}

days <- c(1, 2, 3)

lapply(X = 1:length(files), FUN = function(x){
  
  sim_dats_rfid %>%
    # Filtra el dataframe una día a la vez
    dplyr::filter(day == days[x]) %>%
    # Escribe el dataframe filtrado por el día actual a una hoja de cálculo para ese día 
    write.csv(file = files[x], row.names = FALSE)
  
})

```

Puedes borrar estos archivos que creaste de prueba. En el código siguiente, vas a ver otro ejemplo de cómo buscar un patrón de texto mientras buscas evidencia de que los archivos de prueba se crearon (antes de borrarlos). La secuencia de caracteres que usas para el argumento `pattern` empieza con el símbolo de `^`, el cual significa que quieres buscar todos los archivos que *empiezan* con el patrón "test". También estás especificando que quieres devolver la ubicación (`path`) completa de cada archivo usando el argumento `full.names = TRUE`, para que la función `file.remove()` tenga toda la información que necesita para borrar estos archivos de prueba.
```{r eval = FALSE}

rem_files <- list.files(file.path(path, "Data/RFID"), pattern = "^test", full.names = TRUE)
rem_files

file.remove(rem_files)

```

<h3>Usa un bucle para guardar la hoja de cálculo de RFID</h3>

Ahora puedes juntar todo lo que aprendiste arriba y usar el bucle para escribir una hoja de cálculo por día para el sensor de RFID.
```{r eval = FALSE}

# Crea un vector de los nombres de los archivos que quieres guardar
files <- c(
  "RFID_simulated_Pair-01_2023_08_01.csv", 
  "RFID_simulated_Pair-01_2023_08_02.csv", 
  "RFID_simulated_Pair-01_2023_08_03.csv"
)

# Añade el path para la ubicación o carpeta al nombre de cada archivo
files <- file.path(path, "Data/RFID", files) 
files

# Inicializa un vector de los días para poder escribir una hoja de cálculo por día en cada iteración del bucle
days <- c(1, 2, 3)
days

# Puedes eliminar los nombres de los argumentos de lapply() porque estás especificando los valores de los argumentos en el orden que la función espera por defecto
invisible(lapply(1:length(files), function(x){
  
  sim_dats_rfid %>%
    # Filtra el dataframe por el día actual en esta iteración
    dplyr::filter(day == days[x]) %>%
    # Escribe el dataframe filtrado en la hoja de cálculo correcta para el día actual
    write.csv(file = files[x], row.names = FALSE)
  
}))

```

En el código de arriba, deberías de poder ver un cambio adicional que hicimos al bucle al rodearlo con la función `invisible()`. Esta función silencia el resultado que se imprime en la consola (que viste cuando ejecutaste trozos de código anteriores), donde el resultado de cada iteración de `lapply()` está rodeado de dos pares de corchetes, y luego un solo par de corchetes. `lapply()` es una función que devuelve un `list`, y cuando la función se ejecuta correctamente pero no hay resultados para imprimir (como cuando creas un archivo físico), la función debería de devolver valores de `NULL` que significan resultados vacíos. Este comportamiento se espera con nuestro uso de `lapply()` porque usamos la función para escribir archivos físicos y no para devolver resultados a la consola. Ya que puedes usar `list.files()` para revisar que `lapply()` se ejecutó bien, usar `invisible()` te ayudará a minimizar la cantidad de texto que tienes que revisar en tu consola.
```{r eval = FALSE}

# Los archivos nuevos de .csv para cada día de datos de RFID están presentes en el directorio esperado, muy bien
list.files(file.path(path, "Data/RFID"))

```

Ahora puedes eliminar los archivos que acabas de crear, porque vas a trabajar en escribir un bucle anidado que va a escribir automáticamente los datos de cada día para cada tipo de sensor.
```{r eval = FALSE}

files <- c("RFID_simulated_Pair-01_2023_08_01.csv", "RFID_simulated_Pair-01_2023_08_02.csv", "RFID_simulated_Pair-01_2023_08_03.csv")

# Añade el path para el directorio correcto a los nombres de los archivos que quieres borrar
files <- file.path(path, "Data/RFID", files) 
files

file.remove(files)

```

Si quieres más práctica escribiendo bucles, puedes escribir un bucle para guardar una hoja de cálculo para cada día de colección de datos de los sensores infrarrojo.

<h3>Escribe un bucle anidado para crear hojas de cálculo</h3>

Si quieres minimizar la cantidad de código que escribes para guardar los datos por tipo de sensor y por día, puedes guardar archivos de ambos tipos de sensores (RFID y sensores infrarrojo) en el mismo bucle. Para continuar, deberías de crear otro directorio para los datos de los sensores infrarrojo:
```{r eval = FALSE}

dir.create(file.path(path, "Data", "IRBB"))

```

Para lograr filtrar y escribir datos para ambos tipos de sensores a través de los días de colección de datos, vas a usar un tipo de objeto en R que se llama un `list`. Vas a usar estos `lists` adentro del bucle anidado:
```{r}

# Crea un list de los nombres de archivos customizados para guardar datos para cada tipo de sensor por día
files <- list(
  c("RFID_simulated_Pair-01_2023_08_01.csv", "RFID_simulated_Pair-01_2023_08_02.csv", "RFID_simulated_Pair-01_2023_08_03.csv"),
  c("IRBB_simulated_Pair-01_2023_08_01.csv", "IRBB_simulated_Pair-01_2023_08_02.csv", "IRBB_simulated_Pair-01_2023_08_03.csv")
)

glimpse(files)

```

Los `lists` son objetos útiles porque son muy flexibles. A diferencia de los vectores, una sola lista puede contener varios diferentes tipos de datos. A diferencia de un `dataframe`, los elementos de una lista no necesitan tener las mismas dimensiones. Los elementos de una lista también pueden ser diferentes tipos de objetos con estructuras diferentes. Por ejemplo, un solo `list` puede contener vectores, `dataframes`, y otros `lists`. El `list` que creaste arriba tiene dos elementos, y cada elemento es un vector de tres secuencias de caracteres que contienen los nombres de archivos que especificaste usando la función `c()`.

Puedes indexar un `list` de una forma parecida a indexar vectores y `dataframes`, pero usar un par o dos pares de corchetes devuelve resultados diferentes:
```{r}

# Usar un par de corchetes para filtrar un list devuelve el elemento actual en formato de list
files[1]
glimpse(files[1])

# Usar dos pares de corchetes devuelve solo el elemento actual, o sea, elimina la estructura de list para demostrar la estructura original de ese elemento (aquí este elemento es un vector)
files[[1]]
glimpse(files[[1]])

```

Un `list` también puede tener nombres para sus elementos, y los elementos se pueden acceder por nombre:
```{r}

# Crea un list de los nombres de los archivos que quieres guardar
files <- list(
  `RFID` = c("RFID_simulated_Pair-01_2023_08_01.csv", "RFID_simulated_Pair-01_2023_08_02.csv", "RFID_simulated_Pair-01_2023_08_03.csv"),
  `IRBB` = c("IRBB_simulated_Pair-01_2023_08_01.csv", "IRBB_simulated_Pair-01_2023_08_02.csv", "IRBB_simulated_Pair-01_2023_08_03.csv")
)

glimpse(files)

```

Accede los elementos de este `list` por nombre:
```{r}

# Usar un par de corchetes devuelve el elemento "RFID" como una lista
files["RFID"]

# Usar el símbolo de dolar "$" o dos pares de corchetes devuelve el elemento "RFID" en su formato original
files$RFID

files[["RFID"]]

```

Los `lists` son tipos de objetos muy útiles para operaciones con bucles anidados. Por ejemplo, si quieres escribir una hoja de cálculo por tipo de sensor y por día, vas a necesitar 1) un bucle para iterar a través de los tipos de sensores y 2) un bucle para iterar a través de días de colección de datos para cada sensor. Puedes usar listas para crear estructuras anidadas de datos que puedes proveer a un bucle anidado, para asegurar que cada capa del bucle se ejecuta de la forma que esperas. Por ejemplo, el `list` que se llama `files` refleja el bucle anidado que necesitas, porque los archivos están ordenados primero por el tipo de sensor (cada elemento del `list`) y luego por día de colección de datos (cada elemento del vector adentro de cada elemento del `list`):
```{r}

# Crea un vector de los nombres de los sensores
sensors <- c("RFID", "IRBB")

sensors

# Inicializa un list nombrado con los nombres de los archivos que quieres escribir
files <- list(
  `RFID` = c("RFID_simulated_Pair-01_2023_08_01.csv", "RFID_simulated_Pair-01_2023_08_02.csv", "RFID_simulated_Pair-01_2023_08_03.csv"),
  `IRBB` = c("IRBB_simulated_Pair-01_2023_08_01.csv", "IRBB_simulated_Pair-01_2023_08_02.csv", "IRBB_simulated_Pair-01_2023_08_03.csv")
)

files

# Crea un list de los paths para los archivos de cada sensor. Usarás estos paths dentro de los bucles
file_dirs <- list(
  `RFID` = file.path(path, "Data/RFID"),
  `IRBB` = file.path(path, "Data/IRBB") 
)

file_dirs

# Crea un list de los días de colección de datos para cada tipo de sensor
# Esto puede ser un solo vector en vez de una lista porque quieres guardar el mismo número de días por sensor, pero un list es útil por si quieres cambiar los días mismos o el número de días que quieres guardar por sensor
days <- list(
  `RFID` = c(1, 2, 3),
  `IRBB` = c(1, 2, 3)
)

days

# Ahora necesitas crear un list de los dataframes que quieres usar para crear los archivos. Como ya sabes cómo filtrar dataframes por día, ese código puede ir adentro de los bucles para minimizar la cantidad de código que escribes. Aquí vas a especificar el dataframe que usarás en las operaciones de filtro para cada tipo de sensor
dats <- list(
  `RFID` = sim_dats_rfid,
  `IRBB` = sim_dats_irbb
)

glimpse(dats)

```

Cuando hayas establecido las estructuras de los datos para informar la operación del bucle, puedes escribir el bucle anidado mismo. Este bucle anidado es una estructura compleja, y por ende es útil probar el bucle con valores determinados de cada variable de iteración (`x` y `y` abajo).

Después de escribir este bucle pero antes de ejecutar la estructura completa del bucle, deberías de probar el código adentro de cada capa del bucle. Para lograr esto, puedes inicializar los valores de las variables de iteración y luego correr el código adentro de cada bucle (pero sin ejecutar el bucle entero). Esta forma de revisar el bucle es equivalente a congelar el bucle en el tiempo, para que puedas ver el resultado del código para una sola iteración (abajo vas a ver la primera iteración para cada capa del bucle cuando ambos `x` y `y` tiene el valor numérico de uno).

Para lograr este tipo de chequeo, deberías de ejecutar el código para "congelar" las variables de iteración en la primera iteración de cada bucle ( o sea, inicializar `x` y `y` con el valor de uno). Luego deberías de ejecutar el código dentro de cada bucle, empezando con la creación de `days_tmp`, luego las operaciones de indexar y filtrar el `dataframe`, y luego filtrar los nombres de los archivos. No deberías de ejecutar las líneas con `lapply()` porque quieres evitar ejecutar los bucles completos hasta que estés segura que el código adentro de cada bucle funciona de la forma que esperas.

*Nota importante*: Arriba aprendiste que las variables de iteración no existen afuera de un bucle. Esta forma de probar el código adentro del bucle, en que no estás ejecutando los bucles mismos, es equivalente a probar el código afuera del bucle y por ende, los valores de las variables de iteración que inicialices afuera del bucle se van a respetar.

Si observas el código dentro de cada bucle, deberías de ver que entre el bucle exterior y el bucle interior, vas a usar el nombre del sensor para la primera iteración del bucle exterior ("RFID") para determinar los días para las iteraciones del bucle interior (en `days_tmp`). Adentro del bucle interior, vas a filtrar el `list` de `dataframes` por sensor, y luego por los días que quieres por sensor. Luego vas a indexar el nombre del archivo para el tipo de sensor actual y el día actual con una combinación de indexar la lista de nombres de los archivos con uno o dos pares de corchetes. Abajo, las líneas que abren y cierran los bucles mismos están comentados para guiar tu chequeo (o sea para guiar cuales líneas de código deberías de ejecutar):
```{r eval = FALSE}

# Congela las variables de iteración para el chequeo
x <- 1
y <- 1

# El bucle exterior: empieza con iterar a través de los sensores
# invisible(lapply(1:length(sensores), function(x){
  
  # Para obtener los días correctos para el tipo de sensor actual, deberías de indexar el list nombrado de días
  # Este paso de indexar es importante para que el bucle interior ejecute correctamente
  sensors[x] # Una secuencia de caracteres con el nombre del sensor
  
  # Coloca la secuencia de caracteres con el nombre del sensor adentro de dos pares de corchetes para extraer el vector de días para el tipo de sensor actual
  days_tmp <- days[[sensors[x]]]
  
  days_tmp
  
  # El bucle interior: itera a través de días para cada tipo de sensor
  # lapply(1:length(days_tmp), function(y){
    
    # Para obtener el dataframe del tipo de sensor actual, puedes usar "x" adentro de dos pares de corchetes para extraer el dataframe del list
    dats[[x]] %>%
      # Para filtrar el dataframe por el día actual puedes usar "y" para indexar el vector temporal de días (para extraer un solo elemento de este vector)
      dplyr::filter(day == days_tmp[y]) %>% 
      glimpse()
    
    # Usa dos pares de corchetes para acceder el vector de los nombres de los archivos para el tipo de sensor actual que está adentro de la lista. Luego usa la variable "y" para indexar este vector con un par de corchetes para acceder el nombre de archivo correcto para esta iteración
    files[[x]]
    
    files[[x]][y]
    
    # También vas a combinar el nombre del archivo con el path correcto:
    file.path(file_dirs[[x]], files[[x]][y])
    
  # })
  
# }))

```

Ahora deberías de tener una mejor idea sobre cómo cada bucle opera a través de diferentes estructuras de datos para realizar la tarea que quieres (en este caso, escribir una hoja de cálculo por tipo de sensor y por día). Más adelante puedes modificar la estructura entera de los bucles para reemplazar las líneas que escribiste y realizar el chequeo con las operaciones finales que quieres realizar:
```{r eval = FALSE}

# El bucle exterior: empieza con iterar a través de los sensores
invisible(lapply(1:length(sensors), function(x){
  
  # Para obtener los días correctos para el tipo de sensor actual, deberías de indexar el list nombrado de días
  # Este paso de indexar es importante para que el bucle interior se ejecute correctamente
  days_tmp <- days[[sensors[x]]]
  
  # El bucle interior: itera a través de días para cada tipo de sensor para escribir una hoja de cálculo por tipo de sensor y día
  lapply(1:length(days_tmp), function(y){
    
    # Usa la variable "x" para acceder el dataframe para el tipo de sensor actual y luego usa la variable "y" para filtrar este dataframe por el día actual
    dats[[x]] %>%
      # Filtra el dataframe por el día actual
      dplyr::filter(day == days_tmp[y]) %>%
      # Usa una operación de indexar con doble corchetes para especificar el path correcto por tipo de sensor
      # Luego usa operaciones de filtrar con doble corchetes y un par de corchetes para acceder el nombre correcto del archivo para el tipo de sensor y el día actual
      write.csv(file = file.path(file_dirs[[x]], files[[x]][y]), row.names = FALSE)
    
  })
  
}))

```

Esta estructura de bucle debería de haber creado un archivo por tipo de sensor y día en el directorio correcto por tipo de sensor. Puedes revisar que estos seis archivos existen adentro del directorio para cada tipo de sensor en tu directorio de trabajo:
```{r eval = FALSE}

list.files(file.path(path, "Data/RFID"))

list.files(file.path(path, "Data/IRBB"))

```

En este tutorial aprendiste más sobre cómo filtrar `dataframes` y guardar estos objetos como hojas de cálculo, y cómo usar bucles (loops) de una capa y estructuras de bucles anidados. En el siguiente tutorial vas a usar las hojas de cálculo de los datos simulados de RFID y sensores infrarrojo que creaste para empezar a procesar y analizar datos con las funciones de ABISSMAL.

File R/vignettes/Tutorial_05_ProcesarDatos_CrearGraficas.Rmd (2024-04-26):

---
title: "Tutorial 05: Procesar Datos y Crear Gráficas"
author: "Grace Smith-Vidaurre"
date: "2023-12-27"
output: 
  html_document:
    css: "styles.css"
    toc: true
    toc_float: true
    toc_depth: 4
---

```{r setup, include = FALSE}

knitr::opts_chunk$set(echo = TRUE, eval = TRUE)

```

<h2>Información sobre esta traducción</h2>

Este tutorial fue traducido al español por Grace Smith-Vidaurre y editado por Tania Molina, siguiendo las [convenciones de traducción de los Carpentries](https://github.com/Carpentries-ES/board/blob/master/Convenciones_Traduccion.md), incluyendo usar el género femenino por defecto. Si encuentras errores de ortografía que impiden tu habilidad de completar los tutoriales, por favor reporta los errores de ortografía a GitHub usando los pasos en el primer tutorial para reportar un "Issue".

<h2>Resumen del tutorial y objetivos de aprendizaje</h2>

En este quinto tutorial, vas a empezar a usar las detecciones simuladas de movimientos de animales en el `pipeline` de análisis de datos de ABISSMAL, incluyendo combinar los datos originales a través de días y procesar o limpiar los datos originales. También vas a crear gráficas de los datos procesados. Vas a continuar usando habilidades que aprendiste en los tutoriales anteriores, y vas a aprender nuevas habilidades cómo:

1. Acceder funciones customizadas
2. Usar funciones customizadas
3. Crear gráficas con `ggplot` 

<h2>Cargar paquetes e inicializar el `path` de tu directorio de trabajo</h2>

```{r message = FALSE, warning = FALSE}

rm(list = ls()) # Limpia tu ambiente global

library(tidyverse) # Carga la colección de paquetes del tidyverse
library(data.table) # Carga otros paquetes requeridos por las funciones de ABISSMAL

path <- "/home/gsvidaurre/Desktop/ABISSMAL_vignettes" # Inicializa un objeto con el path de tu directorio de trabajo

```

<h2>Cargar las funciones de ABISSMAL</h2>

Las funciones customizadas de R en ABISSMAL están guardadas en archivos físicos (extensión .R) adentro de la versión local del repositorio en tu computadora (que descargaste en el primer tutorial). Para poder usar las funciones de ABISSMAL, vas a necesitar cargar los archivos físicos de R para que las funciones estén disponibles en tu ambiente global. En el código de abajo, vas a usar la función `source()` para cargar tres de las cinco funciones primarias de ABISSMAL, y también un archivo que contiene funciones de apoyo:
```{r}

# Carga la función que combina los datos originales
source("/home/gsvidaurre/Desktop/GitHub_repos/ABISSMAL/R/combine_raw_data.R")

# Carga la función que detecta eventos de pose en los datos originales
source("/home/gsvidaurre/Desktop/GitHub_repos/ABISSMAL/R/detect_perching_events.R")

# Carga la función que procesa los datos originales
source("/home/gsvidaurre/Desktop/GitHub_repos/ABISSMAL/R/preprocess_detections.R")

# Carga un archivo con funciones de apoyo que cada función anterior que requiera
source("/home/gsvidaurre/Desktop/GitHub_repos/ABISSMAL/R/utilities.R")

```

<h2>Accede información sobre las funciones de ABISSMAL</h2>

Después de ejecutar las líneas de código anteriores, deberías de ver que una colección entera de funciones ahora está disponible en tu ambiente global (revisa la pestaña de `Environment`). Las funciones que empiezan con `check_` son funciones de apoyo. Si haces scroll hacia abajo, puedes ver que tres de las funciones primarias de ABISSMAL (`combine_raw_data`, `detect_perching_events`, `preprocess_detections`) también están disponibles en tu ambiente global. En la columna al lado derecho de los nombres de las funciones también podrás ver algo de información sobre los argumentos de cada función.

Para obtener más información sobre cada una de las tres funciones primarias, puedes hacer clic en el ícono blanco cuadrado a la mera derecha de cada función en la pestaña de `Environment`, o ejecutar el código `View(nombre_de_la_funcion)`. Este comando debería de abrir el archivo de la función actual en una pestaña nueva adentro de tu panel de fuente. En el archivo de cada función, vas ver líneas de documentación que empiezan con los símbolos "`#@", luego el nombre de la función y una descripción, y luego una descripción de cada argumento (parámetro) para la función. Si haces scroll hacia abajo, podrás ver una sección con detalles sobre la función misma, incluyendo la información que devuelve. Esta documentación está escrita solo en inglés por el momento. Después de las líneas de documentación verás el código de la función misma.

<h2>Combinar los datos originales</h2>

Cuando hayas cargado las funciones de ABISSMAL, podrás usar la primera función, `combine_raw_data()`, para combinar los datos colectados a través de días y los tipos de sensores en una sola hoja de cálculo por sensor. Vas a empezar con combinar los datos originales para el sensor de RFID que fueron colectados a través de días diferentes en una hoja de cálculo para este sensor.

Vas a proveerle información a la función `combine_raw_data()` a través de los siguientes argumentos:

* `sensors` es un vector que contiene las etiquetas de los tipos de sensores para los cuales quieres combinar los datos originales. Abajo vas a especificar RFID como un solo sensor

* `path` es tu directorio general de trabajo

* `data_dir` es la carpeta que contiene archivos dentro de tu directorio de trabajo

* `out_dir` es la carpeta donde quieres guardar la hoja de cálculo de los datos originales combinados. La función creará esta carpeta si no existe en tu computadora

* `tz` es la zona de tiempo para convertir marcas de tiempo al formato `POSIXct` en R. La zona de tiempo por defecto es "America/New York", y puedes ver la sección de "Time zones" en la documentación para `DateTimeClasses` en R para más información (`?DateTimeClasses`)

* `POSIXct_format` es una secuencia de caracteres que contiene la información del formato `POSIXct` para combinar fechas y marcas de tiempo en una sola columna. Por defecto la función devolverá el año como un número con cuatro dígitos y el mes y el día como números con dos dígitos, separados por guiones. La fecha y el tiempo estarán separados por un espacio. La hora, el minuto, y el segundo (en decimales), todos con dos dígitos, estarán separados por dos puntos.
```{r}

# Combina los datos originales para los sensores de RFID e infrarrojo en procesos separados
combine_raw_data(sensors = "RFID", path = path, data_dir = "Data", out_dir = "Data/raw_combined", tz = "America/New York", POSIXct_format = "%Y-%m-%d %H:%M:%OS")

```

Puedes revisar que `combine_raw_data()` guardó una hoja de cálculo con los datos originales combinados de RFID al directorio nuevo `raw_combined`:
```{r}

list.files(file.path(path, "Data/raw_combined"), pattern = ".csv$")

```

Puedes proveer el archivo de datos combinados de RFID ("combined_raw_data_RFID.csv") a R para revisar la estructura de esta hoja de cálculo:
```{r}

rfid_data <- read.csv(file.path(path, "Data/raw_combined", "combined_raw_data_RFID.csv"))

glimpse(rfid_data)

```

R lee esos datos y crea un objeto `dataframe`. Deberías de poder ver que hay columnas nuevas creadas por la función, como la columna `data_type`. Para esta hoja de cálculo, las columnas `sensor_id` y `data_type` contienen la misma información, pero es útil tener columnas separadas para poder estar al tanto de la identidad única del sensor y el tipo de sensor cuando usas múltiples sensores del mismo tipo (por ejemplo, dos pares de sensores infrarrojo tendrán números de identidad únicos en la columna de `sensor_id`).

La función `combine_raw_data()` también crea una columna nueva de marcas de tiempo en formato `POSIXct` para los siguientes pasos de procesar y analizar datos, pero a la vez mantiene la columna original de marcas de tiempo. Por consiguiente, la función añadió columnas para indicar la etapa de procesar datos y la fecha en que combinaste los datos originales. Finalmente, si revisas las carpetas con los datos originales de RFID, verás que las hojas de cálculo originales por día se preservaron y no fueron ni eliminados ni sobrescritos.

También puedes ejecutar `combine_raw_data()` con los datos originales de múltiples sensores a la vez proveyendo un vector con las etiquetas de estos sensores al argumento `sensores`. Los datos para cada tipo de sensor se guardarán en hojas de cálculo separadas, y así evitas tener que escribir el mismo código varias veces para ejecutar `combine_raw_data()` para múltiples sensores:
```{r}

combine_raw_data(sensors = c("RFID", "IRBB"), path = path, data_dir = "Data", out_dir = "Data/raw_combined", tz = "America/New York", POSIXct_format = "%Y-%m-%d %H:%M:%OS")

```

Los datos de RFID se sobrescribirán, y deberías de ver una hoja de cálculo adicional con los datos originales de los sensores infrarrojo:
```{r}

list.files(file.path(path, "Data/raw_combined"), pattern = ".csv$")

```

<h2>Detectar eventos de pose</h2>

Puedes usar los datos originales combinados de sensores diferentes en las siguientes funciones de ABISSMAL para empezar a hacer inferencias de comportamiento de los datos de detección de movimiento. Por ejemplo, puedes detectar eventos de pose en los datos originales de RFID con la función `detect_perching_events()`. Puedes leer más sobre cada argumento en el archivo de R que contiene esta función.
```{r}

detect_perching_events(file_nm = "combined_raw_data_RFID.csv", threshold = 2, run_length = 2, sensor_id_col_nm = "sensor_id", timestamps_col_nm = "timestamp_ms", PIT_tag_col_nm = "PIT_tag", rfid_label = "RFID", general_metadata_cols = c("chamber_id", "sensor_id"), path = file.path(path, "Data"), data_dir = "raw_combined", out_dir = "processed", out_file_prefix = "perching_events", tz = "America/New York", POSIXct_format = "%Y-%m-%d %H:%M:%OS")

```

`detect_perching_events()` puede operar en sólo un archivo y tipo de sensor a la vez. La función automáticamente crea una carpeta que se llama "processed" (para datos procesados) y guardará un archivo de `.csv` dentro de esa carpeta si efectivamente pudo detectar eventos de pose usando el umbral temporal actual (`threshold`, en segundos), y la duración de secuencias de detección actual (`run_length`, en número de detecciones).

Cuando creamos datos simulados en los últimos tutoriales, simulaste eventos de pose en los datos de RFID. Pudiste recuperar estos eventos de pose usando `detect_perching_events()`?
```{r}

perching <- read.csv(file.path(path, "Data", "processed", "perching_events_RFID.csv"))

glimpse(perching)

```

`detect_perching_events()` identificó un total de seis eventos de pose, que es el mismo número que simulaste en el tutorial anterior (dos eventos de pose por día a través de tres días). Puedes revisar los valores dentro del `dataframe` para ver más información sobre estos eventos de pose:
```{r}

# Las marcas de tiempo cuando cada pose empezó
perching$perching_start

# Las marcas de tiempo cuando cada pose terminó
perching$perching_end

# La etiqueta única de PIT que contiene información sobre la identidad del individuo que estuvo posando en la antena de RFID
perching$PIT_tag

```

También puedes visualizar el `dataframe` entero en un panel separado:
```{r eval = FALSE}

View(perching)

```

La información de arriba te dice que hubo dos eventos de pose a las 8:00 cada día, y dos eventos de pose a las 11:30 cada día (como esperábamos). La etiqueta de PIT para cada individuo se detectó una vez por día, por ende, cada individuo realizó un evento de pose cada día.

Detectar eventos de pose no es un requisito en el `pipeline` de análisis de ABISSMAl, pero puede ser un paso útil para obtener la mayor cantidad de información que puedes de los datos originales antes de filtrar las detecciones en el siguiente paso de procesar o limpiar los datos originales.

<h2>Procesar los datos originales</h2>

Cuando hayas detectado los eventos de pose en los datos originales, puedes seguir con procesar o limpiar los datos originales con la función `preprocess_detections()`. Los datos originales a veces contienen múltiples detecciones separadas por poco tiempo (como las detecciones de RFID cuando un individuo está posando en la antena), y estas múltiples detecciones pueden causar ruido cuando tratas de hacer inferencias de comportamiento con datos colectados por múltiples sensores. Cuando le provees "thin" al argumento `mode`, `preprocess_detections()` elimina detecciones separadas por un periodo corto de tiempo (usando el valor del umbral temporal en segundos para el argumento `thin_threshold`), y devuelve datos filtrados de detecciones que todavía representan eventos discretos de movimiento.

`preprocess_detections()` opera en un solo tipo de sensor a la vez:
```{r}

preprocess_detections(sensor = "RFID", timestamps_col_nm = "timestamp_ms", group_col_nm = "PIT_tag", mode = "thin", thin_threshold = 2, drop_tag = NULL, path = file.path(path, "Data"), data_dir = "raw_combined", out_dir = "processed", tz = "America/New York", POSIXct_format = "%Y-%m-%d %H:%M:%OS")

```

Ahora deberías de ver un archivo de `.csv` adicional que se llama "pre_processed_data_RFID.csv" en la carpeta "processed":
```{r}

list.files(file.path(path, "Data/processed"))

```

Puedes darle este archivo a R para que lo lea y vea su estructura. Deberías de poder ver menos filas en este `dataframe` comparado con la hoja de cálculo de los datos originales:
```{r}

rfid_pp <- read.csv(file.path(path, "Data/processed/pre_processed_data_RFID.csv"))

glimpse(rfid_pp)

```

Luego puedes procesar los datos originales de los sensores infrarrojo y revisar el archivo de `.csv`:
```{r}

preprocess_detections(sensor = "IRBB", timestamps_col_nm = "timestamp_ms", group_col_nm = "sensor_id", mode = "thin", thin_threshold = 2, drop_tag = NULL, path = file.path(path, "Data"), data_dir = "raw_combined", out_dir = "processed", tz = "America/New York", POSIXct_format = "%Y-%m-%d %H:%M:%OS")

list.files(file.path(path, "Data/processed"))

irbb_pp <- read.csv(file.path(path, "Data/processed/pre_processed_data_IRBB.csv"))

glimpse(irbb_pp)

```

<h2>Visualizar datos de RFID en una gráfica de barras</h2>

Ahora que combinaste y procesaste los datos originales por sensor, es hora de visualizar estos conjuntos de datos diferentes. Hacer gráficas mientras escribes código es importante para generar figures de alta calidad para publicaciones y presentaciones y también para revisar tu proceso de analizar datos.

En el código de abajo, vas a aprender cómo usar funciones del paquete `ggplot2` para hacer una gráfica de barras con los datos originales y procesados de RFID.

Puedes empezar dándole a R los datos originales y procesados de RFID, los eventos de posar de RFID, y convertir las marcas de tiempo al formato `POSIX`.
```{r}

rfid_raw <- read.csv(file.path(path, "Data/raw_combined", "combined_raw_data_RFID.csv")) %>%
  # Tienes que convertir las marcas de tiempo al formato POSIX cada vez que los datos se leen a R para hacer gráficas
  dplyr::mutate(
    timestamp_ms = as.POSIXct(format(as.POSIXct(timestamp_ms, tz = "America/New York"), "%Y-%m-%d %H:%M:%OS6"))
  ) %>%
  # Ordena las marcas de tiempo
  # La expresión "-desc()" dentro de la función arrange() indica que las marcas de tiempo se ordenarán de menos a más recientes
  dplyr::arrange(-desc(timestamp_ms))

# Deberías de ver que la columna timestamp_ms con las marcas de tiempo está en el formato "dttm", significando que la conversión a formato POSIX se realizó correctamente
glimpse(rfid_raw)

rfid_pp <- read.csv(file.path(path, "Data/processed/pre_processed_data_RFID.csv")) %>%
  # Tienes que convertir las marcas de tiempo al formato POSIX cada vez que los datos se le dan a leer a R para hacer gráficas
  dplyr::mutate(
    timestamp_ms = as.POSIXct(format(as.POSIXct(timestamp_ms, tz = "America/New York"), "%Y-%m-%d %H:%M:%OS6"))
  ) %>% 
  dplyr::arrange(-desc(timestamp_ms))

glimpse(rfid_pp)

rfid_perch <- read.csv(file.path(path, "Data/processed/perching_events_RFID.csv")) %>%
  # Tienes que convertir las marcas de tiempo de inicio y final de cada evento de pose al formato POSIX cada vez que los datos se dan a R para hacer gráficas
  dplyr::mutate(
    perching_start = as.POSIXct(format(as.POSIXct(perching_start, tz = "America/New York"), "%Y-%m-%d %H:%M:%OS6")),
    perching_end = as.POSIXct(format(as.POSIXct(perching_end, tz = "America/New York"), "%Y-%m-%d %H:%M:%OS6"))
  ) %>% 
  dplyr::arrange(-desc(perching_start))

glimpse(rfid_perch)

```

Luego puedes combinar los datos originales y procesados en un solo `dataframe` para facilitar visualizar todos estos datos en la misma gráfica. Vas a añadir una columna nueva (`dataset`) con etiquetas para identificar los dos conjuntos de datos diferentes.
```{r}

rfid_combined <- rfid_raw %>%
  dplyr::select(sensor_id, day, timestamp_ms) %>% 
  dplyr::mutate(
    dataset = "raw"
  ) %>% 
  bind_rows(
    rfid_pp %>%
      dplyr::select(sensor_id, day, timestamp_ms) %>% 
      dplyr::mutate(
        dataset = "pre-processed"
      ) 
  ) %>%
  dplyr::arrange(-desc(timestamp_ms))

glimpse(rfid_combined)

```

Vas a construir la gráfica con estos datos usando funciones de `ggplot2`, un paquete que es parte del `tidyverse` pero que también se puede instalar y usar fuera del `tidyverse`. Puedes revisar este [enlace](https://ggplot2.tidyverse.org/) que tiene más recursos (en inglés) para aprender cómo usar la notación de `ggplot` para hacer diferentes tipos de gráficas. Estos recursos incluyen secciones de tres libros diferentes con ejercicios para practicar hacer gráficas sencillas o complejas, y también un curso en línea y un seminario en línea. Puedes encontrar otros recursos en español también, como esta [guia para `ggplot2`](https://raw.githubusercontent.com/rstudio/cheatsheets/main/translations/spanish/data-visualization_es.pdf).

El paquete de `ggplot2` tiene una notación única para construir gráficas, en la cual empiezas haciendo la gráfica llamando la función `ggplot()` y luego añades características añadiendo capas de otras funciones de `ggplot2` con el símbolo de `+`.

Si llamas `ggplot()`, verás que la función inmediatamente dibuja una gráfica vacía en tu panel de `Plots` (gráficas) en RStudio.
```{r}

ggplot()

```

La gráfica seguirá vacía incluso cuando le provees información sobre tus datos para poder configurar la estética en los siguientes pasos.
```{r}

ggplot(data = rfid_combined)

```

Necesitarás añadir otras funciones estéticas a esta capa fundamental de la gráfica para poder ver tus datos. Las funciones que usarás para añadir detalles estéticos a la gráfica vacía dependerán del tipo de gráfica que quieres crear. En este ejemplo, vas a generar una gráfica barras, en la cual cada marca de tiempo está representada por una línea vertical delgada. Las gráfica barras pueden ser gráficas útiles cuando trabajas con marcas de tiempo, porque la información más importante se contiene en una dimensión (el tiempo en el eje "x"). Si fueras a resumir el número de marcas de tiempo grabado cada día, sería mejor hacer una gráfica de líneas.

Puedes añadir la función `geom_segment()` como la siguiente capa encima de la capa fundamental de la gráfica. `geom_segment()` facilita añadir línea a una gráfica, y las líneas pueden comunicar información en una o dos dimensiones (por su ancho en el eje "x" y su altura en el eje "y").
```{r}

ggplot(data = rfid_combined) +
  
  # Añade una línea vertical para cada marca de tiempo
  geom_segment(
    aes(x = timestamp_ms, y = 0, xend = timestamp_ms, yend = 1, color = dataset),
    linewidth = 0.3
  )
  
```

En el código anterior, `geom_segment()` añade una línea vertical a la gráfica para cada detección en el `dataframe` completo. Usando el argumento `color` adentro de `geom_segment()`, y proveyendo el nombre de la columna que contiene las etiquetas de los conjuntos de datos, le comunicaste a la función que las líneas deberían de tener colores que corresponden al conjunto particular de datos. El argumento `color` tiene que estar adentro de la función `aes()` (que controla la estética de esta capa de información) para que esta asignación de colores se realice por el conjunto de datos.

Los colores de las líneas se asignarán automáticamente por `ggplot` usando los colores por defecto del paquete, pero puedes cambiar estos colores usando la función `scale_color_manual()`:
```{r}

ggplot(data = rfid_combined) +
  
  # Añade una línea vertical para cada marca de tiempo
  geom_segment(
    aes(x = timestamp_ms, y = 0, xend = timestamp_ms, yend = 1, color = dataset),
    linewidth = 0.3
  ) +
  
  scale_color_manual(values = c("orange", "darkgreen"))

```

Las líneas ahora tienen los colores nuevos que especificaste pero en la leyenda los datos procesados salen primero. Si quieres cambiar el orden de las etiquetas del conjunto de datos en la leyenda, y los colores asignados a los conjuntos de datos, puedes modificar la columna `dataset` en el `dataframe` que usaste para crear la gráfica.

Las funciones de `ggplot` usan un tipo de datos que se llaman `factors` para determinar automáticamente la estética de la gráfica, como el método de asignar colores que usaste arriba con `geom_segment()`. Las columnas (o vectores) en formato `factor` se ven como columnas de tipo `character` (en que cada fila contiene una secuencia de caracteres), pero R guarda los valores únicos de cada columna como números enteros y luego guarda los valores únicos de las secuencias de caracteres en una propiedad que se llama `levels` ("niveles" o "categorías"). Puedes cambiar el orden en que los valores únicos de una columna en formato `factor` se añaden a la gráfica cuando cambias el orden de los `levels` de la columna:
```{r}

# Cambia la columna dataset al tipo de datos "factor"
# Cuando especificas que el valor de "raw" ("original") vaya primero en el argumento de levels, estás reorganizando los niveles de la columna para que este valor salga primero en la leyenda
rfid_combined <- rfid_combined %>% 
  dplyr::mutate(
    dataset = factor(dataset, levels = c("raw", "pre-processed"))
  )

# La columna de dataset ahora es tipo "fct" o "factor"
glimpse(rfid_combined)

# Los niveles de la columna ahora están ordenados para que el valor "raw" vaya primero, en vez de estar en orden alfabético
levels(rfid_combined$dataset)

```

Después de convertir la columna de `dataset` al tipo `factor` y reorganizar los `levels` de los valores únicos en esta columna, las categorías de esta columna deberían de aparecer en el orden correcto en la leyenda de la gráfica y no en orden alfabético. También deberías de ver que los colores asignados a cada conjunto de datos acaba de cambiar.
```{r}

ggplot(data = rfid_combined) +
  
  # Añade una línea vertical para cada marca de tiempo
  geom_segment(
    aes(x = timestamp_ms, y = 0, xend = timestamp_ms, yend = 1, color = dataset),
    linewidth = 0.3
  ) +
  
  scale_color_manual(values = c("orange", "darkgreen"))

```

En la gráfica que acabas de hacer, puede resultar difícil distingüir entre las líneas para cada conjunto de datos. Puedes usar la función `facet_wrap()` para dividir los conjuntos de datos en paneles diferentes:
```{r}

ggplot(data = rfid_combined) +
  
  # Añade una línea vertical para cada marca de tiempo
  geom_segment(
    aes(x = timestamp_ms, y = 0, xend = timestamp_ms, yend = 1, color = dataset),
    linewidth = 0.3
  ) +
  
  scale_color_manual(values = c("orange", "darkgreen")) +
  
  # El símbolo de ~ significa "por", así que estás creando un panel por cada valor único (o categoría) en la columna dataset
  facet_wrap(~ dataset, nrow = 2, strip.position = "left")

```

Acabas de crear paneles diferentes dentro de esta gráfica y cada panel contiene información de un solo conjunto de datos. Con este cambio estructural también alineaste los paneles en el mismo eje "x" para que sea más fácil de comparar patrones temporales.

Hasta este punto es difícil ver cómo los dos conjuntos de datos (originales y procesados) son diferentes. Puedes filtrar el `dataframe` con funciones del `tidyverse` para visualizar solo las primeras dos detecciones para cada conjunto de datos:
```{r}

ggplot(data = rfid_combined %>%
         # Crea grupos para las categorías o levels en la columna dataset
         group_by(dataset) %>% 
         # Selecciona las primeras dos filas para cada grupo 
         slice(1:2) %>% 
         ungroup()
       ) +
  
  # Añade una línea vertical para cada marca de tiempo
  geom_segment(
    aes(x = timestamp_ms, y = 0, xend = timestamp_ms, yend = 1, color = dataset),
    linewidth = 0.3
  ) +
  
  scale_color_manual(values = c("orange", "darkgreen")) +
  
  # El símbolo de ~ significa "por", así que ahora estás creando un panel por cada valor único (o categoría) en la columna dataset
  facet_wrap(~ dataset, nrow = 2, strip.position = "left")

```

Ahora deberías de ver que la segunda marca de tiempo en los datos originales se eliminó del conjunto de datos procesados (fue filtrado usando el umbral temporal en `preprocess_detections`).

Luego puedes añadir los datos de eventos de pose en el `dataframe` `rfid_perch`, que no combinaste con los otros conjuntos de datos. A diferencia de `rfid_raw` y `rfid_pp`, este conjunto de datos tiene dos columnas de marcas de tiempo que contienen información sobre el inicio y el fin de cada evento de pose. Puedes añadir este conjunto de datos a la gráfica volviendo a llamar la función `geom_segment()`. Usarás esta capa de `geom_segment()` para añadir líneas que contienen información temporal sobre cuándo empezaron los eventos de pose y cuándo terminaron.
```{r}

ggplot(data = rfid_combined) +
  
  # Añade una línea vertical por cada marca de tiempo
  geom_segment(
    aes(x = timestamp_ms, y = 0, xend = timestamp_ms, yend = 1, color = dataset),
    linewidth = 0.3
  ) +
  
  scale_color_manual(values = c("orange", "darkgreen")) +
  
  # El símbolo de ~ significa "por", así que estás creando un panel por cada valor único (o categoría) en la columna dataset
  facet_wrap(~ dataset, nrow = 2, strip.position = "left") +
  
  # Añade los eventos de pose
  geom_segment(
    data = rfid_perch,
    aes(x = perching_start, xend = perching_end, y = 1.2, yend = 1.5),
    color = "blue",
    linewidth = 0.3
  )

```

En el código anterior con respecto a `geom_segment()`, especificaste que querías añadir otro conjunto de datos a la gráfica cuando usaste el argumento `data`. Los argumentos `x` y `y` determinan donde va a empezar cada línea en ambos ejes de la gráfica, respectivamente. También vas a tener que especificar donde quieres que cada línea termina en cada eje. En el eje x, indicaste que quieres que la línea empiece y termine cuando los eventos de pose empezaron y terminaron, proveyendo a la columna `perching_start` al argumento `x` y `perching_end` al argumento `xend`. En el eje "y", los números que usaste para los argumentos `y` y `yend` determinan donde las líneas para los eventos de pose se van a dibujar, que en este caso es justamente arriba de las líneas para los otros conjuntos de datos. Las líneas para los eventos de pose se dibujaron como otra capa de información encima de cada panel de la gráfica por defecto.

Puedes hacer unos cambios a la gráfica para que sea más fácil de interpretar. Puedes cambiar la posición de la leyenda usando el argumento `legend.position` adentro de la función general de `theme()`. Abajo puedes guardar la gráfica adentro de un objeto, para que no tengas que escribir otra vez  el código de la gráfica cada vez que quieres añadirle más información.
```{r}

gg <- ggplot(data = rfid_combined) +
  
  # Añade una línea vertical para cada marca de tiempo
  geom_segment(
    aes(x = timestamp_ms, y = 0, xend = timestamp_ms, yend = 1, color = dataset),
    linewidth = 0.3
  ) +
  
  scale_color_manual(values = c("orange", "darkgreen")) +
  
  # El símbolo de ~ significa "por", así que estás ahora creando un panel por cada valor único (o categoría) en la columna dataset
  facet_wrap(~ dataset, nrow = 2, strip.position = "left") +
  
  # Añade los eventos de pose
  geom_segment(
    data = rfid_perch,
    aes(x = perching_start, xend = perching_end, y = 1.2, yend = 1.5),
    color = "blue",
    linewidth = 0.3
  ) +
  
  theme(
    legend.position = "top"
  )

gg

```

Ahora puedes hacer ajustes menores para seguir mejorando la gráfica, incluyendo cambiar los títulos de los ejes para que sean más informativos, cambiar el color de fondo a blanco, y eliminar el texto en el eje "y" así como las líneas en el eje "y", porque este eje no contiene información para interpretación de los datos (o sea, la altura de cada línea no contiene información para interpretación).
```{r}

gg <- gg +
  
  # Cambia los títulos de ambos ejes
  xlab("Date and time") +
  
  # El eje "y" no contiene información y por ende puedes eliminar este título
  ylab("") +
  
  # Usa esta función para cambiar el color de fondo a blanco y negro
  theme_bw() +
  
  # Usa funciones de estética para eliminar el texto en el eje "y" y también las líneas en este eje
  theme(
    axis.text.y = element_blank(),
    axis.ticks.y = element_blank(),
    legend.position = "top"
  )

gg

```

Puedes guardar las gráficas que creas en R como archivos físicos. Abajo usarás la función `ggsave()` para escribir la gráfica que hiciste arriba y guardarlo en tu computadora.
```{r}

gg

# Guarda la gráfica como un archivo en tu computadora
ggsave(file.path(path, "raw_processed_perching.tiff"), width = 8, height = 6, units = "in", dpi = 300)

```

Puedes continuar con modificaciones a este archivo para crear una figura de alta calidad para una publicación. Por ejemplo, puedes cambiar el tamaño final del archivo (`width` o "el ancho", `height` o "la altura"), así como también la resolución en píxeles (`dpi`). Incluso puedes cambiar el tamaño de texto en cada eje o del título de cada eje, o la posición de la leyenda mientras determinas el tamaño final de la imagen.

En el siguiente tutorial vas a continuar analizando datos con ABISSMAL y vas a crear una gráfica de barras más compleja y refinada.

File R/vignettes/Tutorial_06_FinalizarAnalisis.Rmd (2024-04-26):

---
title: "Tutorial 06: Finalizar Los Analisis"
author: "Grace Smith-Vidaurre"
date: "2023-12-27"
output: 
  html_document:
    css: "styles.css"
    toc: true
    toc_float: true
    toc_depth: 4
---

```{r setup, include = FALSE}

knitr::opts_chunk$set(echo = TRUE, eval = TRUE)

```

<h2>Información sobre esta traducción</h2>

Este tutorial fue traducido al español por Grace Smith-Vidaurre y editado por Tania Molina, siguiendo las [convenciones de traducción de los Carpentries](https://github.com/Carpentries-ES/board/blob/master/Convenciones_Traduccion.md), incluyendo usar el género femenino por defecto. Si encuentras errores de ortografía que impiden tu habilidad de completar los tutoriales, por favor reporta los errores de ortografía a GitHub usando los pasos en el primer tutorial para reportar un "Issue".

<h2>Resumen del tutorial y objetivos de aprendizaje</h2>

En este sexto y último tutorial, vas a terminar de usar las detecciones simuladas de movimientos de animales en el `pipeline` de procesar y analizar datos de ABISSMAL. Vas a detectar `clusters` ("cúmulos") de detecciones que representan eventos de movimientos distintos y luego vas a anotar inferencias de comportamiento de estos eventos de movimiento. También vas a crear gráficas para visualizar las inferencias de comportamiento. Vas a continuar a usar habilidades que aprendiste en los tutoriales anteriores, y también vas a aprender cómo crear visualizaciones más complejas con `ggplot()`.

<h2>Cargar paquetes e inicializar el `path` de tu directorio de trabajo</h2>

```{r message = FALSE, warning = FALSE}

rm(list = ls()) # Limpia tu ambiente global

library(tidyverse) # Carga la colección de paquetes del tidyverse
library(data.table) # Carga otros paquetes requeridos por las funciones de ABISSMAL

path <- "/home/gsvidaurre/Desktop/ABISSMAL_vignettes" # Inicializa un objeto con el path de tu directorio de trabajo

```

<h2>Cargar funciones de ABISSMAL</h2>

```{r}

# Carga la función que detecta clusters en los datos procesados
source("/home/gsvidaurre/Desktop/GitHub_repos/ABISSMAL/R/detect_clusters.R")

# Carga la función que anota inferencias de comportamiento sobre los clusters
source("/home/gsvidaurre/Desktop/GitHub_repos/ABISSMAL/R/score_clusters.R")

# Carga un archivo con funciones de apoyo que cada función de arriba requiera
source("/home/gsvidaurre/Desktop/GitHub_repos/ABISSMAL/R/utilities.R")

```

<h2>Termina el `pipeline` de ABISSMAL</h2>

Aquí usarás la función de ABISSMAL que se llama `detect_clusters()` para identificar `clusters` de detecciones a través de los tipos de sensores (detecciones de diferentes sensores que fueron grabados juntos en el tiempo).
```{r}

# El argumento run_length, o lo largo de cada serie de detecciones que ocurrieron juntos en el tiempo (cluster) tiene que ser 1 para poder detectar clusters con un largo de 2 detecciones
detect_clusters(file_nms = c("pre_processed_data_RFID.csv", "pre_processed_data_IRBB.csv"), threshold = 2, run_length = 1, sensor_id_col_nm = "sensor_id", timestamps_col_nm = "timestamp_ms", PIT_tag_col_nm = "PIT_tag", rfid_label = "RFID", preproc_metadata_col_nms = c("thin_threshold_s", "data_stage", "date_pre_processed"), general_metadata_col_nms = c("chamber_id", "year", "month", "day"), path = path, data_dir = "Data/processed", out_dir = "Data/processed", out_file_nm = "detection_clusters.csv", tz = "America/New York", POSIXct_format = "%Y-%m-%d %H:%M:%OS")

```

Luego vas a anotar inferencias de comportamiento de estos `clusters` de detecciones con la función `score_clusters()`.
```{r}

score_clusters(file_nm = "detection_clusters.csv", rfid_label = "RFID", camera_label = NULL, outer_irbb_label = "Outer Beam Breakers", inner_irbb_label = "Inner Beam Breakers", video_metadata_col_nms = NULL, integrate_perching = TRUE, perching_dataset = "RFID", perching_prefix = "perching_events_", sensor_id_col_nm = "sensor_id", PIT_tag_col_nm = "PIT_tag", pixel_col_nm = NULL, video_width = NULL, video_height = NULL, integrate_preproc_video = FALSE, video_file_nm = NULL, timestamps_col_nm = NULL, path = path, data_dir = "Data/processed", out_dir = "Data/processed", out_file_nm = "scored_detectionClusters.csv", tz = "America/New York", POSIXct_format = "%Y-%m-%d %H:%M:%OS")

```

<h2>Revisa los resultados finales</h2>

Puedes revisar los resultados finales ahora que terminaste de ejecutar el `pipeline` de ABISSMAl para detectar `clusters` y generar inferencias de comportamiento.
```{r}

scored_clusters <- read.csv(file.path(path, "Data/processed", "scored_detectionClusters.csv")) %>% 
   # Tienes que convertir las marcas de tiempo al formato POSIX cada vez que los datos se leen a R para hacer gráficas
  dplyr::mutate(
    start = as.POSIXct(format(as.POSIXct(start, tz = "America/New York"), "%Y-%m-%d %H:%M:%OS6")),
    end = as.POSIXct(format(as.POSIXct(end, tz = "America/New York"), "%Y-%m-%d %H:%M:%OS6"))
  ) %>%
  # Ordena las marcas de tiempo
  dplyr::arrange(-desc(start))

glimpse(scored_clusters)

```

Cuántos eventos de entrada y salida se anotaron por día?

<h2>Datos ausentes en R</h2>

Para poder contar la cantidad de cada uno de estos eventos que ABISSMAL anotó por día, necesitas saber cómo manejar datos ausentes en R. Los datos ausentes se suelen representar usando el valor `NA` ("not available" o "no disponible"), que es un tipo de dato específico en R. Puedes determinar si un vector (o una columna en un `dataframe`) contiene datos ausentes si usas la función `is.na()`, que devolverá `TRUE` cuando encuentra un valor de `NA` (un valor ausente) en el vector actual.
```{r}

?is.na()

x <- c(1, NA, 2, 3, NA)

is.na(x)

```

En el código de arriba, creaste un vector que se llama `x` que tiene dos valores de `NA`. La función `is.na()` revisa si cada elemento de `x` es equivalente a `NA`, y devuelve `TRUE` cuando se cumple esa condición (o sea, cuando encuentra un dato ausente).

Como `is.na()` es una frase condicional, también puedes usar otros símbolos especiales que son relevantes para las frases condicionales, como el símbolo de `!`, que sirve para invertir una frase condicional. Por ejemplo, en el código de abajo, cuando añades `!` antes de `is.na()`, estás preguntando si cada elemento de `x` *no* es equivalente a `NA`:
```{r}

!is.na(x)

```

Como puedes ver, añadir el `!` en frente del `is.na()` resulta en valores binarios invertidos comparado con usar solo `is.na()`, y ahora cada valor que antes era `TRUE` se convirtió en `FALSE`. A la par, la habilidad de invertir la frase condicional de `is.na()`, y el resultado binario que devuelve `is.na()` son propiedades muy útiles para encontrar y filtrar las filas de un `dataframe`.

Por ejemplo, la función `dplyr::filter()` eliminará una fila cada vez que encuentra un valor de `FALSE` en la columna actual y en cambio, no eliminará una fila cada vez que encuentra un valor de `TRUE`. O sea, si quieres eliminar files que contienen valores de `NA` para una columna actual, añadirías `!is.na(name_of_column)` adentro de `dplyr::filter()`, que debería de devolver `FALSE` cada vez que encuentra una fila con `NA`, y eliminará esa fila como parte de la operación de filtrar.

<h2>Contar eventos por día</h2>

Ahora puedes escribir código para contar el número de eventos de entrada y de salida que ABISSMAL anotó por día. Vas a necesitar 1) crear una columna nueva con la información sobre el día para cada marca de tiempo, 2) eliminar filas con datos ausentes para la información anotada de la dirección del movimiento (la columna `direction_scored`, porque esta información no se puede anotar para algunos movimientos), 3) agrupar el `dataframe` por día y por la dirección anotada, y luego 4) contar el número de filas por grupo.
```{r}

scored_clusters %>%
  # Extrae el día de cada marca de tiempo y crea una columna nueva con esta información
  dplyr::mutate(
    day = lubridate::day(start)
  ) %>%
  # Aquí estas usando la función is.na() que devolverá TRUE cuando encuentra un valor ausente (NA) en la columna actual. Colocando el símbolo de ! antes de is.na(), estás invirtiendo la frase condicional y también el resultado, así que todos los valores TRUE se convertirán a FALSE. Por ende, dplyr::filter eliminará todas las filas que devuelven el valor de FALSE en esta expresión (o sea, todas las filas con valores ausentes en la columna direction_scored con información sobre la dirección anotada de movimiento)
  dplyr::filter(!is.na(direction_scored)) %>%
  # Agrupa el dataframe de ambas columnas para las cuales quieres contar filas (eventos). Aquí quieres saber el número de entradas y salidas (categorías en la columna direction_scored) por día (categorías en la columna "day")
  group_by(day, direction_scored) %>%
  # Luego puedes resumir los datos. El número de filas aquí es el número de entradas o salidas anotadas por día
  dplyr::summarise(
    n = n()
  )

```

Cuatro entradas y salidas se anotaron por día. Cómo se compara este resultado con el número de entradas y salidas que esperabas por día? Si regresas a los tutoriales anteriores (el tercer y el cuarto tutorial) donde creaste los datos originales simulados, deberías de poder ver que empezaste por simular dos entradas y dos salidas por día en los datos para el sistema de RFID y los sensores de infrarrojo. Luego añadiste dos entradas y dos salidas más por día cuando simulaste fallas de detección del sistema de RFID (es decir, estos fueron movimientos capturados solamente por los sensores infrarrojo). `score_clusters` detectó el número correcto de entradas y salidas por día.

Ahora puedes revisar los eventos de pose, filtrando todas las filas que no se anotaron como eventos de pose (o sea, filas con valores de `NA` en la columna "perching_PIT_tag" que contiene información sobre las etiquetas de PIT). Luego puedes seleccionar solo las columnas que sí contienen información que es útil revisar, como las identidades de las etiquetas PIT, y también las marcas de tiempo para el inicio y fin de cada pose.
```{r}

scored_clusters %>%
  # Usa una frase condicional con is.na() para retener solo las filas que tienen códigos de etiquetas PIT que fueron asociados con eventos de posar
  dplyr::filter(!is.na(perching_PIT_tag)) %>%
  # Luego selecciona solo las columnas que quieres revisar visualmente
  dplyr::select(start, end, perching_PIT_tag)

```

Como aprendiste en el tercer y el cuarto tutorial, el primer evento de pose por día se realizó por el primer individuo (con la etiqueta de PIT "1357aabbcc"), y el segundo evento de pose por día fue realizado por el segundo individuo (con la etiqueta de PIT "2468zzyyxx").

Cuántos eventos de movimiento que no fueron eventos de pose fueron asignados a cada individuo?
```{r}

scored_clusters %>%
  # Extrae el día de cada marca de tiempo y crea una columna nueva con esta información
  dplyr::mutate(
    day = lubridate::day(start)
  ) %>%
  # Usa una frase condicional con is.na() para retener solo las filas que tienen códigos de las etiquetas de PIT que no fueron asociados con eventos de pose
  # Aquí estás combinando dos frases condicionales para poder buscar filas en la columna individual_initiated (el individuo que inició el movimiento) que tienen códigos de etiquetas PIT, pero que también no tienen una etiqueta de sensor en la columna perching_sensor (o sea, eventos de movimiento que no fueron eventos de pose, sino entradas o salidas)
  dplyr::filter(!is.na(individual_initiated) & is.na(perching_sensor)) %>%
  group_by(day, individual_initiated) %>% 
  dplyr::summarise(
    n = n()
  )

```

Como puedes ver, cuatro eventos de movimiento que no fueron eventos de pose se asignaron al primer individuo (con la etiqueta PIT "1357aabbcc") en cada día, que es exactamente lo que simulaste en el tercer y el cuarto tutorial. Más movimientos que no fueron eventos de pose se detectaron a través de estos días también, pero como esos eventos no fueron capturados por la antena de RFID (o sea fueron fallas simuladas de la antena de RFID), estos movimientos fueron capturados por sólo los sensores infrarrojo que no pueden grabar información sobre la identidad de los individuos.

<h2>Construye una gráfica de barras compleja</h2>

Ahora puedes visualizar los resultados finales. En el código de abajo vas a aprender cómo crear una gráfica de barras que es más compleja de lo que viste en el tutorial anterior, pero que será más fácil de interpretar. Para esta gráfica sería útil poder visualizar tres tipos de inferencias de comportamiento o tipos de información a través del tiempo: la dirección de movimiento (cuando esté disponible), la identidad del individuo (cuando esté disponible), y los eventos de posar.

Puedes empezar con construir la gráfica añadiendo líneas verticales para los eventos que no fueron eventos de pose. El color de cada línea indicará la identidad del individuo, incluyendo cuando la información no estaba disponible. El tipo de línea va a contener información sobre la dirección de movimiento, y también cuando la información no se pudo anotar.

Para poder asignar colores y tipos de líneas de la forma que quieres en la gráfica, vas a necesitar modificar el `dataframe` de los resultados finales para convertir los `NAs` en las dos columnas asociadas con estos detalles de estética para convertir los datos ausentes en información útil. Por ejemplo, cuando no hay información sobre la identidad del individuo, sería muy útil convertir los valores asociados de `NA` a un valor como "unassigned" ("no asignado"). En el código abajo vas a usar la función `is.na()` dentro de frases condicionales de `ifelse()` para convertir los valores de `NA` dentro de las columnas "individual_initiated" y "direction_scored" para poder tener información útil para la gráfica que vas a hacer más adelante.

Primero puedes practicar usar `is.na()` dentro de `ifelse()` para crear un vector nuevo. En el código siguiente, vas a proveer la frase condicional que quieres probar (aquí vas a probar si la columna que contiene las etiquetas PIT del individuo que inició el movimiento tiene valores de `NA`), el valor que quieres añadir al vector si la condición se cumple (el valor "unassigned" cuando no hay información sobre la etiqueta PIT), y luego el valor que quieres añadir si la condición no se cumple (en este caso es devolver la etiqueta PIT en la columna individual_initiated si el valor actual no es `NA`).
```{r}

# is.na() devuelve TRUE cuando encuentra valores de NA adentro de un vector (o columna) y FALSE cuando el valor actual no es NA
is.na(scored_clusters$individual_initiated)
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

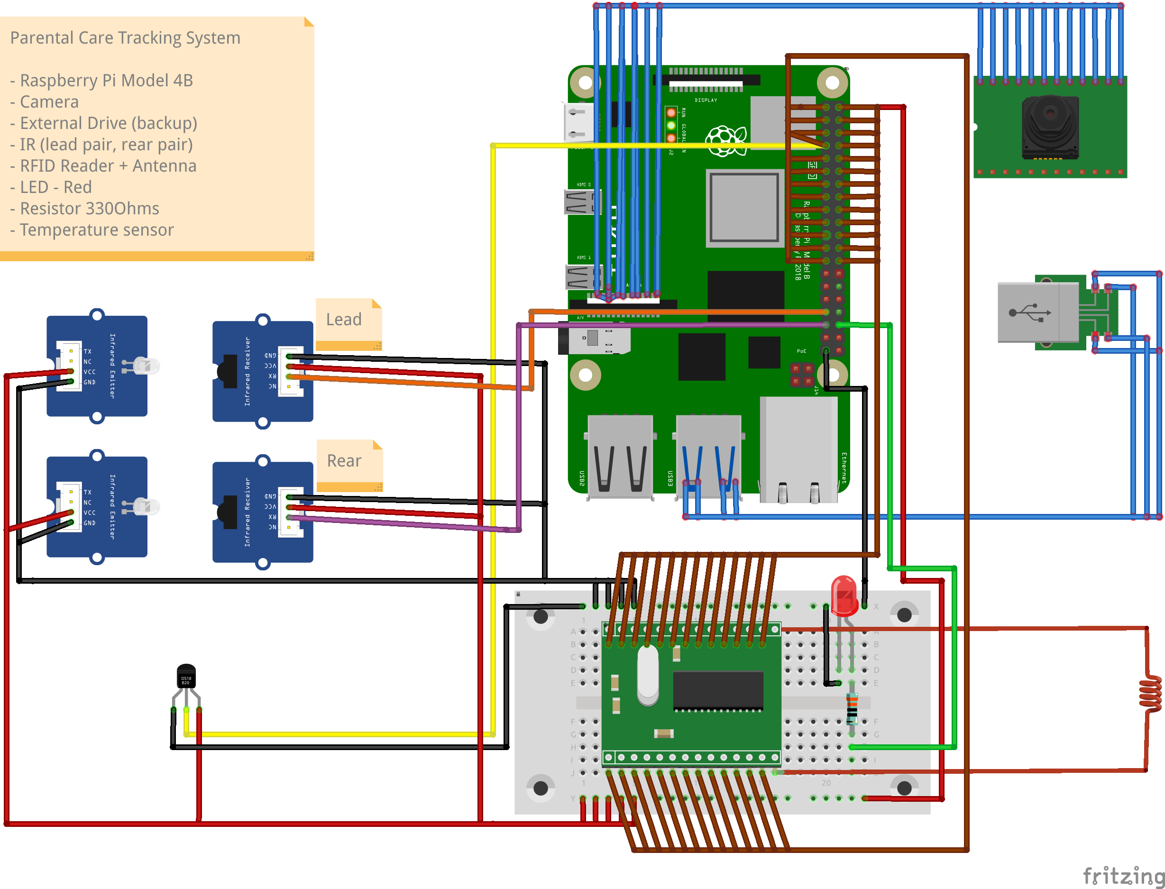
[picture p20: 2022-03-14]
Modules/Schematics/PCT_wiring_diagram.png

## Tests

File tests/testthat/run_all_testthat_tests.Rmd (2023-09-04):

---
title: "Run all testthat tests"
author: "Grace Smith-Vidaurre"
date: "2023-01-05"
output: html_document
---

```{r}

if (!require(testthat)) install.packages('testthat')
library(testthat)

# Run the testthat tests for each function

test_file("/home/gsvidaurre/Desktop/GitHub_repos/Abissmal/tests/testthat/test_find_rfid_perching_events.R")

```

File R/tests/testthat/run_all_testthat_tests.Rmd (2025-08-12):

---
title: "Run all testthat tests"
author: "Grace Smith-Vidaurre"
date: "2023-01-05"
output: html_document
---

See more info on the testthat package: https://r-pkgs.org/testing-basics.html. See examples at: https://www.r-bloggers.com/2019/11/automated-testing-with-testthat-in-practice/.

```{r}

rm(list = ls())

# Install packages unless they already exist on the local machine
is_installed <- function(p) is.element(p, installed.packages()[,1])

# This vector of packages includes those used in the files called below
X <- c("testthat", "tidyverse", "plyr", "dplyr", "lubridate", "pbapply")

# Check that each of these packages is installed, and if not, then install them
invisible(lapply(1:length(X), function(x){
  if(!is_installed(X[x])){
    install.packages(X[x], repos = "http://lib.stat.cmu.edu/R/CRAN")
  }
}))

# Load testthat
library(testthat)

# These paths will need to be changed for different computers and/or users
testing_path <- "/Users/gsvidaurre/Desktop/GitHub_repos/ABISSMAL/R/tests/testthat/"
code_path <- "/Users/gsvidaurre/Desktop/GitHub_repos/ABISSMAL/R/"
testthat_tmp_path <- "/Users/gsvidaurre/Desktop"

# Run the testthat tests for each function
testthat::test_file(file.path(testing_path, "test_combine_raw_data.R"))

testthat::test_file(file.path(testing_path, "test_detect_perching_events.R"))

testthat::test_file(file.path(testing_path, "test_preprocess_detections.R"))

testthat::test_file(file.path(testing_path, "test_detect_clusters.R"))

testthat::test_file(file.path(testing_path, "test_score_clusters.R"))

```

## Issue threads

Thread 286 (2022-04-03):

[NEW] Setup macmini as local server to communicate with all boxes

lastralab, 2022-04-03:
**Is your feature request related to a problem? Please describe.**
SSH access to raspberry pis would be more secure if we limit the boxes to use the mac mini shared internet and we use as a bridge

**Describe the solution**
Setup the macmini which will be the only door to communicate with the boxes.

Closed 2024-09-11.

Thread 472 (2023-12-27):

[NEW] R coding and video tutorials

gsvidaurre, 2023-12-27:
Make short R coding tutorials (English and Spanish) along with videos if possible. Also consider adding videos of basic ABISSMAL setup

gsvidaurre, 2024-03-21:
From #473:

All R code that calls the functions need to be modified to specify the new repository name. Also, I found a bug in preprocess_detections while working on the tutorials with simulated data. It appears that the detections aren't being filtered out correctly. I need to find out why and also check why the unit tests didn't catch this bug before

The only difference I can find between the simulated datasets for the tutorials and those for the unit testing are that the former end on an odd numbered timestamp and the latter end on an even number. So the logic inside preprocess_detections() works for series of timestamps that end in even numbers but not for those that end with odd numbers. Need to fix the logic and add more simulated data that end in odd numbered timestamps to the unit tests

gsvidaurre, 2024-03-21:
I checked the code inside preprocess_detections() and checked the output from data processing in the vignettes, and everything looks as expected. I was imagining the bug in data processing. Also, the unit tests for preprocess_detections() are generally written with an odd-numbered series of timestamps. I added another unit test with an even-numbered series of timestamps, and that test passed as well.

gsvidaurre, 2024-03-21:
Just updated the repo name to be capitalized in all unit test files

gsvidaurre, 2024-03-25:
For Spanish translations I plan to follow the Carpentries translation guidelines: https://github.com/Carpentries-ES/board/blob/master/Convenciones_Traduccion.md, including their guidelines for technical terms. See the Carpentries GitHub page for Spanish translations they have done: https://github.com/Carpentries-ES. Also see Glosario, their multi-language collection of technical terms: https://carpentries.org/blog/2020/07/announcing-glosario/ that is available as a package for inserting glossary links for learning more about specific data science terms

lastralab, 2024-04-26:
Merged Vignettes and Tutorials

Closed 2024-04-26.

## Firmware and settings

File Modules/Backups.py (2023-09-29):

# Created by PyCharm
# Author: tanismo
# Project: Abissmal
# Date: 1/12/22

# !/usr/bin/env python3
import datetime
import sys
from helper import dir_setup
from helper import box_id
from helper import modules
from helper import video_extension
from helper import file_extension
from helper import sms_alert
import os
from datetime import *
import shutil
import time
from helper import get_logger
import subprocess
import re

pi_home = '/home/pi/'
dir_setup(pi_home)

backup_hour = 20
backup_minute = 15
low_storage = 200
media_path = '/media/pi/'
data_path = pi_home + 'Data_Abissmal/'
log_path = '/home/pi/log/'
volume_id = ''
logging = get_logger(datetime.today())

logging.info('Started backup script')
print('Started backup script')

logging.info('Data transfer will run once every day at ' + str(backup_hour) + ':' + str(backup_minute) + 'hrs')
print('Data transfer will run once every day at ' + str(backup_hour) + ':' + str(backup_minute) + 'hrs')
logging.info('Logs transfer will run once at 0:00hrs every day')
print('Logs transfer will run once at 0:00hrs every day')


def usb_connected():
    if len(os.listdir(media_path)) > 0:
        global volume_id
        for volume in os.listdir(media_path):
            if len(os.listdir(media_path + volume)) > 0:
                volume_id = str(volume)
                return True
            pass
        pass
    else:
        exception = 'External drive not detected, backup won\'t be possible.'
        print('Backups error: ' + exception)
        logging.error('Backups error: ' + exception)
        sms_alert('Backups', 'Error: ' + exception)


def video_backup_init(yesterday, destination, source):
    src = source + 'Video'
    today = datetime.now().strftime("%Y_%m_%d")
    path = destination + '/Data/Video/' + yesterday
    files = os.listdir(src)
    if len(files) > 0:
        videos = 0
        if not os.path.exists(path):
            os.makedirs(path)
        for filename in files:
            if filename.endswith(video_extension):
                if yesterday in filename:
                    shutil.move(os.path.join(src, filename), os.path.join(path, filename))
                    print('Backed-up video ' + filename)
                    videos = videos + 1
                else:
                    index = filename.find(box_id + '_') + len(box_id + '_')
                    older = filename[index:index + 10]
                    if older == today:
                        pass
                    else:
                        path = destination + '/Data/Video/' + older
                        if not os.path.exists(path):
                            os.makedirs(path)
                        shutil.move(os.path.join(src, filename), os.path.join(path, filename))
                        print('Backed-up older video ' + filename)
                        videos = videos + 1
            else:
                pass
        print('Backed-up ' + str(videos) + ' videos')
        logging.info('Backed-up ' + str(videos) + ' videos')
    else:
        print('No videos backed-up. No files found')
        logging.error('No videos backed-up. No files found. Check camera/video module.')
        sms_alert('Backup', 'No videos backed-up. Check camera/video module. No files found in source: ' + source)
        pass


def csv_backup_init(today, destination, source):
    today_string = today.strftime("%Y_%m_%d")
    for module in modules:
        src = source + module
        files = os.listdir(src)
        today_file = module + '_' + box_id + "_" + today_string + ".csv"
        path = destination + '/Data/' + module + '/'
        if len(files) > 0:
            if not os.path.exists(path):
                os.makedirs(path)
            for filename in files:
                if filename.endswith(file_extension):
                    if filename != today_file:
                        shutil.move(os.path.join(src, filename), os.path.join(path, filename))
                    else:
                        pass
                else:
                    pass
            print('Backed-up ' + module + ' metadata')
            logging.info('Backed-up ' + module + ' metadata')
        else:
            print('CSV files not found in module: ' + module + '. Disable this module to stop getting these warnings.')
            logging.warning('Backup: CSV files not found in module: ' + module)
            sms_alert('Backup', 'Warning: CSV files not found in module: ' + module)
            pass


def logs_backup_init(day, destination, source):
    yday = day - timedelta(days=1)
    today = yday.strftime("%Y_%m_%d")
    logs = os.listdir(source)
    if len(logs) > 0:
        logging = get_logger(datetime.today())
        path = destination + '/Data/Logs/'
        today_log = today + '_abissmal_' + box_id + '.log'
        logs_qty = 0
        if not os.path.exists(path):
            os.makedirs(path)
        for log in logs:
            if log.endswith('.log'):
                if not (log == today_log or log == 'abissmal_cron.log'):
                    shutil.move(os.path.join(log_path, log), os.path.join(path, log))
                    logs_qty = logs_qty + 1
                pass
            else:
                print('Backup Warning: .log files not found in source.')
                logging.warning('Backup: .log files not found in source.')
                sms_alert('Backup', 'Warning: .log files not found in source.')
                pass
        print('Backed-up logs: ' + str(logs_qty))
        logging.info('Backed-up logs total: ' + str(logs_qty))
    else:
        logging = get_logger(datetime.today())
        print('Backup Error: Empty Log dir: /home/pi/log/')
        logging.error('Backup: Empty Log dir /home/pi/log/')
        sms_alert('Backup', 'Error: Empty Log directory /home/pi/log/')
        pass


def monitor_storage(path):
    logging = get_logger(datetime.today())
    output = subprocess.check_output('df -h --output=avail ' + path + ' | grep -v Avail', shell=True, text=True)
    gigs = int(''.join(re.findall('[0-9]', output)))
    if gigs <= low_storage:
        msg = 'Warning: External drive available space is lower than ' + str(low_storage) + 'G. Needs to be empty soon.'
        sms_alert('Backup', msg)
        logging.error(msg)
    else:
        logging.info('Storage Monitor: Total space available in external drive: ' + str(gigs) + 'G')
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

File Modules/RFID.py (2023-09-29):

# Created by PyCharm
# Author: tanismo, gsvidaurre
# Project: Abissmal
# Date: 11/13/21

# !/usr/bin/env python3

import wiringpi as wiringpi2
import time
import sys
from datetime import datetime
import csv
from helper import dir_setup
from helper import csv_writer
from helper import box_id
from helper import sms_alert
from time import sleep
from helper import get_logger

dir_setup("/home/pi/")

warn = 0
module = 'RFID'
header = ['chamber_id', 'sensor_id', 'year', 'month', 'day', 'timestamp', 'PIT_tag_ID']
rfid_data = "/home/pi/Data_Abissmal/RFID"
logging = get_logger(datetime.today())
logging.info('Started RFID script')
GPIO_PIN = 1


def WaitForCTS():
    while wiringpi2.digitalRead(GPIO_PIN):
        time.sleep(0.01)
    return


def RFIDSetup():
    response = wiringpi2.wiringPiSetup()
    wiringpi2.pinMode(GPIO_PIN, 0)
    fd = wiringpi2.serialOpen('/dev/serial0', 9600)
    wiringpi2.serialFlush(fd)
    if response != 0 and fd <= 0:
        print("Unable to Setup communications")
        logging.error("RFID Error: Unable to Setup communications")
        sms_alert('RFID', 'Error: Unable to setup communications')
        sys.exit()
    return fd


def SetReaderMode(fd):
    WaitForCTS()
    wiringpi2.serialPutchar(fd, 0x76)
    wiringpi2.serialPutchar(fd, 0x03)


def SetPollingDelay(fd):
    WaitForCTS()
    wiringpi2.serialPutchar(fd, 0x50)
    wiringpi2.serialPutchar(fd, 0x60)


def ReadText(fd):
    response = ""
    i = 1
    while i <= 5:
        temp = format(wiringpi2.serialGetchar(fd), 'x').upper()
        if len(temp) == 1:
            temp = '0' + temp
        if i <= 4:
            temp = temp + "-"
        response = response + temp
        i = i + 1
    return response


def ReadInt(fd):
    qtydata = wiringpi2.serialDataAvail(fd)
    response = 0
    if qtydata > 0:
        response = wiringpi2.serialGetchar(fd)
    return response


def ReadTagPageZero(fd):
    try:
        while True:
            WaitForCTS()
            wiringpi2.serialPutchar(fd, 0x52)
            wiringpi2.serialPutchar(fd, 0x00)
            ans = ReadInt(fd)
            time.sleep(0.1)
            if ans == int("0xD6", 16):
                ans = ReadText(fd)
                dt = datetime.now()
                logging.info('RFID read proximity: ' + ans)
                print('RFID activity detected')
                csv_writer(
                    str(box_id),
                    module,
                    rfid_data,
                    str(dt.strftime("%Y_%m_%d")),
                    header,
                    [
                        box_id,
                        'RFID',
                        dt.strftime("%Y"),
                        dt.strftime("%m"),
                        dt.strftime("%d"),
                        f"{dt:%H:%M:%S.%f}",
                        ans
                    ]
                )
                time.sleep(1)
    except KeyboardInterrupt:
        logging.info('Exiting RFID')
        print('Exiting RFID')
    except Exception as E:
        logging.error('RFID error: ' + str(E))
        print('RFID error: ' + str(E))
        sms_alert('RFID', 'Error: ' + str(E))


comms = RFIDSetup()
SetReaderMode(comms)
SetPollingDelay(comms)
ReadTagPageZero(comms)

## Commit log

2021-11-12 [PCT-17] Added code for temperature sensor
2021-11-13 Data and device descriptions
    Added details about device, code, and desired data
2021-11-13 Data and description
    Details about device, notes on usage, and desired data
2021-11-29 [PCT-19] threading demo
2021-11-29 [PCT-19] threading irbb demo
2021-11-29 [PCT-19] threading irbb is_alive test
2021-12-08 [PCT-20] Fixed .csv writer but callback function for IRBB is not working and neither is logging generally
    [helper.py]
2021-12-08 [PCT-20] adding missing files
    [IRBB.py]
2021-12-08 [PCT-20] commented previous lines and added possible fix on top
    [IRBB.py]
2021-12-09 [PCT-20] Updated callback function to account for more than one IRBB sensor id
2021-12-10 [PCT-20]Fixed while loop and works with Main.sh; notes in Main.sh for next steps
    [IRBB.py]
2021-12-13 [PCT-17] Temperature sensor code working, writes to .csv and log file
2021-12-13 [PCT-16] Code to track RFID events is working, writes to both csv and log files
2021-12-14 [PCT-18] Updating code for video; still needs changes to avoid recording during or shortly after another video
    [IRBB.py]
2021-12-15 [PCT-19] added board url to readme
2021-12-21 [PCT-18] video using LED
2021-12-21 [PCT-18] set led pin to 12
2021-12-21 [PCT-18] corrected method call LOW
    [IRBB.py]
2021-12-21 [PCT-18] corrected method call
    [IRBB.py]
2021-12-21 [PCT-18] video input pin
2021-12-21 [PCT-18] sensor id to log
2021-12-21 [PCT-18] video not working in a loop
    [IRBB.py, Video.py]
2021-12-21 [PCT-18] trying to run video + led in a loop
2022-01-04 [PCT-18] video working with IRBB, needs cleaning up and LED code
2022-01-04 [PCT-staging] Fixed and re-tested IRBB and video code only
    [IRBB.py, Video.py]
2022-01-04 [PCT-staging] LED turns on when video is recording
2022-01-04 [PCT-19] refactor main, added troubleshooting LED
2022-01-12 [PCT-18] Added Video .csv; updating code to combine and convert videos; still getting ffmpeg error
    [IRBB.py, Video.py]
2022-01-14 [PCT-18] Tested motion detection video code with all other 3 devices (IRBB, RFID, temperature) and it works well. No video concatenation here
2022-01-17 [PCT-59] added stl and gcode for nest entrance model
    [nest_entrance_inverted.stl]
2022-01-19 [PCT-33] Removed extra slashes; fixed object names; added code to remove .h264 files that represent incomplete videos
    [Backups.py, Video.py]
2022-01-19 [PCT-68] fixing video screen
    [Video.py]
2022-01-25 [PCT-29] handled exceptions to send errors via email
    [Backups.py, IRBB.py, RFID.py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]
2022-01-25 [PCT-29] log error if email is not configured
    [helper.py]
2022-02-02 [PCT-76] updated backups to fix exception
    [Backups.py]
2022-02-02 Merge pull request #83
    * [PCT-76] updated backups to fix exception
    * Merge branch 'staging' of https://github.com/lastralab/ParentalCareTr…
    [Backups.py]
2022-02-02 [PCT-76] fixed several emails sent
    [Backups.py]
2022-02-13 [PCT-62] added stl files
    [antenna_cover.stl, cam_holder.stl]
2022-02-16 [PCT-62] updated cam_holder model
    [cam_holder.stl]
2022-02-16 [PCT-62] updated cam_holder to mm
    [cam_holder.stl]
2022-02-20 [PCT-102] removing camera.stop and camera.stop from finally clause
2022-02-20 [PCT-103] trying to fix errors
    [Backups.py, IRBB.py, RFID.py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]
2022-02-20 [PCT-103] fixing monitor screen
    [monitor.py]
2022-02-20 [PCT-103] trying to fix monitor
    [monitor.py]
2022-02-20 [PCT-103] monitor fixed, fixing error log
    [Temp.py, helper.py]
2022-02-20 [PCT-117] camera setup
2022-02-23 [PCT-127] Fixed backups and video
    [Backups.py, Video.py]
2022-02-23 [PCT-147] added antenna cover cap stl file
    [antenna_cover_cap.stl]
2022-02-23 [PCT-127] fixed several logs from backup
    [Backups.py]
2022-02-23 [PCT-127] refactor video error handling
    [Video.py]
2022-02-23 [PCT-127] refactor error handling
    [RFID.py, Temp.py, Video.py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]
2022-02-25 [PCT-169] added camera.close() to finally statement
2022-02-25 [PCT-169] changed log message added traceback
2022-02-25 [PCT-169] changed log message removed traceback
2022-02-26 [PCT-127] fixed name convention
    [helper.py, log.py]
2022-02-26 [PCT-127] corrected helper logging
    [helper.py]
2022-02-28 [PCT-127] not fixed video
    [Video.py, log.py]
2022-03-12 [staging-PCT-202] permission issues logging as pi
    [Backups.py]
2022-03-15 [staging] temp refactored log for temperature in celsius and fahrenheit
2022-03-27 [PCT-265] fix Temp error: list index out of range
    [Temp.py]
2022-03-27 [PCT-265] print N/A in CSV file if temperature not read
2022-03-27 [PCT-265] Send email alert if temperature sensor not reading temperature
2022-03-30 [PCT-265] set camera motion sensitivity to 18000
2022-03-30 [PCT-207] readme mount ED
2022-04-29 [PCT-285] included IR camera holder designs and updated readme
    [ir_cam_holder.stl, ir_camera_holder_with_holes.stl]
2022-06-03 [PCT-308] Beam breakers support ready to print
    [IRBB.stl]
2022-10-23 Adding a new column to the .csvs
    A sensor ID column. Also updated beam breaker labels
2022-11-01 LED programming
    Updated the code so that the LED should turn on only during the diurnal period
2022-11-02 finished testing issue #318
    [RFID.py, Video.py, helper.py]
2022-11-02 Revert "finished testing issue #318" due to including files that are not relevant.
    This reverts commit 39871f2a2464fdd05b11f024857559e5edb0bd01.
    [RFID.py, Video.py, helper.py]
2022-11-18 [PCT-329] fixed duplicate videos and streaming at the beginning
    [Video.py]
2022-11-21 [PCT-329] fixed duplicate videos for real
    [Video.py]
2022-12-15 PCT-312: Added a new .csv file to store motion detection metdata, issue #312
    [Video.py]
2022-12-30 [PCT-364] changed brightness of rec led
2022-12-30 [PCT-365] fixed backups.py to use any volume name in /media/pi/
    [Backups.py]
2022-12-30 Revert "[PCT-365] fixed backups.py to use any volume name in /media/pi/"
    This reverts commit 611af7482679cbff4446ff46c4655da43d5b4d09.
    [Backups.py]
2022-12-30 [PCT-335] fixed run_install to enable SMS
    [helper.py]
2022-12-30 [PCT-335] fixed error: name 'sms_alert' is not defined
    [monitor.py]
2022-12-30 [PCT-335] fixed error: phone number format
    [helper.py]
2023-01-02 Update monitor.py
    fix array
    [monitor.py]
2023-01-03 [PCT-380] send monitor error alert only once until main.sh is restarted
    [monitor.py]
2023-01-03 [PCT-380] log twilio error only if message not sent
    [helper.py]
2023-01-03 [PCT-380] formatted SMS to: "box_id[module] Error: text"
    [Backups.py, helper.py]
2023-01-29 [PCT-406] updated stl
2023-04-18 [PCT-415] concatenation may not be the problem
    [Video.py]
2023-06-22 [PCT-423] set logger level to INFO to prevent DEBUG lines
    [log.py]
2023-09-04 Made a function to integrate all 3 movement sensors; updating logic of all integration functions
2023-09-04 For functions that calculate time lags for the same sensor, I updated the conditional statement to convert to Boolean values and removed the timestamp index correction
2023-09-04 Working on new scoring function as part of the integration across sensors
2023-09-04 Updated tmp directory removal; adding unit testing of function output with multiple sensors
2023-09-04 Testing function output with all 3 movement sensor types
2023-09-04 Added a test of function output for 2 sensor types over varying thresholds and run_lengths
2023-09-04 Added testing the function output when using 3 sensor types and varying thresholds and run_lengths; fixed a bug when multiple video recording events occurr within a detection cluster
2023-09-04 Fixed a bug in conditional statements that led to dropped columns in the output
2023-09-04 Added a test of function output for directional labeling when 3 sensor types are used as input
2023-09-04 Added a test of function output for 1 sensor type with perching event integration
2023-09-04 Added a function to test output when using 2 sensor types and integrating perching data
2023-09-04 Added a test of function output when 3 sensors are used and RFID perching events are integrated. The latter 2 tests of perching integration were also for RFID data
2023-09-04 Finished building the current round of unit tests for this function
2023-09-04 Finished writing and checking the current round of error handling unit testing for 1 function
2023-09-14 [PCT-437] fixed camera errors
    [alt_video.py]
2023-09-14 [PCT-437] fixed hour limits
    [alt_video.py]
2023-09-14 [PCT-437] fixed hour limits for video.py too
    [Video.py, alt_video.py]
2023-09-14 [PCT-437] added new features from issue's latest comment
    [alt_video.py]
2023-09-14 [PCT-437] simplified led hours option in main.sh
2023-09-14 [PCT-437] fixed multiple logging per minute
    [alt_video.py]
2023-09-14 [PCT-437] configuring cron once and avoid duplicate entries in crontab file
    [alt_video.py]
2023-09-14 [PCT-437] ERROR Video: 'list' object has no attribute 'year'
    [Video.py]
2023-09-14 [PCT-437] replaced nmoltta name
    [Backups.py, IRBB.py, RFID.py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]
2023-09-26 [PCT-454] Removed LED functionality from validation videos as it will not have GPIO configured
2023-09-26 [PCT-454] fixing ERROR Screen not running: video when only validation
    [monitor.py]
2023-09-26 [PCT-454] explaining no sockets found
2023-09-27 [PCT-452] added camera template for autocad and holder for validation camera
    [camera_holder_validation.stl, camera_template.dwg]
2023-09-27 [PCT-452] documentation
    [camera_template.dwg]
2023-09-27 [PCT-452] replaced files, camera didn't fit in previous ones
    [camera_holder_validation.stl, camera_template.dwg]
2023-09-28 [PCT-452] replaced stl, IR leds didn't fit in previous ones
    [camera_holder_validation.stl]
2023-09-28 [PCT-452] replaced dwg, made holes wider
    [camera_template.dwg]
2023-09-28 Add files via upload
    Exception to replace stl file
    [camera_holder_validation.stl]
2023-09-28 [PCT-457] RFID module was not the problem
    [RFID.py]
2023-12-30 [PCT-472]: Integrated data frame creation and writing out files to vignette 04; continue with using combine_raw_data()
2025-02-11 Updates to find full and partial perching events
    Currently a perching event can be matched to multiple separate detections, consider whether this is the expected behavior. If so, then downstream code will need to carefully count unique perching eve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
2025-08-08 [PCT-478] Updated detect_clusters() with same find_indices logic and columns as detect_perching_events()
    Checked the other functions and made very minor changes, no changes to overall logic. I moved find_indices() into utilities.R. I removed all troubleshooting code from score_clusters(). Currently test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
